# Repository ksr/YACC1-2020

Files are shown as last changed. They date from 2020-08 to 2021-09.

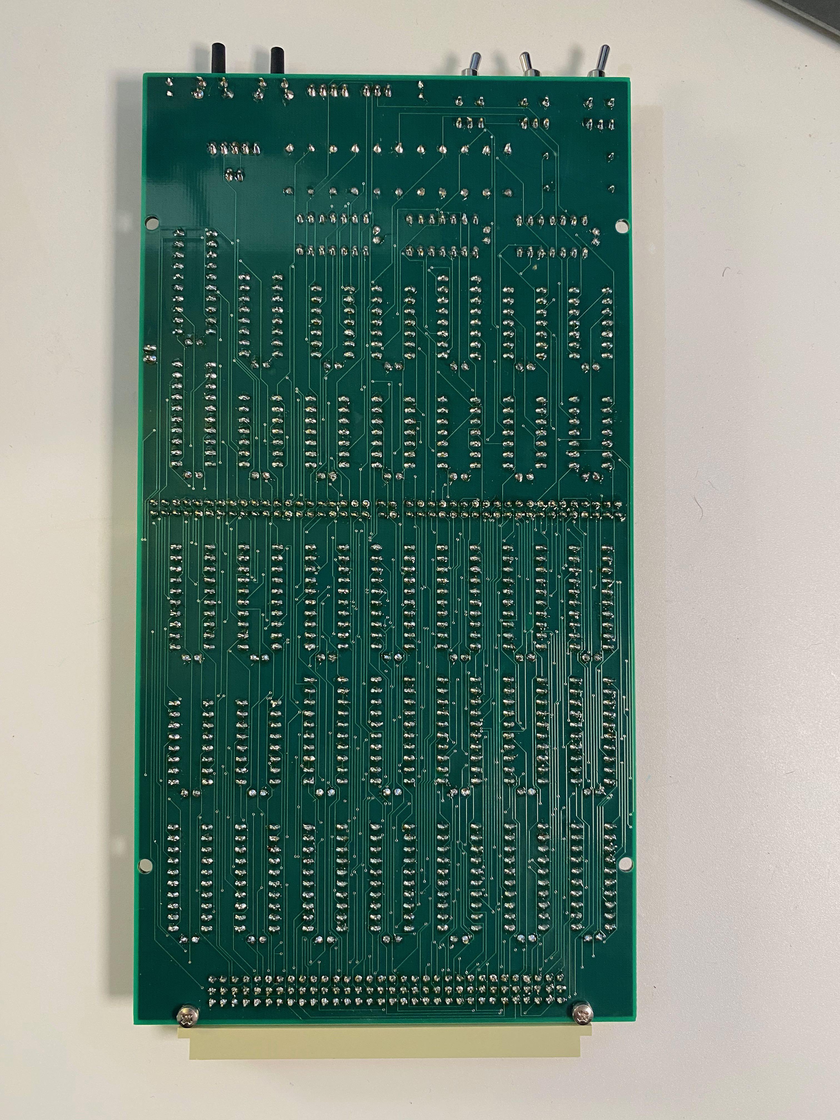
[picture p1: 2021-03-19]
Photos & Videos/sequencer logic v2.1 solder.jpeg

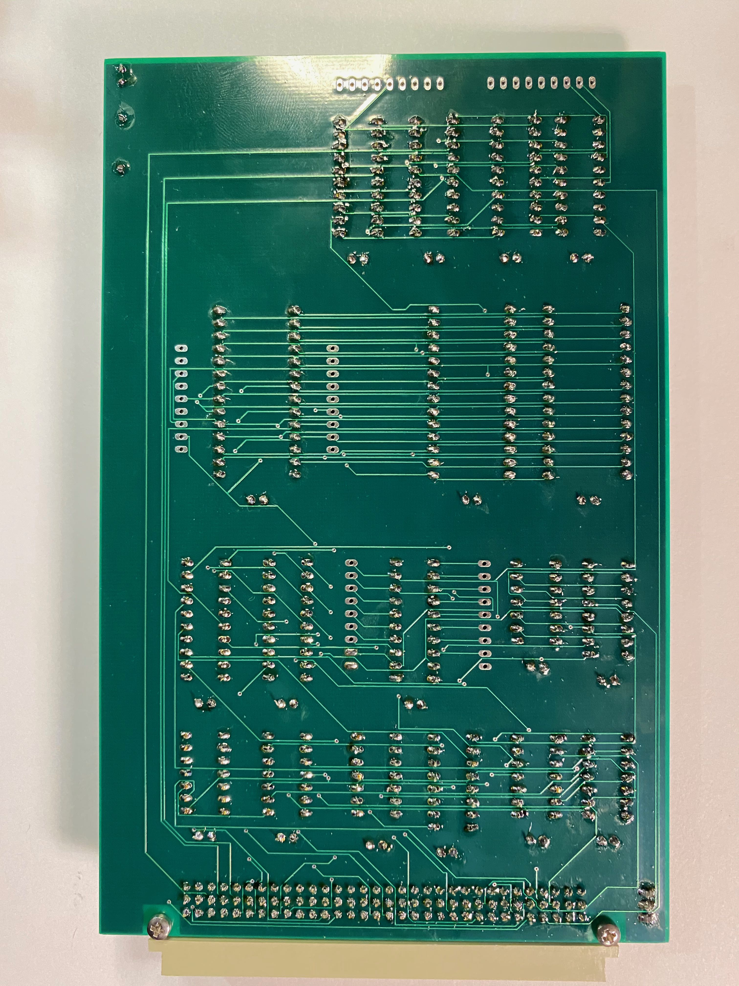
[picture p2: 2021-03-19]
Photos & Videos/memory v1.2 solder.jpeg

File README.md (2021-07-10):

# YACC1-2020 (Yet Another Custom CPU)

Finally time to try building a custom CPU from basic TTL and other "simple" ICs (no 74ls181 ALU, that would be cheating :-) ). 

The YACC1-2020, provides the tools and resources to learn computer science starting from the basics of digital logic through to a fully working custom CPU with a user defined instruction set, assembler, BASIC interpreter, and one day an operating system with filesystem, command line interpreter, and utilities.

The project is currently under development as a personal project. The basic idea has been kicking around inside my head for years (47 years to be exact), but until recently never made it to the top of my list (I did make an attempt a few years back but life got in the way). Now I am exploring if this project might be interesting to others, perhaps as an educational tool or maybe just a fun project.

Here is a [video of the machine in operation](https://youtu.be/6pjIE4_MxIA) and some photos can be found in the Photos & Videos subdirectory in this repository

The basic system is comprised of 7 cards:
- Memory card with 64k RAM and 32K ROM (total address space 64K) The memory card also contains two temporary registers
- Register card, each with 4 16-bit registers that can drive data or address bus, although the system can operate with one register card anything really useful will require two cards. The system has control lines to support upto 4 register cards for a total of 16 registers
- IO Card has serveral options; Serial RS-232, 8-bit switches, 8-bit LED, LCD
- ALU Card supports the boolean, compare, add/sub operations, and the accumulator
- Sequencer 2 card set made up of a memory card and logic card mated together (see photos)
- Optional but highly revommended Bus Test Card, this allows driving the bus in test mode and monitoring the bus in listening mode

## Motivation

Like many others, back in the mid 1970s I had the opportunity to learn both computer programming and microcomputer hardware simultaneously. For me it all started with programming BASIC on a timeshare HP machine via a terminal and/or optical hollerith cards. My math teacher who also taught computer programming allowed us to use the termoianl if we finished our work early. At home I also dabbled with digital circuits and when Popular Electronics published the COSMAC ELF project I was hooked. Now I wonder if for some students when learning computer science does the hardware seem too much like a magic box.

If this project is of intertest, perhaps your one of the following:<br/>
- High school computer science educators<br/>
- Freshman and sophomore college computer science educators<br/>
- Electronics or Retro computer enthusiast<br/>
- Or just generally interested
	
Please reach out to ken at cottageworker dot com

## Directories

### Data Sheets:
		Useful data sheets, manuals, references.
			(These are all readily available online but if I inadvertently violated copyright
			please let me know and I will remove immediately)

### General Notes:
		System wide notes, more specific notes in various subdirectories
		
### PCB:
		PCB designs, there are two different subdirectories:
			Production: These are the latest fully functioning designs, most likely currently in use
			Working - Underdevelopment: These are the newest versions of the boards in design
		Each board has or will have a "theory of operation" document
			
### Photos & Videos:
		Some sharable files

### Presentations:
		Presentations related to the YACC1-2020 project
		
### Software:
		All software related to the project, see subdirectory for more information
		
### Utilities:
		Arduino: Configuration files for Arduino code
		Clocker: External Arduino based to tool for single step debug operations
		Eagle: Configuration files for Eagle
		Waveforms: Timing diagrams for cpu instructions, probably should move to software area

### YACC1 Connector - V3.2.pdf
		Current bus connector specifications
		
<br/><br/> 
-- Thanks for taking a look --

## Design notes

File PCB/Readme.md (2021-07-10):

# PCB Files

## Production
This are the latest versions of boards ordered. That does not mean they are fully tested and working. See the notes file in each subdirectory for additional status information.

## Working - Under Development
These boards have not been ordered, they are still in a developement phase. See notes file in each subdirectory for addtional informaition

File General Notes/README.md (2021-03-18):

General notes, look in subdirectory of each PCB for board specific notes and
look in software directories for code specific notes

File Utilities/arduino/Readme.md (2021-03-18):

This file needs to placed in Arduino Library Tree

On my mac this is:

~/Documents/Arduino/libraries/YACC

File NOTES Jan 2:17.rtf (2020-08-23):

BUILD NOTES:

BUS

Original
Add method to chain card together at edge using right angle male/female 96 pin DIN connectors
Once old boards on old bus have been updates mount newer bus card on plywood
Add Power supply to plywood
Add on/off switch to above
Maybe add amp meter
Use distribution bus for power (screw terminals)

YACC2020 updates and carry forward
Built “Horizontal and Vertical” bus card connectors
Original Horizontal (Side by Side) Connector had long parallel runs close together causing crosstalk
New board designed with extra separation between traces as well as ground and vcc planes

Side by Side Now mounted on MDF
Use larger and add Power Supply to board
Add switch?
Amp measurement?
Easy access to vcc and gnd for test probes maybe trough screw terminal bus bar
Capacitors to bus boards?

ALU

Original
IC8A CARRY SHIFT Register, should it have a reset capability ?
DONE
connect CLR pin 1 to -RESET?
What about a software reset ability?
Should This be done on add/sub without carry

Any Other Status bits required?
Look at other CPU designs

IC34 Compare register
Remove test for 0 from HI data byte (8-15) and replace with INPUT line from bus
This will allow INPUT signal status line to be same as every other test

SWAP A and B lines into IC43 and IC44
First retest this logic with test card and test vectors

Incorporate existing PCB Mods

YACC2020 updates and carry forward
IC8A now IC9A CARRY SHIFT Register, should it have a reset capability ?
DONE connected CLR pin 1 to -RESET?
What about a software reset ability?
Should This be done on add/sub without carry
Not done, how else could this be achieved

Any Other Status bits required?
Look at other CPU designs

C34 Now IC26 Compare register
Remove test for 0 from HI data byte (8-15) and replace with INPUT line from bus
This will allow INPUT signal status line to be same as every other test
DONE

SWAP A and B lines into IC43 and IC44 now ic35 and IC36
First retest this logic with test card and test vectors
Done
BUT the actual change needed might be have accumulator goes to ic35 & 36 A gates and
BDATA goes to XOR gates ic33 and ic34
Might need to model all this in a simulator

Incorporate existing PCB Mods
No idea, will move forward and debug new model

SEQUENCER LOGIC

Original
IC14 Reuse U-TEST-IN
is soft reset needed or reuse?
sheet 4, cleanup logic now that testin input is gone, use br-cond only
Maybe move HALT and CONTINUE switches to TOP edge

Rename branch register to data immediate and add another 2 x 74374 for add(r?) immediate
clk into new 74374s same as ic26 and 27
output new 74374s to addr lines
Does existing 74374s need separate hi and lo read lines ???
Can one be use for existing 74374s (DATA) and other for new 74374s (ADDR)
Possible methods for I/O ADDR line
1) Reuse testin line and drive either UNUSED1 or UNUSED2 on bus
2) Is there a way to generate a pulse on UNUSED1 or 2 delayed after 74274 ADDR outputs enabled?

review front panel, new circuit, jumpers? make it easier to add single step clock

fix naming , rename -halt-cont to -fp-halt-cont

YACC2020 updates and carry forward
IC14 Reuse U-TEST-IN
sheet 4, cleanup logic now that testin input is gone, use br-cond only
Redesigned, IN is now tested in ALU and comes in on BR-COND bus line
No longer need control signal TEST-IN, setting ALU to 0x0 (all 4 bits 0) forces BR-COND to HIGH (1)

is soft reset needed or reuse?
Done - Removed

Maybe move HALT and CONTINUE switches to TOP edge
Done - Moved

Rename branch register to data immediate and add another 2 x 74374 for add(r?) immediate
No physical change required - have not changed signal names yet (seems to make sense)
Due to register redesign no need for addr immediate registers on sequencer board

New removed 1-byte-operand-select, not needed. Use 2-byte-operand-select and its inverse to select buffer to select
Remove from control signals

Does existing branch (data) 74374s need separate hi and lo read lines ???
Can one be use for existing 74374s (DATA) and other for new 74374s (ADDR)
Keeping both for safety but really may not need, lets address with a jumper so we can test and maybe remove in a future design

Possible methods for I/O ADDR line
1) Reuse testin line and drive either UNUSED1 or UNUSED2 on bus
2) Is there a way to generate a pulse on UNUSED1 or 2 delayed after 74274 ADDR outputs enabled?
Not sure waht this is about about IO-ADDR completely redesign for YACC-2020

review front panel, new circuit, jumpers? make it easier to add single step clock
Front panel connections removed
added jumper to support external off board single step clock

fix naming , rename -halt-cont to -fp-halt-cont
Done

SEQUENCER MEMORY

Original
Fixes re PCB Mods
Move CPU reset to top edge of board

YACC2020 updates and carry forward
Fixes re PCB Mods
Redesign so changes not done or carried forward. Most changes looked like addition or reuse control lines

Move CPU reset to top edge of board
Done

SP/PC

Original
Now called ??? ADDR/INDEX/GP
DONE:
USES 7400 NAND (NOT AND) for gating UP/DN signals for counters
UP/DOWN count on rising edge but other line must be high
Example to count up, DOWN line held high, pulse UP by setting/clearing SP/PC-UP - this will appear as low then high at counter pin
DONE:
Front Panel wiring CAREFUL CHECK numbering scheme for RxDx lines from counter chips

DONE:
update sheet 5 to match logic test
DONE:
Arrange so board select can either be driven from unused 1 to become 3rd addr-reg signal or gnd
MAYBE use unused line to add another address line for a 2nd card???

YACC2020 updates and carry forward
This board is no longer used

REGISTER BOARD

Original
Now called DATA REGISTER CARD
incorporate mods to board and verify changes to production design in ‘mods’ DIRECTORY

TBD RESEARCH
Interrupt Line: Should this be open collector with pull down and or up
Input Line: Should this be open collector with pull down and/or up

Should tmp register be on sequencer card or not exist at all
This would free up two bus lines although the bottleneck is still the number of control signals in sequencer connector

YACC2020 updates and carry forward
Big redesign - Card no longer has address bus section

ADDRESS & TMP REGISTER BOARD

Original
New Card

YACC2020 updates and carry forward
New Card

MEMORY CARD -

Original
BASIC
How to get info into card ?? Using Front Panel ??

FULL
How many ram chips
Best case 1 x 64k x 8
Worst case 8 x 8k x 8

1 4k eprom
eprom mapping circuit
On reset EPROM is mapped into 0x0000
all memory access goes to EPROM
first access to location with addr 15 set (HIGH)
remaps EPROM to 0xFxxx
RAM is mapped to 0x0000
Accomplished by first EPROM code BRANCH to 0XF003 (BRANCH instruction is 3 bytes)

YACC2020 updates and carry forward
New Card

2 - 32k x 8 bit ram chips

eprom mapping circuit
On reset EPROM is mapped into 0x0000
all memory access goes to EPROM
first access to location with addr 15 set (HIGH)
remaps EPROM to 0xFxxx
RAM is mapped to 0x0000
Accomplished by first EPROM code BRANCH to 0XF003 (BRANCH instruction is 3 bytes)

I/O CARD

Original
New Card

YACC2020 updates and carry forward
New Card
8 toggle swtiches and LEDS
OUT LED
IN Switch
TIL 311 output - tied to LEDS (should this be separate cantle)
2x20 LCD panel
16550 UART based serial IO

Design Changes (from old file) Incorporate into above info
This section was ignored for YACC-2020

1) Remove address latch register from register file
recover bus pins & men control pins
update 1.2 bus definition
on definition
cards in progress or prod

2) add temp 8 bit latch to sequencer card to facilitate mem to mem transfer

3) convert reg card to 8 registers
modify bus definition to 3 bits register select, 1 bit board select
modify bus definition + all cords in process

4) Reduce to 8 registers only, jumper to hold the now 1 bit board select to 0
maybe add jumpers so reg selection is 3 bit, tie upper bit to 0

5) TESTER Board
probably (almost for sure) do not need individual pull-ups for CNTL chips

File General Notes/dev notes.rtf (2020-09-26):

Verify opcode using putBusAtMemReg
removed clear -vma

Add halt indicator led to sequencer board
Expose code-counter-reset either on bus or as a pin to support external clock control

Memory

Add leds for each of 3 chips CS

Add keyhole optimizer looking for duplicate lines in micro code

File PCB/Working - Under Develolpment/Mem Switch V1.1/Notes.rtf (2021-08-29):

Version 1.0

Works
Missing bypass caps for address selection logic
Change to 74240 (inverted output)
Rotate switches (on up)

Add leds per address byte ?
Add additional address selection to locate with 16 byte blocks ?

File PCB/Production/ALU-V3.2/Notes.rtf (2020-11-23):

Changes since production of ALU-V3.0

Next version V3.2 - OFF TO PRODUCTION

Signal IN and OUT converted from active low to Active HI (Done on Schematic)

BUS changed UNUSED -VMA (not used by ALU) (Done on Schematic)

Should Pin 7 of IC 26 be connected to -ALU-FUNC ?
Added Jumper to address either scenario (Done on Schematic)

Looks like change ic10 DIR driven form -AC-RD instead if inverse if -AC-LD (NOT DONE in Schematic) Mod done on current board - done

Board mod D0 D7 shift register (may not be needed)

See Page 3 - BUS Direction change

Page 6 - Should IC28 data inputs d0/d7 be connected to accumulator or shift register
Current board has this partially implemented for pin 5 and 11 - prod has this mod

28/5 - 30-12
28-11 - 29-15

Retest Shift register functionality

Retest Carry/Shift register

How to clear carry shift? - ADD INSTRUCTION

Test SUBT

Ic6 pin 10 - -ac-ld or ac-ld - added jumper - should be ac-ld

IC32 flipped pins 4 and 5

Flipped AC and BDATA for add/sub circuit
BDATA now goes into xor array
AC directly into adders

Added gating so CO/BO is anded with -ADD/SUB so CO/BO only can go high during add/sub

NEXT VERSION 3.3

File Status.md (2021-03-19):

# Highlevel project status & work to be done. Additional detail within the various subdirectories

## Memory Card
Add 4k block select for Hi Ram and Rom both located at 0x8000 to 0xFFFF.<br/>
This will allow mapping any 4k block of either RAM or ROM to be mapped in or out of the address space and
allow memory blocks from devices such as a video card to be mapped into the address space.
Currernly the upper 4k of ROM 0XF000-0XFFFF is forced into address space at 0x0000 upon reset and
is mapped back to 0XF000-0XFFFF after first access, this behavior will continue.

## Sequencer Memory Card
Add second 512k EEPROM

## All Cards
Cleanup chip labeling to follow a standard grid<br/> and ic/discrete labels postion and font.

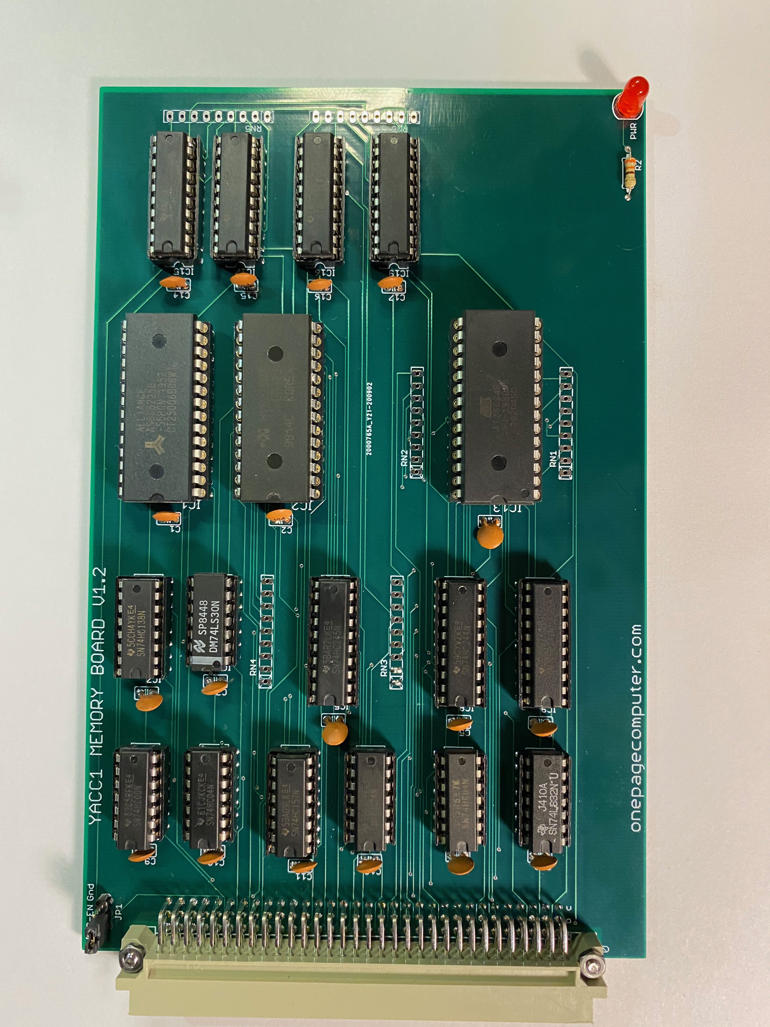
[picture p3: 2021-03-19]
Photos & Videos/memory v1.2 top.jpeg

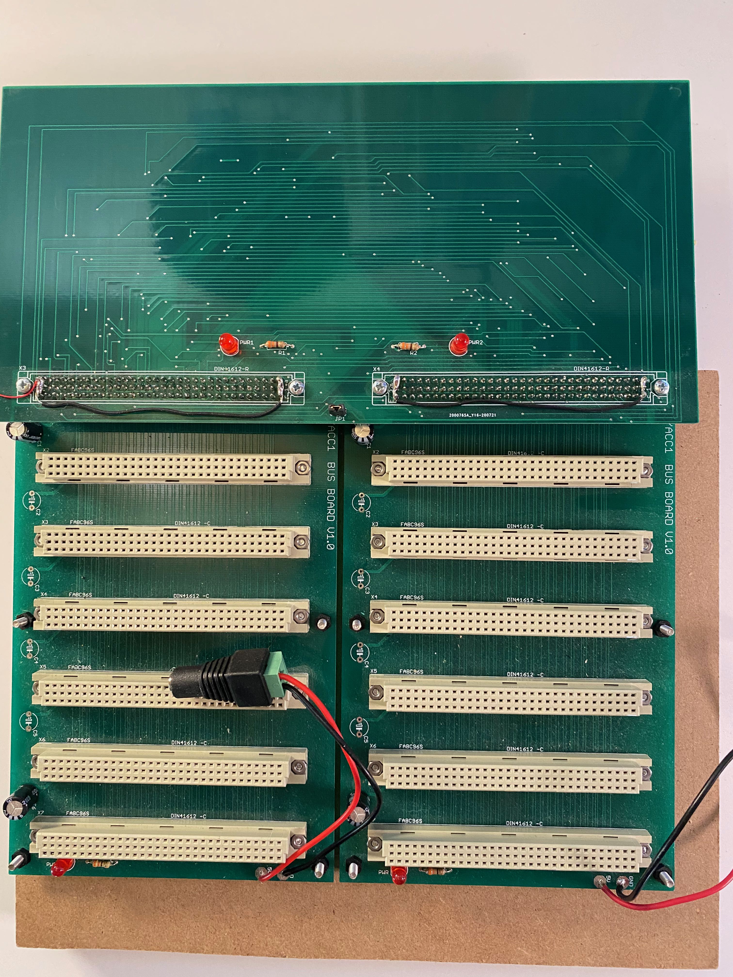
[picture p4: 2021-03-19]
Photos & Videos/double bus.jpeg

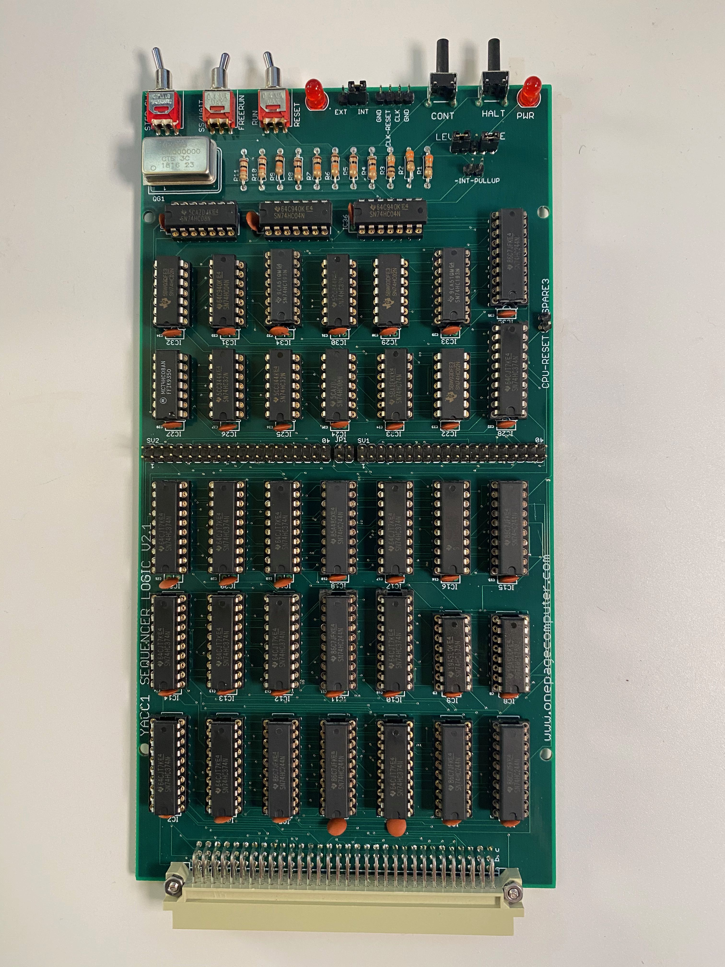
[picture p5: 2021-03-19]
Photos & Videos/sequencer logic v2.1 top.jpeg

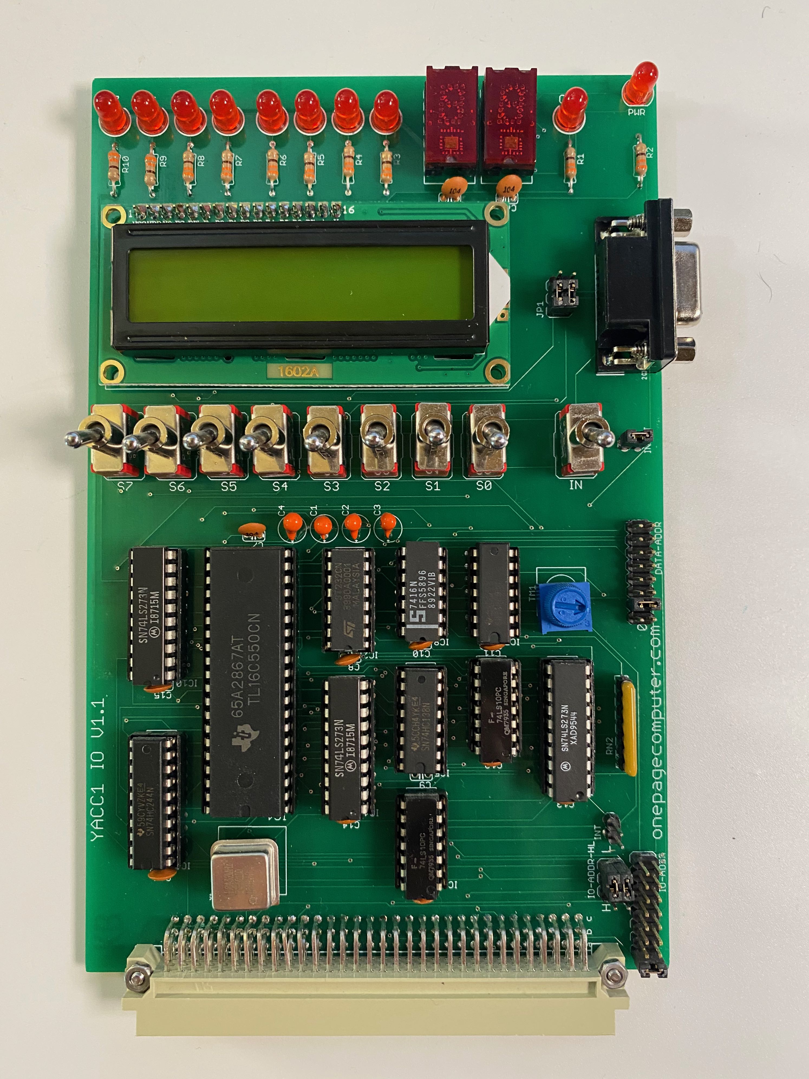
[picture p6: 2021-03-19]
Photos & Videos/io v1.1 top.jpeg

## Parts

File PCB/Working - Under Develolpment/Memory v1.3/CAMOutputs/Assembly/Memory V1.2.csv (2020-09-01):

Qty | Value | Device | Package | Parts | Description | MF | MPN | OC_FARNELL | OC_NEWARK | POPULARITY | SPICEMODEL | SPICEPREFIX
1 |  | 28C64C | DIL28-6 | IC13 | MEMORY |  | AT28C64B-15PU | 1095784 | 96K6557
2 |  | 62256P | DIL28-6 | IC1, IC2 | MEMORY |  |  | unknown | unknown | 1
18 |  | C-US025-025X050 | C025-025X050 | C1, C2, C3, C4, C5, C6, C7, C8, C9, C10, C11, C12, C13, C14, C15, C16, C17, C18 | CAPACITOR, American symbol
1 |  | LED5MM | LED5MM | PWR | LED
1 |  | PINHD-1X3 | 1X03 | JP1 | PIN HEADER |  |  |  |  | 92
6 |  | RNX8 | RN-9 | RN1, RN2, RN3, RN4, RN5, RN6 | RESISTOR NETWORK |  |  | unknown | unknown | 0
1 | 330 | R0207/10 | 0207/10 | R2 | RESISTOR, European symbol |  |  |  |  |  | NONE | R
1 | 74ALS00N | 74ALS00N | DIL14 | IC10 | Quad 2-input NAND gate |  |  |  |  | 0
1 | 74ALS30N | 74ALS30N | DIL14 | IC4 | 8-input NAND gate |  |  |  |  | 0
2 | 74LS04N | 74LS04N | DIL14 | IC6, IC14 | Hex INVERTER |  |  |  |  | 0
1 | 74LS138N | 74LS138N | DIL16 | IC7 | 3-line to 8-line DECODER/DEMULTIPLEXER |  |  |  |  | 7
1 | 74LS157N | 74LS157N | DIL16 | IC11 | Quadruple 2-line to 1-line data SELECTOR/MULTIPLEXER |  |  |  |  | 0
2 | 74LS244N | 74LS244N | DIL20 | IC8, IC9 | Octal BUFFER and LINE DRIVER, 3-state |  |  |  |  | 0
1 | 74LS245N | 74LS245N | DIL20 | IC5 | Octal BUS TRANSCEIVER, 3-state
1 | 74LS32N | 74LS32N | DIL14 | IC3 | Quad 2-input OR gate |  |  |  |  | 9
4 | 74LS374N | 74LS374N | DIL20 | IC15, IC16, IC17, IC19 | Octal D type transparent LATCH, edge triggered |  |  |  |  | 0
1 | 74LS74N | 74LS74N | DIL14 | IC12 | Dual D type positive edge triggered FLIP FLOP, preset and clear |  |  |  |  | 0
1 | FABC96R | FABC96R | FABC96R | X1 | CONNECTOR female, 96 pins, type R, rows ABC, grid 2.54 mm

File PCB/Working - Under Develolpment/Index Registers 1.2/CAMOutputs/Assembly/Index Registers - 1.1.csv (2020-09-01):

Qty | Value | Device | Package | Parts | Description | MF | MPN | OC_FARNELL | OC_NEWARK | POPULARITY | SPICEMODEL | SPICEPREFIX
1 |  | LED5MM | LED5MM | PWR | LED
3 |  | M04X2 | 2X4 | J1, J2, J3 | .1 header, two rows of four."
47 | 0.1 | C-US025-040X050 | C025-040X050 | C1, C2, C3, C4, C5, C6, C7, C8, C9, C10, C11, C12, C13, C14, C15, C16, C17, C18, C19, C20, C21, C22, C23, C24, C25, C26, C27, C28, C29, C30, C31, C32, C33, C34, C35, C36, C37, C38, C39, C40, C41, C42, C43, C44, C45, C46, C47 | CAPACITOR, American symbol
2 | 10k | RNX8 | RN-9 | RN1, RN2 | RESISTOR NETWORK |  |  | unknown | unknown
1 | 330 | R0207/10 | 0207/10 | R1 | RESISTOR, European symbol |  |  |  |  |  | NONE | R
1 | 4077N | 4077N | DIL14 | IC34 | Quad XNOR |  |  |  |  | 0
3 | 74LS139N | 74LS139N | DIL16 | IC32, IC33, IC38 | Dual 2-line to 4-line DECODER/DEMULTIPLEXER |  |  |  |  | 0
16 | 74LS192N | 74LS192N | DIL16 | IC3, IC4, IC5, IC6, IC9, IC10, IC11, IC12, IC19, IC20, IC21, IC22, IC29, IC30, IC43, IC44 | Synchronous 4-bit UP/DOWN COUNTER
8 | 74LS244N | 74LS244N | DIL20 | IC17, IC18, IC27, IC28, IC41, IC42, IC49, IC50 | Octal BUFFER and LINE DRIVER, 3-state |  |  |  |  | 0
8 | 74LS244N | 74LS244N | DIL20 | IC7, IC8, IC13, IC14, IC23, IC24, IC45, IC46 | Octal BUFFER and LINE DRIVER, 3-state
3 | 74LS245N | 74LS245N | DIL20 | IC35, IC36, IC37 | Octal BUS TRANSCEIVER, 3-state
8 | 74LS32N | 74LS32N | DIL14 | IC1, IC2, IC15, IC25, IC26, IC31, IC40, IC47 | Quad 2-input OR gate |  |  |  |  | 9
1 | FABC96R | FABC96R | FABC96R | X1 | CONNECTOR female, 96 pins, type R, rows ABC, grid 2.54 mm

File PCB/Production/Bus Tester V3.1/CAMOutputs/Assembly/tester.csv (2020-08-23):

Qty | Value | Device | Package | Parts | Description | MF | MPN | OC_FARNELL | OC_NEWARK | POPULARITY | SPICEMODEL | SPICEPREFIX | VALUE
2 |  | 9070-1W | 9070-1W | S-A, S-B | TOGGLE SWITCH
2 |  | JP1E | JP1 | DTR-RESET, FTDI-VCC | JUMPER
15 |  | LED5MM | LED5MM | L0, L1, L2, L3, L4, L5, L6, L7, LED1, LED2, LED3, LED4, LED5, OUT, PWR | LED
9 |  | M9040P | M9040P | IN, S0, S1, S2, S3, S4, S5, S6, S7 | TOGGLE SWITCH
2 |  | PINHD-1X3 | 1X03 | -BUS-EN, -RESET | PIN HEADER |  |  |  |  | 92
1 |  | PINHD-1X3 | 1X03 | JP2 | PIN HEADER
4 |  | RNX8 | RN-9 | RN1, RN2, RN3, RN4 | RESISTOR NETWORK |  |  | unknown | unknown
22 | 0.1 | C-US025-024X044 | C025-024X044 | C1, C2, C3, C4, C5, C8, C9, C10, C11, C12, C13, C14, C15, C16, C17, C18, C19, C20, C21, C22, C23, C24 | CAPACITOR, American symbol
8 | 10k | R-US_0207/10 | 0207/10 | R2, R3, R4, R5, R6, R7, R8, R25 | RESISTOR, American symbol
1 | 16Mhz | CRYSTALHC49S | HC49/S | Q1 | CRYSTAL |  |  | 1667008 | unknown
2 | 2.2k | R-US_0207/10 | 0207/10 | R10, R12 | RESISTOR, American symbol
2 | 20pf | C-US025-024X044 | C025-024X044 | C6, C7 | CAPACITOR, American symbol
1 | 24AA01P | 24AA01P | DIL8 | IC7 | Serial EEPROM |  | 24AA01-I/P | 1331266 | 35M0692
14 | 330 | R-US_0207/10 | 0207/10 | R9, R11, R13, R14, R15, R16, R17, R18, R19, R20, R21, R22, R23, R24 | RESISTOR, American symbol
1 | 330 | R0207/10 | 0207/10 | R1 | RESISTOR, European symbol |  |  |  |  |  | NONE | R
1 | 74LS244N | 74LS244N | DIL20 | IC9 | Octal BUFFER and LINE DRIVER, 3-state
11 | 74LS373N | 74LS373N | DIL20 | IC11, IC12, IC13, IC14, IC15, IC16, IC17, IC18, IC19, IC20, IC21 | Octal D type transparent LATCH, edge triggered |  |  |  |  | 0
1 | 74LS374N | 74LS374N | DIL20 | IC8 | Octal D type transparent LATCH, edge triggered
1 | ATMEGA328P_PDIP | ATMEGA328P_PDIP | DIL28-3 | IC10 | uC used in the Arduino
1 | FABC96R | FABC96R | FABC96R | X1 | CONNECTOR female, 96 pins, type R, rows ABC, grid 2.54 mm
1 | FTDI_DEVICE | FTDI_DEVICE | FTDI_DEVICE_SIDE | JP1 | Connector which mates to FTDI basic or FTDI cable.
6 | MCP23017SP | MCP23017SP | DIL28-3 | IC1, IC2, IC3, IC4, IC5, IC6 | http://ww1.microchip.com/downloads/en/DeviceDoc/21952a.pdf | MICROCHIP | MCP23017-E/SP | 1332088 | 31K2959
1 | SWITCH-MOMENTARY-2SIDE_EZ | SWITCH-MOMENTARY-2SIDE_EZ | TACTILE-PTH-SIDEEZ | SOFT-RESET | Various NO switches- pushbuttons, reed, etc
1 | TS-1109-7 | DIP-BUTTON-TOP-BLACK(4P-D6.2MM) | SW4-6.2X6.2X5.0MM | CPU-RESET | 311020032 |  | TS-1109-7 |  |  |  |  |  | TS-1109-7

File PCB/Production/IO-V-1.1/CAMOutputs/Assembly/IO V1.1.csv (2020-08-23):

Qty | Value | Device | Package | Parts | Description | CATEGORY | CREATED_BY | DESCRIPTION | DIGIKEY_PART_NUMBER | MANUFACTURER | MF | MPN | OC_FARNELL | OC_NEWARK | OPERATING_TEMP | PACKAGE | PART_STATUS | POPULARITY | PROD_ID | ROHS_COMPLIANT | SERIES | SPICEMODEL | SPICEPREFIX | SUB-CATEGORY | THERMALLOSS | TYPE
13 |  | C-US025-024X044 | C025-024X044 | C5, C6, C7, C8, C9, C10, C11, C12, C13, C14, C15, C16, C17 | CAPACITOR, American symbol
4 |  | CPOL-USE2,5-6E | E2,5-6E | C1, C2, C3, C4 | POLARIZED CAPACITOR, American symbol |  |  |  |  |  |  |  |  |  |  |  |  | 1 |  |  |  |  | C
1 |  | DB9FEMALE | DB9 | J1 | DB9 Connector |  |  |  |  |  |  |  |  |  |  |  |  |  | CONN-08194
10 |  | LED5MM | LED5MM | 0, 1, 2, 3, 4, 5, 6, 7, OUT, PWR | LED
9 |  | M9040P | M9040P | IN, S0, S1, S2, S3, S4, S5, S6, S7 | TOGGLE SWITCH |  |  |  |  |  |  |  |  |  |  |  |  | 0
2 |  | PINHD-1X2 | 1X02 | INPUT, INT | PIN HEADER |  |  |  |  |  |  |  |  |  |  |  |  | 98
1 |  | PINHD-2X3 | 2X03 | IO-ADDR-HL | PIN HEADER |  |  |  |  |  |  |  |  |  |  |  |  | 62
2 |  | PINHD-2X8 | 2X08 | DATA-ADDR, IO-ADDR | PIN HEADER |  |  |  |  |  |  |  |  |  |  |  |  | 6
9 |  | R-US_0207/10 | 0207/10 | R1, R3, R4, R5, R6, R7, R8, R9, R10 | RESISTOR, American symbol |  |  |  |  |  |  |  |  |  |  |  |  | 36 |  |  |  |  | R
1 |  | RNX6 | RN-7 | RN2 | RESISTOR NETWORK |  |  |  |  |  |  |  | unknown | unknown |  |  |  | 0
1 |  | XR-16C550P | DIL40 | IC1 | UART/FIFO |  |  |  |  |  |  | ST16C450CP40 | 1294801 | 24R1445 |  |  |  | 0
1 | 10k | TRIMPOT3386 | TRIM-3386 | TM1 | SMT trimmer potentiometer part number TC33X
1 | 330 | R0207/10 | 0207/10 | R2 | RESISTOR, European symbol |  |  |  |  |  |  |  |  |  |  |  |  |  |  |  |  | NONE | R
3 | 74273N | 74273N | DIL20 | IC4, IC9, IC10 | Octal D type FLIP FLOP, clear |  |  |  |  |  |  |  |  |  |  |  |  | 3
1 | 74LS00N | 74LS00N | DIL14 | IC7 | Quad 2-input NAND gate |  |  |  |  |  |  |  |  |  |  |  |  | 4
1 | 74LS06N | 74LS06N | DIL14 | IC8 | Hex INVERTER, open collector high-voltage output |  |  |  |  |  |  |  |  |  |  |  |  | 0
2 | 74LS10N | 74LS10N | DIL14 | IC6, IC11 | Triple 3-input NAND gate |  |  |  |  |  |  |  |  |  |  |  |  | 0
1 | 74LS138N | 74LS138N | DIL16 | IC5 | 3-line to 8-line DECODER/DEMULTIPLEXER |  |  |  |  |  |  |  |  |  |  |  |  | 7
1 | 74LS244N | 74LS244N | DIL20 | IC3 | Octal BUFFER and LINE DRIVER, 3-state |  |  |  |  |  |  |  |  |  |  |  |  | 0
1 | ECS-2100AX-200 | ECS-2100AX-200 | ECS-2100AX-200 | Y1 | XTAL OSC XO 20.0000MHZ HCMOS TTL |  | PCBLayout.com |  | X964-ND | ECS Inc. |  | ECS-2100AX-200 |  |  |  | 8-DIP
1 | FABC96R | FABC96R | FABC96R | X1 | CONNECTOR female, 96 pins, type R, rows ABC, grid 2.54 mm
1 | HD44780LCD-1602 | HD44780LCD-1602 | LCD1602 | X2 | HD44780 LCD
2 | HTIL311A | HTIL311A | HTIL311A | HI, LO | LED DISPLAY 1-character dot matrix, 2 decimal points |  |  |  |  |  |  |  | unknown | unknown |  |  |  | 0
1 | MAX232 | MAX232 | DIL16 | IC2 | RS232 TRANSCEIVER |  |  |  |  |  | MAXIM | MAX232ACPE+ | 9723773 | 68K4544 |  |  |  | 0
1 | PINHD-2X3 | PINHD-2X3 | 2X03 | JP1 | PIN HEADER | CONNECTOR |  |  |  |  |  |  |  |  |  |  |  |  |  |  |  |  |  | PIN-HEADER

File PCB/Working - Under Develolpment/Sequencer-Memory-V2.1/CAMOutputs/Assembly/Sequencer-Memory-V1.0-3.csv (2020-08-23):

Qty | Value | Device | Package | Parts | Description | MF | MPN | OC_FARNELL | OC_NEWARK | POPULARITY | SPICEMODEL | SPICEPREFIX | VALUE
8 |  | 6264A | DIL28-6 | IC1, IC2, IC3, IC4, IC5, IC6, IC7, IC8 | MEMORY |  |  | 283605 | unknown
1 |  | 9070-1W | 9070-1W | UCODE | TOGGLE SWITCH
2 |  | JP1E | JP1 | DTR-RESET, FTDI-VCC | JUMPER
1 |  | JP5QE | JP5Q | ROM | JUMPER
4 |  | LED5MM | LED5MM | FAULT, LOADING, PWR1, READY | LED
2 |  | MA20-2 | MA20-2 | SV1, SV3 | PIN HEADER |  |  | unknown | unknown
1 |  | PINHD-1X3 | 1X03 | JP4 | PIN HEADER
1 |  | PINHD-2X2 | 2X02 | JP1 | PIN HEADER |  |  |  |  | 0
16 | 0.1 | C-US025-024X044 | C025-024X044 | C2, C3, C4, C5, C6, C13, C14, C15, C16, C17, C18, C19, C20, C21, C22, C23 | CAPACITOR, American symbol
3 | 10k | R-US_0207/10 | 0207/10 | R3, R8, R25 | RESISTOR, American symbol
1 | 16Mhz | CRYSTALHC49S | HC49/S | Q1 | CRYSTAL |  |  | 1667008 | unknown
2 | 2.2k | R-US_0207/10 | 0207/10 | R5, R12 | RESISTOR, American symbol
2 | 20pf | C-US025-024X044 | C025-024X044 | C11, C12 | CAPACITOR, American symbol
1 | 24AA01P | 24AA01P | DIL8 | IC9 | Serial EEPROM |  | 24AA01-I/P | 1331266 | 35M0692
3 | 330 | R-US_0207/10 | 0207/10 | R6, R11, R16 | RESISTOR, American symbol
1 | 330 | R0207/10 | 0207/10 | R1 | RESISTOR, European symbol |  |  |  |  |  | NONE | R
1 | ATMEGA328P_PDIP | ATMEGA328P_PDIP | DIL28-3 | IC10 | uC used in the Arduino
1 | FTDI_DEVICE | FTDI_DEVICE | FTDI_DEVICE_SIDE | JP3 | Connector which mates to FTDI basic or FTDI cable.
5 | MCP23017SP | MCP23017SP | DIL28-3 | IC1-5, IC11, IC12, IC13, IC14 | http://ww1.microchip.com/downloads/en/DeviceDoc/21952a.pdf | MICROCHIP | MCP23017-E/SP | 1332088 | 31K2959
1 | SWITCH-MOMENTARY-2SIDE_EZ | SWITCH-MOMENTARY-2SIDE_EZ | TACTILE-PTH-SIDEEZ | START | Various NO switches- pushbuttons, reed, etc
1 | TS-1109-7 | DIP-BUTTON-TOP-BLACK(4P-D6.2MM) | SW4-6.2X6.2X5.0MM | CPU-RESET | 311020032 |  | TS-1109-7 |  |  |  |  |  | TS-1109-7

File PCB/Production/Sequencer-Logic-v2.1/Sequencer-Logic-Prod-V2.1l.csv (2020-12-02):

Qty | Value | Device | Package | Parts | Description | CATEGORY | DESCRIPTION | MANUFACTURER | MF | MPN | OC_FARNELL | OC_NEWARK | OPERATING_TEMP | PART_STATUS | POPULARITY | ROHS_COMPLIANT | SERIES | SPICEMODEL | SPICEPREFIX | SUB-CATEGORY | THERMALLOSS | TYPE
3 |  | 9070-1W | 9070-1W | RESET, SS/WAIT, STEP-CLK | TOGGLE SWITCH
1 |  | LED5MM | LED5MM | PWR | LED
2 |  | MA20-2 | MA20-2 | SV1, SV2 | PIN HEADER |  |  |  |  |  | unknown | unknown
1 |  | PINHD-1X2 | 1X02 | -INT-PULLUP | PIN HEADER |  |  |  |  |  |  |  |  |  | 98
1 |  | PINHD-1X3 | 1X03 | SS-SEL | PIN HEADER |  |  |  |  |  |  |  |  |  | 92
1 |  | PINHD-1X5 | 1X05 | JP3 | PIN HEADER
1 |  | PINHD-2X2 | 2X02 | JP1 | PIN HEADER |  |  |  |  |  |  |  |  |  | 0
1 |  | XO-14 | DIL14S | QG1 | CRYSTAL |  |  |  |  |  | unknown | unknown
38 | .1 | CAPEZ | CAP-PTH-SMALLEZ | C1, C2, C3, C4, C5, C6, C7, C8, C9, C10, C11, C12, C13, C14, C15, C16, C17, C18, C19, C20, C21, C22, C23, C24, C25, C26, C27, C28, C29, C30, C31, C32, C33, C34, C35, C36, C37, C38 | Capacitor
10 | 10k | R-US_0207/10 | 0207/10 | R1, R3, R4, R5, R6, R7, R8, R9, R10, R11 | RESISTOR, American symbol
1 | 330 | R0207/10 | 0207/10 | R2 | RESISTOR, European symbol |  |  |  |  |  |  |  |  |  |  |  |  | NONE | R
3 | 74ALS02N | 74ALS02N | DIL14 | IC22, IC29, IC32 | Quad 2-input NOR gate
3 | 74LS04N | 74LS04N | DIL14 | IC31, IC36, IC37 | Hex INVERTER
3 | 74LS08N | 74LS08N | DIL14 | IC24, IC27, IC38 | Quad 2-input AND gate
2 | 74LS175N | 74LS175N | DIL16 | IC8, IC9 | Qadruple D type FLIP FLOP, clear
2 | 74LS192N | 74LS192N | DIL16 | IC33, IC34 | Synchronous 4-bit UP/DOWN COUNTER
8 | 74LS244N | 74LS244N | DIL20 | IC1, IC2, IC4, IC5, IC11, IC15, IC18, IC35 | Octal BUFFER and LINE DRIVER, 3-state
3 | 74LS32N | 74LS32N | DIL14 | IC25, IC26, IC30 | Quad 2-input OR gate
13 | 74LS374N | 74LS374N | DIL20 | IC3, IC6, IC7, IC10, IC12, IC13, IC14, IC16, IC17, IC19, IC20, IC21, IC28 | Octal D type transparent LATCH, edge triggered
1 | 74LS74N | 74LS74N | DIL14 | IC23 | Dual D type positive edge triggered FLIP FLOP, preset and clear
1 | FABC96R | FABC96R | FABC96R | X1 | CONNECTOR female, 96 pins, type R, rows ABC, grid 2.54 mm
1 | OUT | LED5MM | LED5MM | . | LED
1 | PINHD-1X2 | PINHD-1X2 | 1X02 | JP2 | PIN HEADER | CONNECTOR |  |  |  |  |  |  |  |  |  |  |  |  |  | PIN-HEADER
1 | PINHD-1X4 | PINHD-1X4 | 1X04 | JP4 | PIN HEADER | CONNECTOR |  |  |  |  |  |  |  |  |  |  |  |  |  | PIN-HEADER
2 | SWITCH-MOMENTARY-2SIDE_EZ | SWITCH-MOMENTARY-2SIDE_EZ | TACTILE-PTH-SIDEEZ | CONT, HALT | Various NO switches- pushbuttons, reed, etc

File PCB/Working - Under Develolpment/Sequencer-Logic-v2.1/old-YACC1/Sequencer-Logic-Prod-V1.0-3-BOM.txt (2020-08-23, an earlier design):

Partlist exported from /Users/ken/Library/Mobile Documents/com~apple~CloudDocs/YACC1A/Working/Sequencer-Logic-v1.0/Sequencer-Logic-Prod-V1.0-3.sch at 10/13/16 9:35 PM

Part     Value                     Device                    Package            Description                                                                                                                                                                                                                                                                                                                                                                                                                                                                                                                      MF MPN OC_FARNELL OC_NEWARK SPICEMODEL SPICEPREFIX
.        OUT                       LED5MM                    LED5MM             LED                                                                                                                                                                                                                                                                                                                                                                                                                                                                                                                                                                                
C1       .1                        CAPEZ                     CAP-PTH-SMALLEZ    Capacitor                                                                                                                                                                                                                                                                                                                                                                                                                                                                                                                                                                          
C2       .1                        CAPEZ                     CAP-PTH-SMALLEZ    Capacitor                                                                                                                                                                                                                                                                                                                                                                                                                                                                                                                                                                          
C3       .1                        CAPEZ                     CAP-PTH-SMALLEZ    Capacitor                                                                                                                                                                                                                                                                                                                                                                                                                                                                                                                                                                          
C4       .1                        CAPEZ                     CAP-PTH-SMALLEZ    Capacitor                                                                                                                                                                                                                                                                                                                                                                                                                                                                                                                                                                          
C5       .1                        CAPEZ                     CAP-PTH-SMALLEZ    Capacitor                                                                                                                                                                                                                                                                                                                                                                                                                                                                                                                                                                          
C6       .1                        CAPEZ                     CAP-PTH-SMALLEZ    Capacitor                                                                                                                                                                                                                                                                                                                                                                                                                                                                                                                                                                          
C7       .1                        CAPEZ                     CAP-PTH-SMALLEZ    Capacitor                                                                                                                                                                                                                                                                                                                                                                                                                                                                                                                                                                          
C8       .1                        CAPEZ                     CAP-PTH-SMALLEZ    Capacitor                                                                                                                                                                                                                                                                                                                                                                                                                                                                                                                                                                          
C9       .1                        CAPEZ                     CAP-PTH-SMALLEZ    Capacitor                                                                                                                                                                                                                                                                                                                                                                                                                                                                                                                                                                          
C10      .1                        CAPEZ                     CAP-PTH-SMALLEZ    Capacitor                                                                                                                                                                                                                                                                                                                                                                                                                                                                                                                                                                          
C11      .1                        CAPEZ                     CAP-PTH-SMALLEZ    Capacitor                                                                                                                                                                                                                                                                                                                                                                                                                                                                                                                                                                          
C12      .1                        CAPEZ                     CAP-PTH-SMALLEZ    Capacitor                                                                                                                                                                                                                                                                                                                                                                                                                                                                                                                                                                          
C13      .1                        CAPEZ                     CAP-PTH-SMALLEZ    Capacitor                                                                                                                                                                                                                                                                                                                                                                                                                                                                                                                                                                          
C14      .1                        CAPEZ                     CAP-PTH-SMALLEZ    Capacitor                                                                                                                                                                                                                                                                                                                                                                                                                                                                                                                                                                          
C15      .1                        CAPEZ                     CAP-PTH-SMALLEZ    Capacitor                                                                                                                                                                                                                                                                                                                                                                                                                                                                                                                                                                          
C16      .1                        CAPEZ                     CAP-PTH-SMALLEZ    Capacitor                                                                                                                                                                                                                                                                                                                                                                                                                                                                                                                                                                          
C17      .1                        CAPEZ                     CAP-PTH-SMALLEZ    Capacitor                                                                                                                                                                                                                                                                                                                                                                                                                                                                                                                                                                          
C18      .1                        CAPEZ                     CAP-PTH-SMALLEZ    Capacitor                                                                                                                                                                                                                                                                                                                                                                                                                                                                                                                                                                          
C19      .1                        CAPEZ                     CAP-PTH-SMALLEZ    Capacitor                                                                                                                                                                                                                                                                                                                                                                                                                                                                                                                                                                          
C20      .1                        CAPEZ                     CAP-PTH-SMALLEZ    Capacitor                                                                                                                                                                                                                                                                                                                                                                                                                                                                                                                                                                          
C21      .1                        CAPEZ                     CAP-PTH-SMALLEZ    Capacitor                                                                                                                                                                                                                                                                                                                                                                                                                                                                                                                                                                          
C22      .1                        CAPEZ                     CAP-PTH-SMALLEZ    Capacitor                                                                                                                                                                                                                                                                                                                                                                                                                                                                                                                                                                          
C23      .1                        CAPEZ                     CAP-PTH-SMALLEZ    Capacitor                                                                                                                                                                                                                                                                                                                                                                                                                                                                                                                                                                          
C24      .1                        CAPEZ                     CAP-PTH-SMALLEZ    Capacitor                                                                                                                                                                                                                                                                                                                                                                                                                                                                                                                                                                          
C25      .1                        CAPEZ                     CAP-PTH-SMALLEZ    Capacitor                                                                                                                                                                                                                                                                                                                                                                                                                                                                                                                                                                          
C26      .1                        CAPEZ                     CAP-PTH-SMALLEZ    Capacitor                                                                                                                                                                                                                                                                                                                                                                                                                                                                                                                                                                          
C27      .1                        CAPEZ                     CAP-PTH-SMALLEZ    Capacitor                                                                                                                                                                                                                                                                                                                                                                                                                                                                                                                                                                          
C28      .1                        CAPEZ                     CAP-PTH-SMALLEZ    Capacitor                                                                                                                                                                                                                                                                                                                                                                                                                                                                                                                                                                          
C29      .1                        CAPEZ                     CAP-PTH-SMALLEZ    Capacitor                                                                                                                                                                                                                                                                                                                                                                                                                                                                                                                                                                          
C30      .1                        CAPEZ                     CAP-PTH-SMALLEZ    Capacitor                                                                                                                                                                                                                                                                                                                                                                                                                                                                                                                                                                          
C31      .1                        CAPEZ                     CAP-PTH-SMALLEZ    Capacitor                                                                                                                                                                                                                                                                                                                                                                                                                                                                                                                                                                          
C32      .1                        CAPEZ                     CAP-PTH-SMALLEZ    Capacitor                                                                                                                                                                                                                                                                                                                                                                                                                                                                                                                                                                          
C33      .1                        CAPEZ                     CAP-PTH-SMALLEZ    Capacitor                                                                                                                                                                                                                                                                                                                                                                                                                                                                                                                                                                          
C34      .1                        CAPEZ                     CAP-PTH-SMALLEZ    Capacitor                                                                                                                                                                                                                                                                                                                                                                                                                                                                                                                                                                          
C35      .1                        CAPEZ                     CAP-PTH-SMALLEZ    Capacitor                                                                                                                                                                                                                                                                                                                                                                                                                                                                                                                                                                          
C36      .1                        CAPEZ                     CAP-PTH-SMALLEZ    Capacitor                                                                                                                                                                                                                                                                                                                                                                                                                                                                                                                                                                          
CONT     SWITCH-MOMENTARY-2SIDE_EZ SWITCH-MOMENTARY-2SIDE_EZ TACTILE-PTH-SIDEEZ Various NO switches- pushbuttons, reed, etc                                                                                                                                                                                                                                                                                                                                                                                                                                                                                                                                        
HALT     SWITCH-MOMENTARY-2SIDE_EZ SWITCH-MOMENTARY-2SIDE_EZ TACTILE-PTH-SIDEEZ Various NO switches- pushbuttons, reed, etc                                                                                                                                                                                                                                                                                                                                                                                                                                                                                                                                        
IC1      74LS244N                  74LS244N                  DIL20              Octal BUFFER and LINE DRIVER, 3-state                                                                                                                                                                                                                                                                                                                                                                                                                                                                                                                                              
IC2      74LS244N                  74LS244N                  DIL20              Octal BUFFER and LINE DRIVER, 3-state                                                                                                                                                                                                                                                                                                                                                                                                                                                                                                                                              
IC3      74LS175N                  74LS175N                  DIL16              Qadruple D type FLIP FLOP, clear                                                                                                                                                                                                                                                                                                                                                                                                                                                                                                                                                   
IC4      74LS175N                  74LS175N                  DIL16              Qadruple D type FLIP FLOP, clear                                                                                                                                                                                                                                                                                                                                                                                                                                                                                                                                                   
IC5      74LS192N                  74LS192N                  DIL16              Synchronous 4-bit UP/DOWN COUNTER                                                                                                                                                                                                                                                                                                                                                                                                                                                                                                                                                  
IC6      74LS192N                  74LS192N                  DIL16              Synchronous 4-bit UP/DOWN COUNTER
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

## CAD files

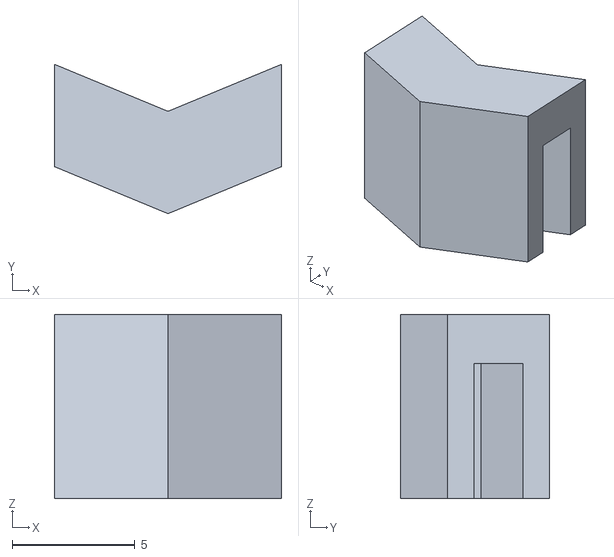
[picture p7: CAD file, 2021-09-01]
mech parts/clip12.stl
9.24 x 6.08 x 7.50

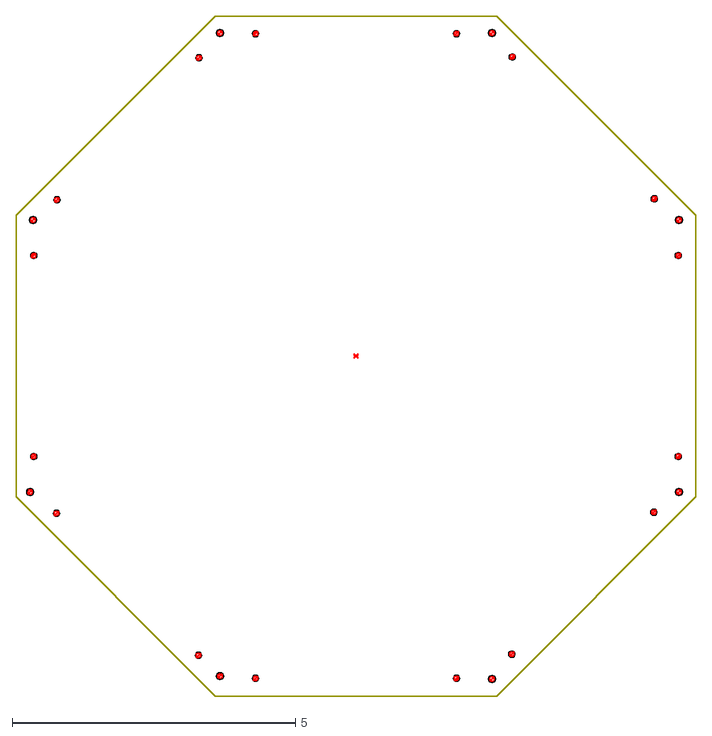
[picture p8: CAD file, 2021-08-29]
PCB/Working - Under Develolpment/BUS-PROD-V2.0/yacc2buss.dxf
12.0 x 12.0

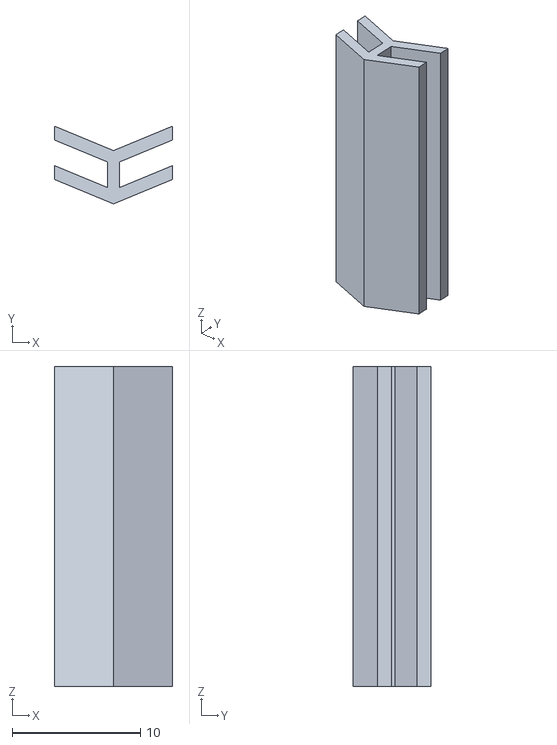
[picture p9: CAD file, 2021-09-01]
mech parts/divider.stl
9.24 x 6.08 x 25.0

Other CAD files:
PCB/Production/Bus Tester orig/switchtemplate.skp
mech parts/clip.skp
mech parts/clip12.skp
mech parts/clip12~.skp

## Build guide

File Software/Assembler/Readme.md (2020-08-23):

Classic assembler - Takes a .asm file and generates a .img file

asm.doc and asm.txt have more info

yacc1.def contains the definitions of the YACC1 instruction set

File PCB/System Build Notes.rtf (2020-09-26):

Build Order for boards

All board are in the Production directory, except the Bus-Test Card which is in the Unsure directory

1) Bus Test Card
2) Bus Card
3) Memory Card
4) Optional Prototype card
5) Index Register Card 1 of 2
6) ALU Card
7) Index Register Card 2 of 2
8) Sequencer Memory Card
9) Sequencer Logic Card

Add build instructions for all boards

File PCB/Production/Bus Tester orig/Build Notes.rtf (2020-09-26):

Build Notes: Bus Test Card

Always start with a quick board check (See BUS description)
GND
3 FAR right and 3 FAR LEFT BUS connector pins are connected
VCC
3 next to GND right and 3 next to GND LEFT BUS connector pins are connected
Test VCC not shorted to GND
Test VCC is connected to board, use C1 (any bypass cap has a GND side and a VCC side)
Test GND is connected to board, use C1 (any bypass cap has a GND side and a VCC side)

A couple of notes

R12 & R10 are 2.2k resistors (forget to send in package)
C6 and C7 are 22pf and are packaged with the XTAL
Also with XTAL is an insulator to place between the XTAL and the board
This board has no polarized capacitors
No need to install 10K - R2 through R7

I like building boards in reverse height order:

1) Lay flat resistors
2) IC Sockets, SIP Sockets, and XTAL
3) Smaller switches (BUS-RESET, CPU-RESET, S-A, S-B)
4) LEDS & Standup resistors (non on this board)
LEDS are polarized and have a flat side as indicated on the board silkscreen
5) Jumpers
6) Large Switches (Use template to assist with alignment)
7) Bus connector
Bolt connector in before soldering and verify all pins are properly through holes
Recommend soldering the middle of pins followed by the outside rows
8) The exception to the height rule, I do bypass caps last

Bringing up the board
1) Test VCC and GND are not shorted
2) NO BUS - Apply power to board by connecting FTDI cable and jumper FTDI-VCC jumper
2) With Bus - Plug board into bus and apply power to bus
- in either case PWR LED should come on
3) Install ATMEGA (ARDUINO) Chip and connect FTDI connector
Jumper DTR-RESET (resets ATMEGA chip on port open)
If powering from bus remove FTDI-VCC jumper
If powering from FTDI install jumper
Start Arduino IDE and select proper serial port
Install Arduino example “Blink” program
Install Memory Chip IC7
Test memory with program “mem” in Software->BUS-TEST-CARD->Test EEPROM->mem.ino
Install IC8 & IC9
Test Switches and LEDs with led-switch-test.ino
This program continuously reads switches, adds 1, and displays on LEDS
Install remaining ICs
Test for shorts with bus-test

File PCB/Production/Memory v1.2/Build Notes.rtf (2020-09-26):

Build Notes: Memory Card

Always start with a quick board check (See BUS description)
GND
3 FAR right and 3 FAR LEFT BUS connector pins are connected
VCC
3 next to GND right and 3 next to GND LEFT BUS connector pins are connected
Test VCC not shorted to GND
Test VCC is connected to board, use C1 (any bypass cap has a GND side and a VCC side)
Test GND is connected to board, use C1 (any bypass cap has a GND side and a VCC side)

I like building boards in reverse height order:

1) Lay flat resistors
2) IC Sockets, no need to install SIP connectors
3) LEDS & Standup resistors (non on this board)
LEDS are polarized and have a flat side as indicated on the board silkscreen
4) Jumpers
5) Bus connector
Bolt connector in before soldering and verify all pins are properly through holes
Recommend soldering the middle of pins followed by the outside rows
6) The exception to the height rule, I do bypass caps last

EEPROM & Sockets
Solder 1 machined 28 pin socket into IC13
Place EEPROMS into separate machined sockets
Add/Remove EEPROMS from board keeping EEPROMS in their own milled sockets

Bringing up the board
1) Test VCC and GND are not shorted
2) Plug board into bus and apply power to bus
- PWR LED should come on
3) Install Bus Test Card
Install Bus-Test program and check for shorts
4) Install all ICs in Memory card
Install Bus Driver Arduino program
Use Processing Command Sender (to be documented) and use memory test script

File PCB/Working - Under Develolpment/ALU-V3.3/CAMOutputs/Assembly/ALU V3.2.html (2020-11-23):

Partlist exported from /Users/kennethrother/Documents/YACC1-2020/PCB/Production/ALU-V3.2/ALU V3.2.sch at 11/23/20 8:22 AM

Qty | Value | Device | Package | Parts | Description | MF | MPN | OC_FARNELL | OC_NEWARK | POPULARITY | SPICEMODEL | SPICEPREFIX
1 | | LED5MM | LED5MM | PWR | LED
1 | | MA05-2 | MA05-2 | SV1 | PIN HEADER | | | unknown | unknown
2 | | PINHD-1X3 | 1X03 | JP1, JP2 | PIN HEADER | | | | | 92
1 | ,1uf | C-US025-024X044 | C025-024X044 | C21 | CAPACITOR, American symbol
38 | .1uf | C-US025-024X044 | C025-024X044 | C1, C2, C3, C4, C5, C6, C7, C8, C9, C10, C11, C12, C13, C14, C15, C16, C17, C18, C19, C20, C22, C23, C24, C25, C26, C27, C28, C29, C30, C31, C32, C33, C34, C35, C36, C37, C38, C39 | CAPACITOR, American symbol
2 | 10k | RNX8 | RN-9 | RN1, RN2 | RESISTOR NETWORK | | | unknown | unknown
1 | 330 | R0207/10 | 0207/10 | R1 | RESISTOR, European symbol | | | | | | NONE | R
2 | 744078N | 744078N | DIL14 | V1, V2 | 8-input OR/NOR, complementary outputs
1 | 74ALS04N | 74ALS04N | DIL14 | IC1 | Hex INVERTER
1 | 74ALS08N | 74ALS08N | DIL14 | IC6 | Quad 2-input AND gate
1 | 74LS00N | 74LS00N | DIL14 | IC4 | Quad 2-input NAND gate
2 | 74LS08N | 74LS08N | DIL14 | IC18, IC19 | Quad 2-input AND gate
1 | 74LS138N | 74LS138N | DIL16 | IC8 | 3-line to 8-line DECODER/DEMULTIPLEXER
2 | 74LS153N | 74LS153N | DIL16 | IC28, IC32 | Dual 4-line to 1-line data SELECTOR/MULTIPLEXER
2 | 74LS194N | 74LS194N | DIL16 | IC29, IC30 | 4-bit bidirectional SHIFT REGISTER
1 | 74LS240N | 74LS240N | DIL20 | IC2 | Octal BUFFER and LINE DRIVER, 3-state
9 | 74LS244N | 74LS244N | DIL20 | IC3, IC12, IC13, IC16, IC17, IC20, IC23, IC31, IC37 | Octal BUFFER and LINE DRIVER, 3-state
2 | 74LS245N | 74LS245N | DIL20 | IC10, IC11 | Octal BUS TRANSCEIVER, 3-state
1 | 74LS251N | 74LS251N | DIL16 | IC26 | 1 of 8 data SELECTOR/MULTIPLEXER, 3-state
2 | 74LS283N | 74LS283N | DIL16 | IC35, IC36 | 4-bit binary FULL ADDER, fast carry
3 | 74LS32N | 74LS32N | DIL14 | IC7, IC21, IC22 | Quad 2-input OR gate
1 | 74LS374N | 74LS374N | DIL20 | IC5 | Octal D type transparent LATCH, edge triggered
1 | 74LS74N | 74LS74N | DIL14 | IC9 | Dual D type positive edge triggered FLIP FLOP, preset and clear
2 | 74LS85N | 74LS85N | DIL16 | IC24, IC25 | 4-bit magnitude COMPARATOR
5 | 74LS86N | 74LS86N | DIL14 | IC14, IC15, IC27, IC33, IC34 | Quad 2-input EXCLUSIV-OR (XOR) gate
1 | FABC96R | FABC96R | FABC96R | X1 | CONNECTOR female, 96 pins, type R, rows ABC, grid 2.54 mm

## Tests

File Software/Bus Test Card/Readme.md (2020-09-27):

Bus Test Card Software

bus-driver
    Command line interface to drive/read bus signals
    see BUS Driver Commands (gdoc) for more information

bus-monitor
    Listens to bus and reports changes

bus-test
    Tests for shorts on bus

led-switch-test
    Simple test of LEDs & Switchs
    Read switches, adds 1, displays on LEDS

Test EEPROM
    Simple test to verify onboard controller can read/write onboard EEPROM chip

BUS Driver commands
    Command format for bus-driver program

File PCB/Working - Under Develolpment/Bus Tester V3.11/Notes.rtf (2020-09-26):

***** NORTE *****

May 4/2020

This is based on V1.1 PCB Production design

Updates to prior designs, should have no electrical differences.
All lines of bus should be controllable

Removing pull-ups of which currently are on Data and Address lines

FIX on PCB
Join R21 to R9 to gnd 8 leds
This fix is reflected in schematic but not on PCB, PCB uses a jumper

Add bypass. Cap for atmega

Should IN INT support read mode and be readable/reportable through CLI

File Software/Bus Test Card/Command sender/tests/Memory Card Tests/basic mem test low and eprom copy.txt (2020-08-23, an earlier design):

// SAMPLE COMMENT
// BASIC TEST
-RESET:1#
-RESET:0#
-VMA:1#
ADDRBUS-WR-MODE:1#
DATABUS-RD-MODE:1#
DUMP:0000-000F#
DUMP:F000-F00F#
WR-ADDRBUS:FFFF#
DUMP:0000-000F#
DUMP:F000-F00F#
DATABUS-WR-MODE:1#
FOR A=1,10,1
WR-ADDRBUS:VA#
WR-DATABUS:VA#
-MEM-WR:1#
-MEM-WR:0#
NEXT A
DATABUS-RD-MODE:1#
DUMP:0000-000F#
DUMP:F000-F00F#

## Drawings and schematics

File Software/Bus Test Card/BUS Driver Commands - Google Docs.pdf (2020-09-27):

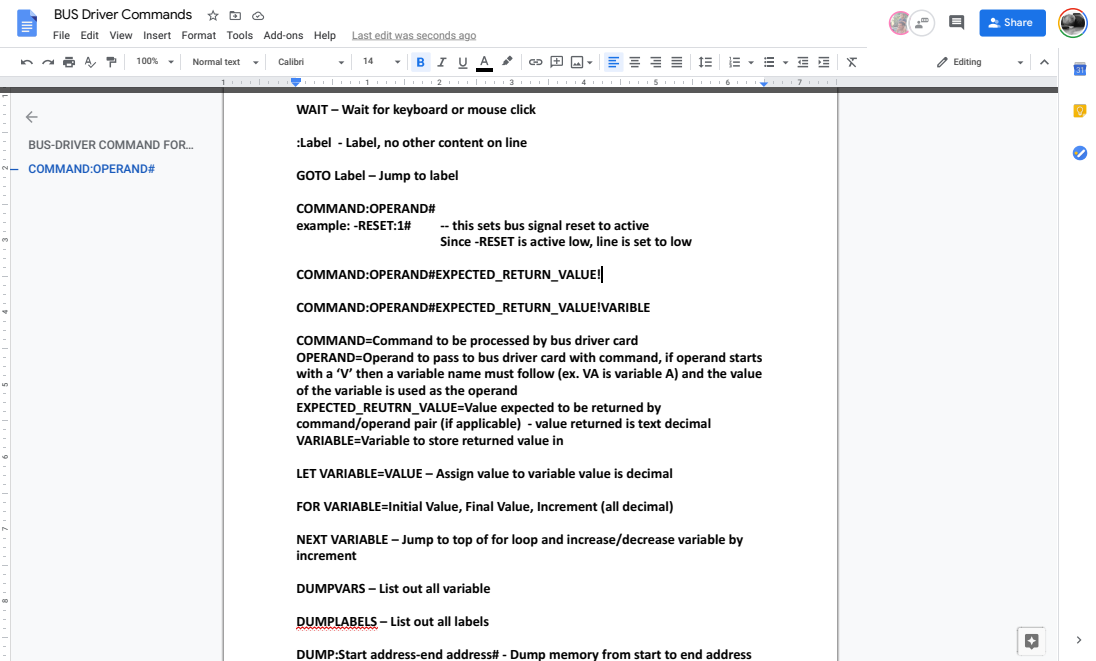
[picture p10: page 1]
File Edit View Insert Format Tools Add-ons Help; Last edit was seconds ago; Normal text; Calibri; Editing; COMMAND:OPERAND#; example: -RESET:1#; -- this sets bus signal reset to active; COMMAND:OPERAND#EXPECTED_RETURN_VALUE!; BUS Driver Commands; Share

BUS Driver Commands

WAIT – Wait for keyboard or mouse click

BUS-DRIVER COMMAND FOR…
— COMMAND:OPERAND#

:Label - Label, no other content on line

GOTO Label – Jump to label

Since -RESET is active low, line is set to low

COMMAND:OPERAND#EXPECTED_RETURN_VALUE!VARIBLE

COMMAND=Command to be processed by bus driver card
OPERAND=Operand to pass to bus driver card with command, if operand starts
with a ‘V’ then a variable name must follow (ex. VA is variable A) and the value
of the variable is used as the operand
EXPECTED_REUTRN_VALUE=Value expected to be returned by
command/operand pair (if applicable) - value returned is text decimal
VARIABLE=Variable to store returned value in

LET VARIABLE=VALUE – Assign value to variable value is decimal

FOR VARIABLE=Initial Value, Final Value, Increment (all decimal)

NEXT VARIABLE – Jump to top of for loop and increase/decrease variable by
increment

DUMPVARS – List out all variable

DUMPLABELS – List out all labels

DUMP:Start address-end address# - Dump memory from start to end address

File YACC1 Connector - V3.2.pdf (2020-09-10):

YACC1 Connector | YACC 3.2
A | A | A | B | B | B | C | C | C

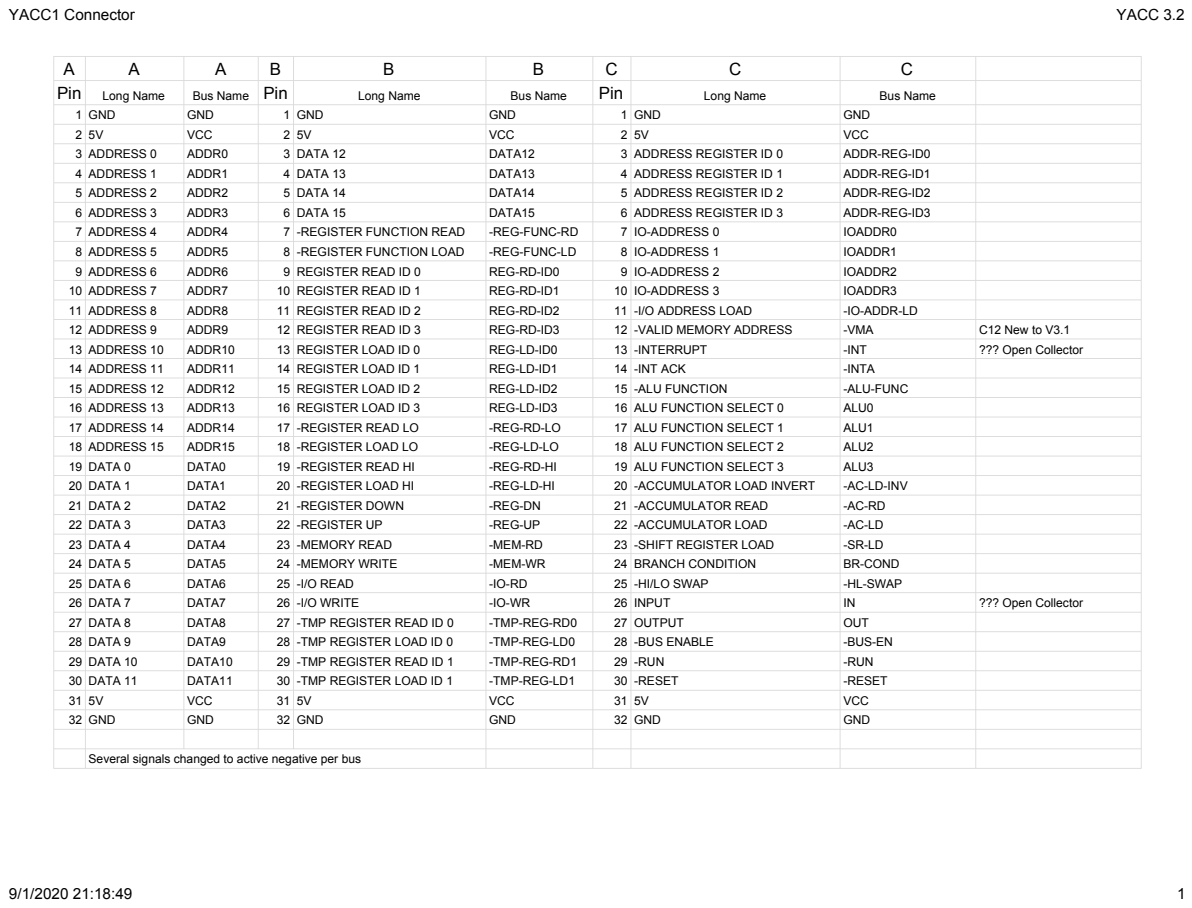
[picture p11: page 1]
Pin; Long Name; Bus Name; 1 GND; GND; VCC; 3 ADDRESS 0; ADDR0; 3 DATA 12; DATA12; 3 ADDRESS REGISTER ID 0; ADDR-REG-ID0; 4 ADDRESS 1; ADDR1; 4 DATA 13; DATA13; 4 ADDRESS REGISTER ID 1; ADDR-REG-ID1; 5 ADDRESS 2; ADDR2; 5 DATA 14; DATA14; 5 ADDRESS REGISTER ID 2; ADDR-REG-ID2; 6 ADDRESS 3; ADDR3; 6 DATA 15; DATA15; 6 ADDRESS REGISTER ID 3; ADDR-REG-ID3; 7 ADDRESS 4; ADDR4; 7 -REGISTER FUNCTION READ; -REG-FUNC-RD; 7 IO-ADDRESS 0; IOADDR0; 8 ADDRESS 5; ADDR5; 8 -REGISTER FUNCTION LOAD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

Several signals changed to active negative per bus

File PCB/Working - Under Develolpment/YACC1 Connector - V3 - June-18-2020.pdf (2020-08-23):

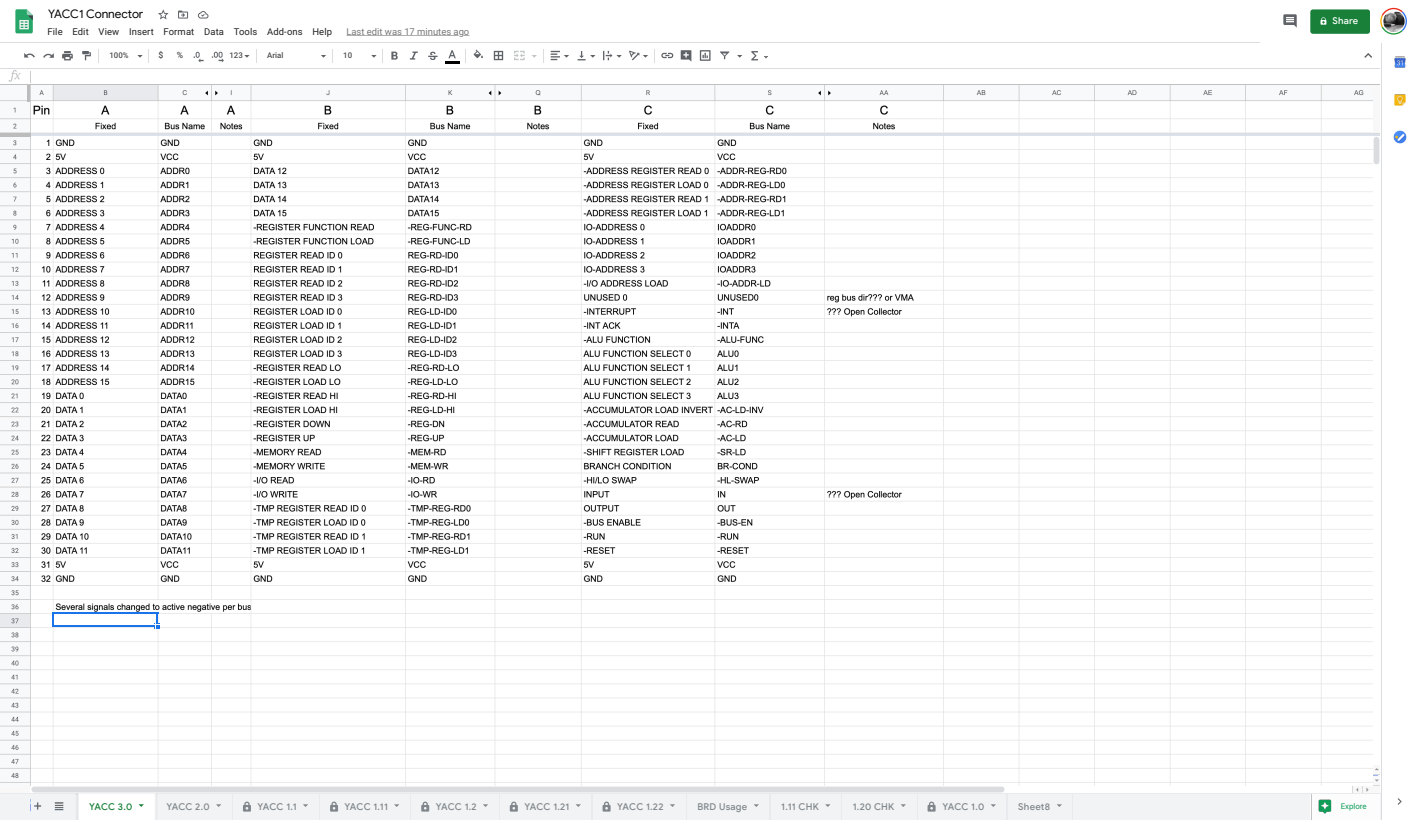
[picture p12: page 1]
YACC1 Connector; File Edit View Insert Format Data Tools Add-ons Help; Last edit was 17 minutes ago; Arial; Share; YACC 3.0; YACC 2.0; YACC 1.1; YACC 1.11; YACC 1.2; YACC 1.21; YACC 1.22; BRD Usage; 1.11 CHK; 1.20 CHK; YACC 1.0; Sheet8; Explore

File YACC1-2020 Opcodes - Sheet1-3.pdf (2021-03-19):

# YACC1-2020 Opcodes

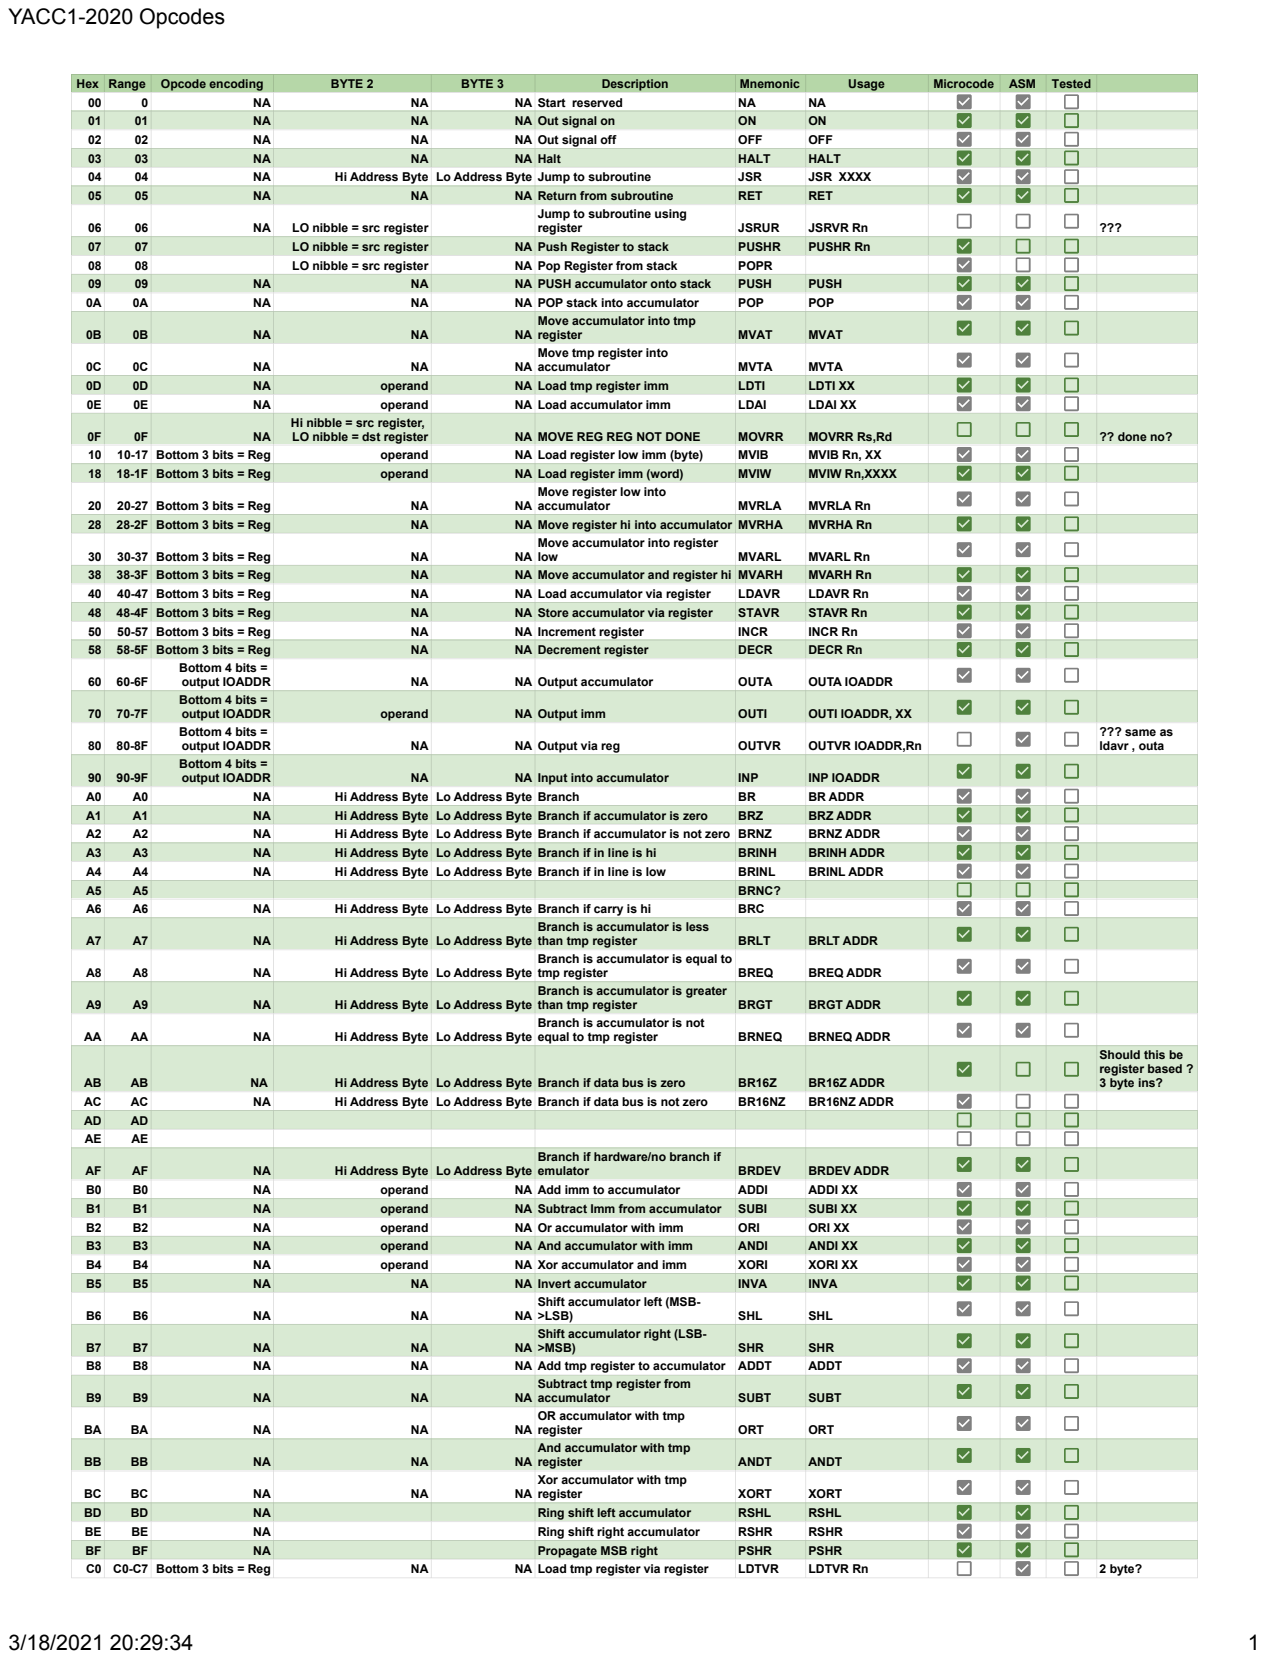
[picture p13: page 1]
Hex Range; Opcode encoding; BYTE 2; BYTE 3; Description; Mnemonic; Usage; Microcode; ASM; Tested; NA Start reserved; NA Out signal on; NA Out signal off; OFF; NA Halt; HALT; Hi Address Byte Lo Address Byte Jump to subroutine; JSR; JSR XXXX; NA Return from subroutine; RET; LO nibble = src register; register; JSRUR; JSRVR Rn; NA Push Register to stack; PUSHR; PUSHR Rn; NA Pop Register from stack; POPR; NA PUSH accumulator onto stack; PUSH; NA POP stack into accumulator; POP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

Jump to subroutine using

Hi nibble = src register,

Branch is accumulator is less
Branch is accumulator is equal to
Branch is accumulator is greater

Should this be
register based ?
3 byte ins?

Shift accumulator left (MSB-
Shift accumulator right (LSB-

OR accumulator with tmp
And accumulator with tmp
Xor accumulator with tmp

# YACC1-2020 Opcodes

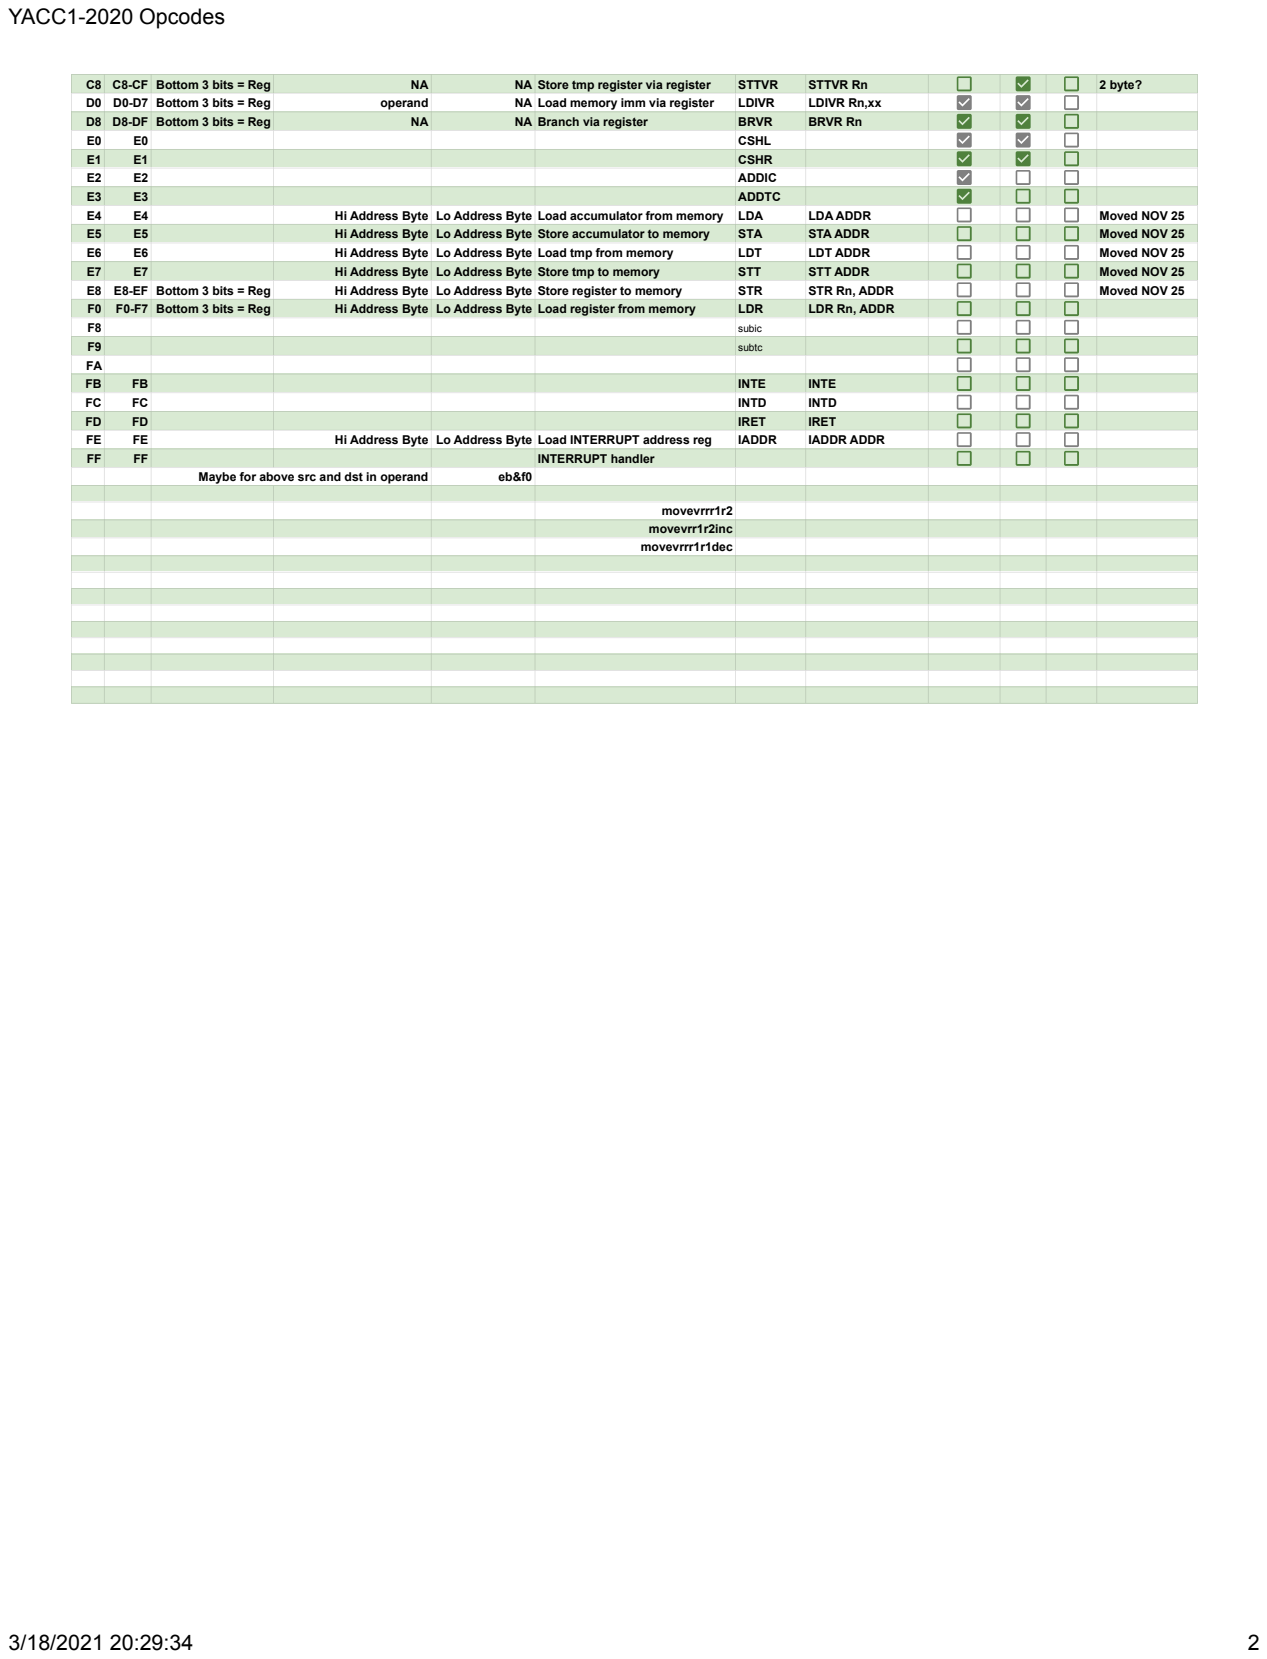
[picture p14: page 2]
C8 C8-CF Bottom 3 bits = Reg; NA Store tmp register via register; STTVR; STTVR Rn; 2 byte?; D0 D0-D7 Bottom 3 bits = Reg; operand; NA Load memory imm via register; LDIVR; LDIVR Rn,xx; D8 D8-DF Bottom 3 bits = Reg; NA Branch via register; BRVR; BRVR Rn; CSHL; CSHR; ADDIC; ADDTC; Hi Address Byte Lo Address Byte Load accumulator from memory; LDA; LDA ADDR; Moved NOV 25; Hi Address Byte Lo Address Byte Store accumulator to memory; STA; STA ADDR; Hi Address Byte Lo Address Byte Load tmp from memory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

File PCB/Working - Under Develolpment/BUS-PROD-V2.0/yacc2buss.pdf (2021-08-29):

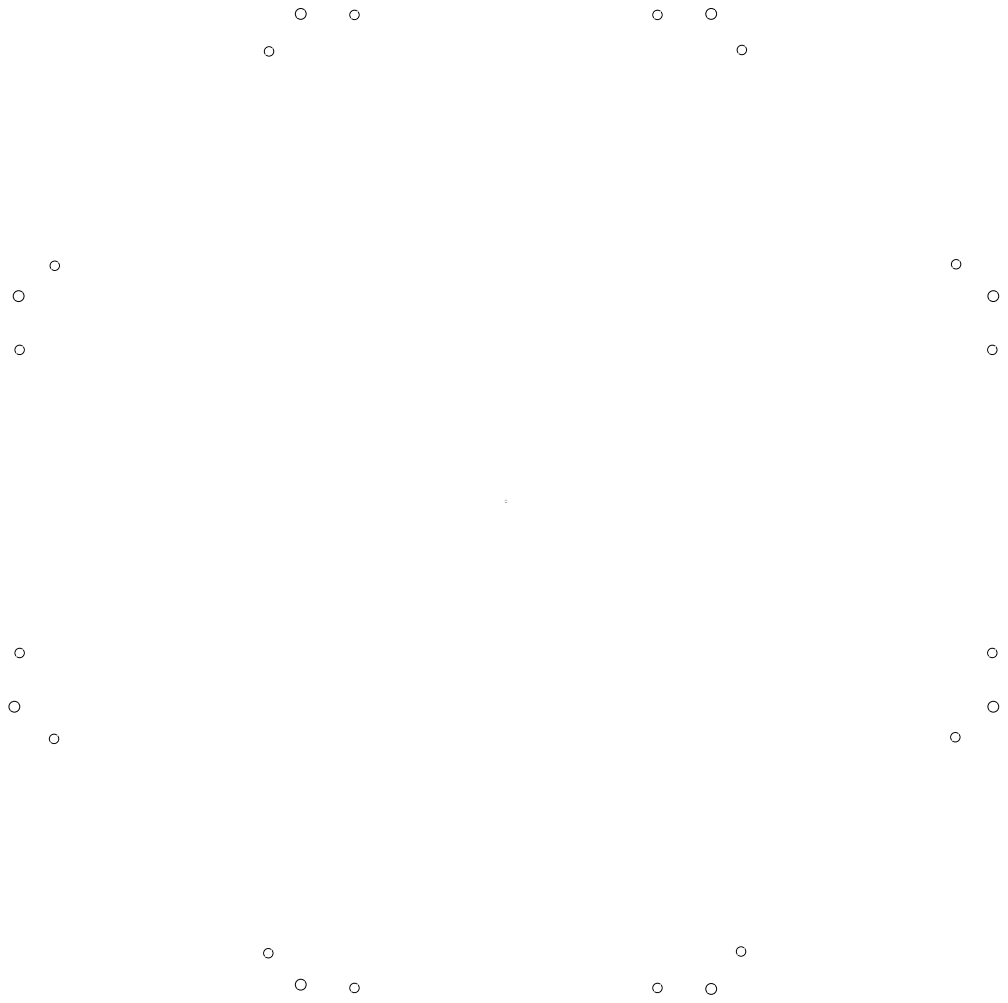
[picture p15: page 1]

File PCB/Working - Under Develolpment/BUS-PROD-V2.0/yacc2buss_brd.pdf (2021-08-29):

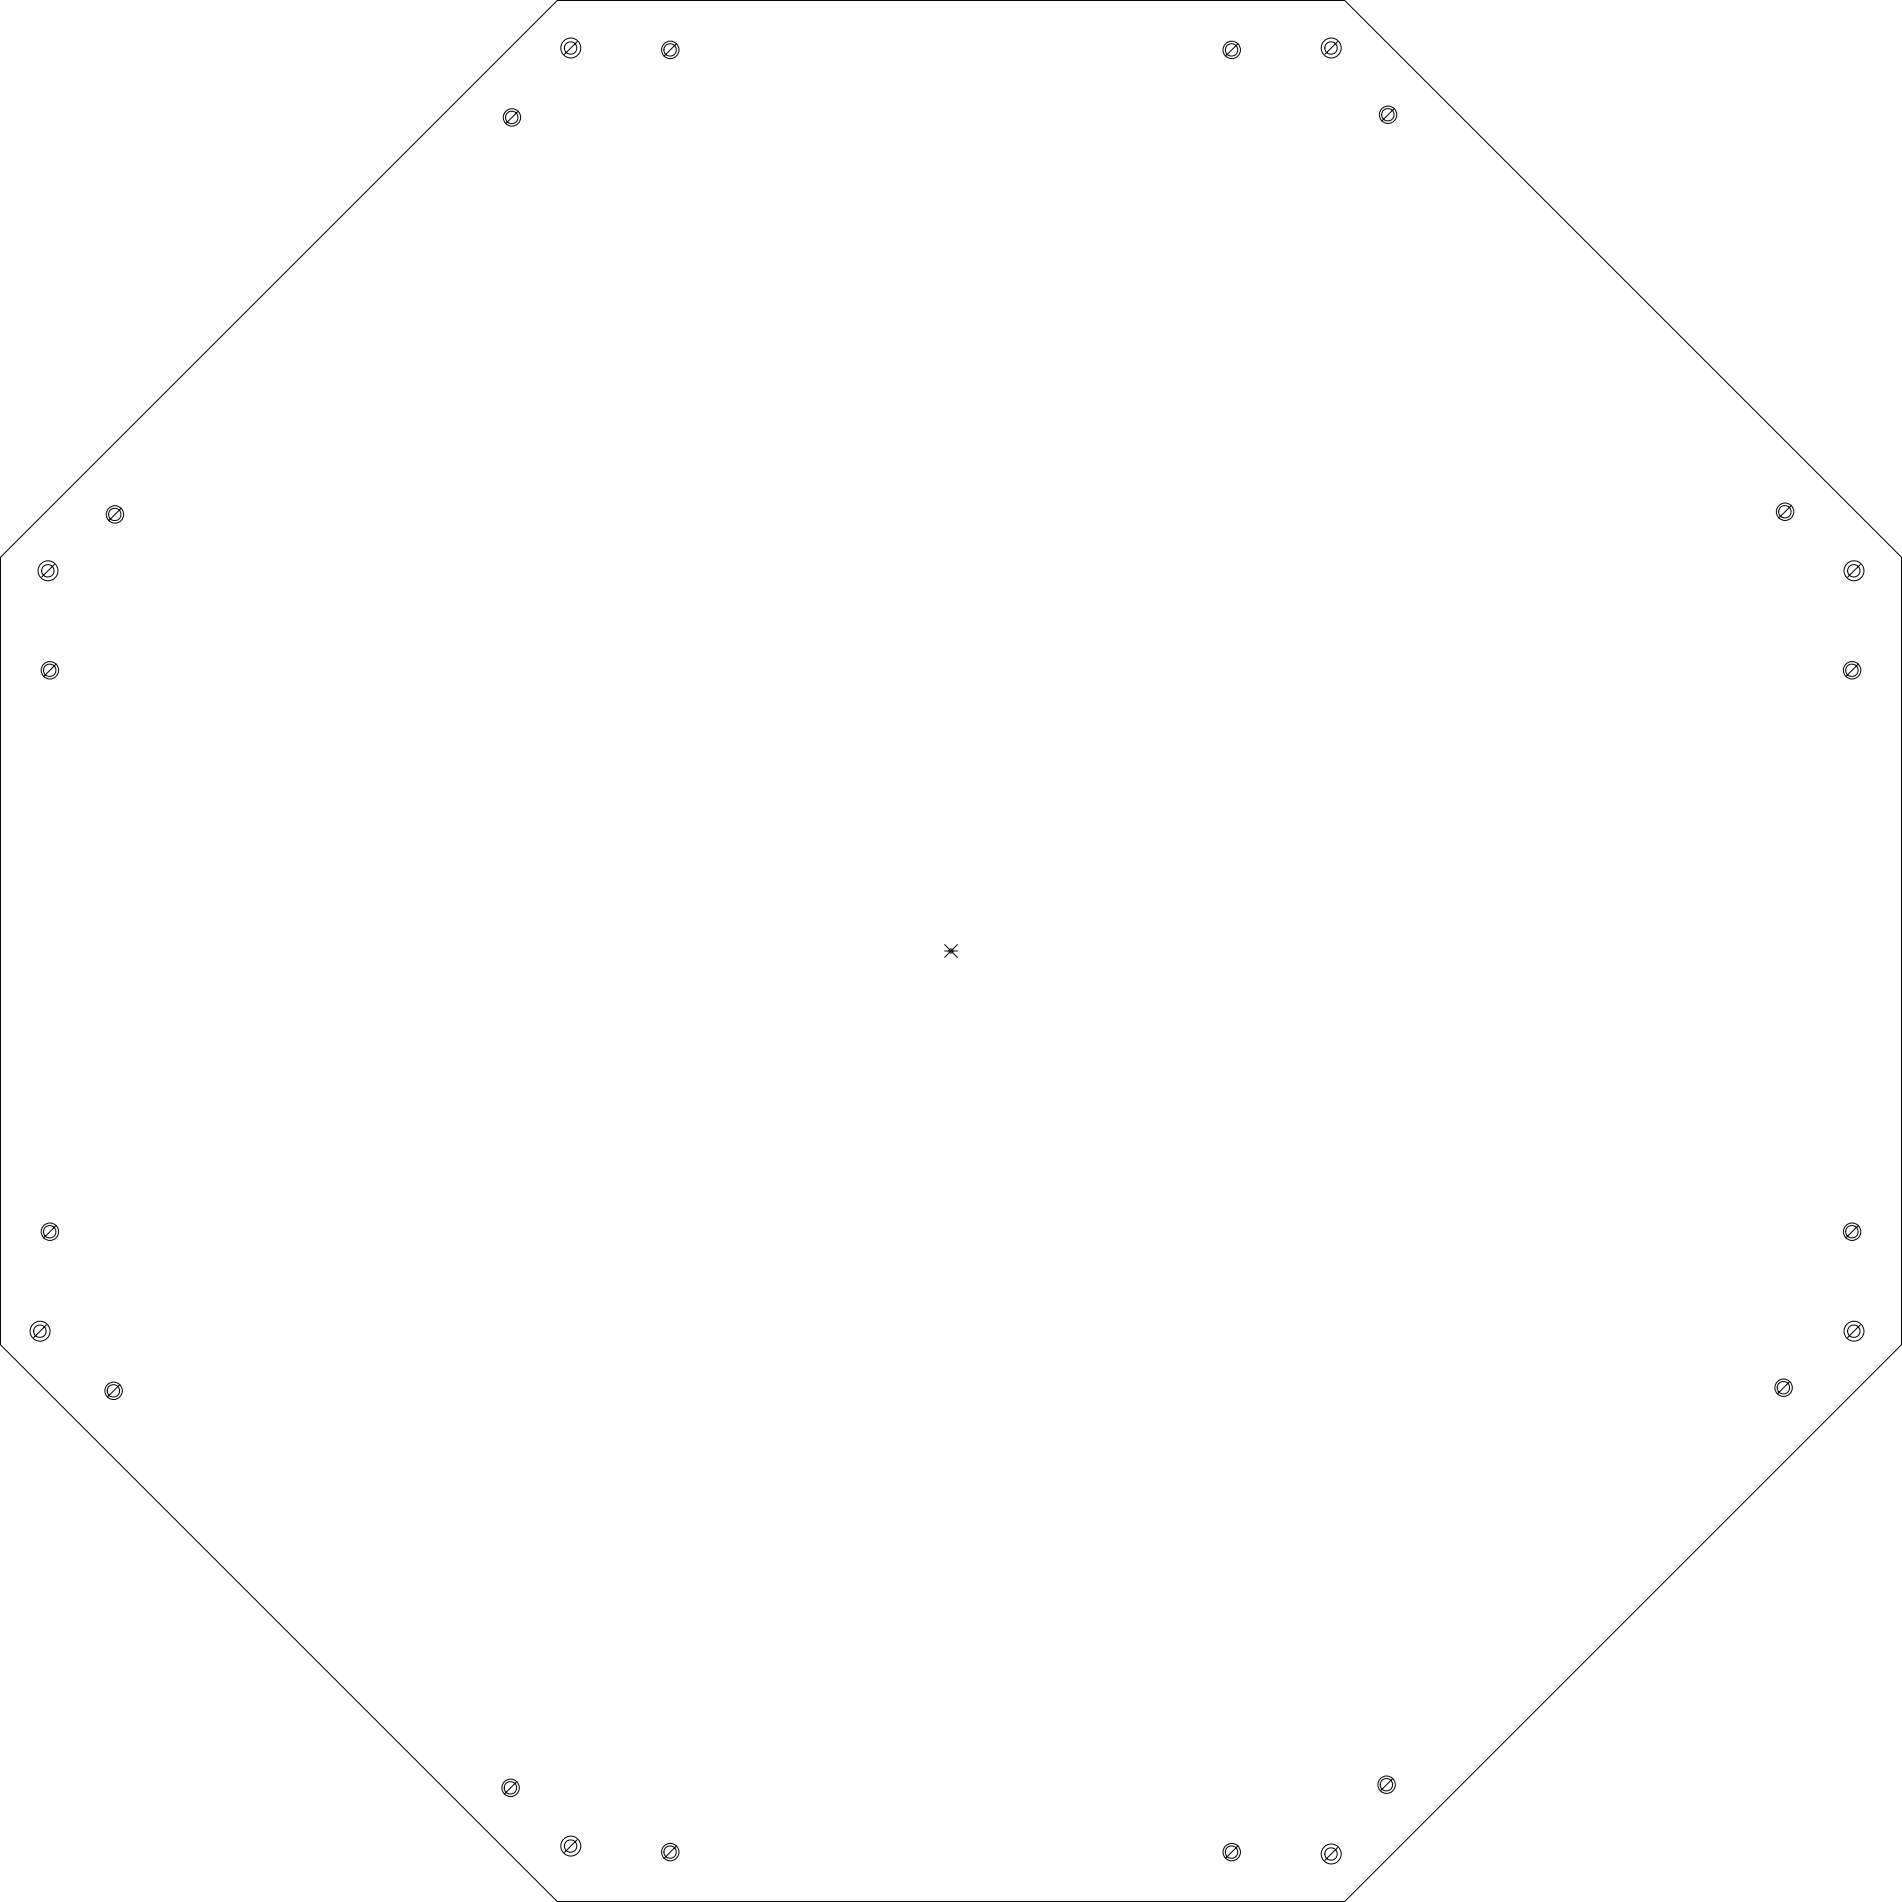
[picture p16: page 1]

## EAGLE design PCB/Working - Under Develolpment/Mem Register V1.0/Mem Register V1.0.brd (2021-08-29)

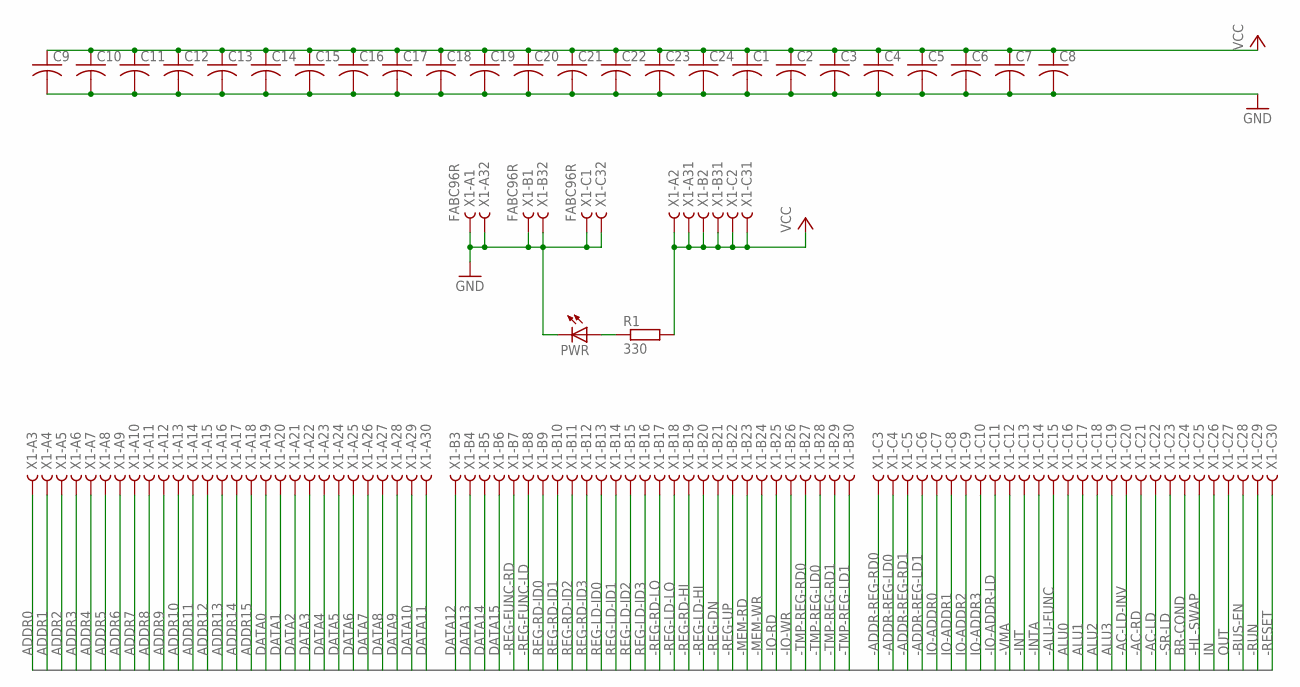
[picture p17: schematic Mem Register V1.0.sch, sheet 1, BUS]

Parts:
C1, C2, C3, C4, C5, C6, C7, C8, C9, C10, C11, C12, C13, C14, C15, C16, C17, C18, C19, C20, C21, C22, C23, C24: C-US025-025X050; C025-025X050
PWR: LED5MM
R1: 330; 0207/10
X1: FABC96R

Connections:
-AC-LD: X1.C22
-AC-LD-INV: X1.C20
-AC-RD: X1.C21
-ADDR-REG-LD0: X1.C4
-ADDR-REG-LD1: X1.C6
-ADDR-REG-RD0: X1.C3
-ADDR-REG-RD1: X1.C5
-ALU-FUNC: X1.C15
-BUS-EN: X1.C28; also elsewhere on the board
-HL-SWAP: X1.C25
-INT: X1.C13
-INTA: X1.C14
-IO-ADDR-LD: X1.C11
-IO-RD: X1.B25
-IO-WR: X1.B26
-MEM-RD: X1.B23; also elsewhere on the board
-MEM-WR: X1.B24; also elsewhere on the board
-REG-DN: X1.B21
-REG-FUNC-LD: X1.B8
-REG-FUNC-RD: X1.B7
-REG-LD-HI: X1.B20
-REG-LD-LO: X1.B18
-REG-RD-HI: X1.B19
-REG-RD-LO: X1.B17
-REG-UP: X1.B22
-RESET: X1.C30
-RUN: X1.C29
-SR-LD: X1.C23
-TMP-REG-LD0: X1.B28
-TMP-REG-LD1: X1.B30
-TMP-REG-RD0: X1.B27
-TMP-REG-RD1: X1.B29
-VMA: X1.C12; also elsewhere on the board
ADDR0: X1.A3; also elsewhere on the board
ADDR1: X1.A4; also elsewhere on the board
ADDR2: X1.A5; also elsewhere on the board
ADDR3: X1.A6; also elsewhere on the board
ADDR4: X1.A7; also elsewhere on the board
ADDR5: X1.A8; also elsewhere on the board
ADDR6: X1.A9; also elsewhere on the board
ADDR7: X1.A10; also elsewhere on the board
ADDR8: X1.A11; also elsewhere on the board
ADDR9: X1.A12; also elsewhere on the board
ADDR10: X1.A13; also elsewhere on the board
ADDR11: X1.A14; also elsewhere on the board
ADDR12: X1.A15; also elsewhere on the board
ADDR13: X1.A16; also elsewhere on the board
ADDR14: X1.A17; also elsewhere on the board
ADDR15: X1.A18; also elsewhere on the board
ALU0: X1.C16
ALU1: X1.C17
ALU2: X1.C18
ALU3: X1.C19
BR-COND: X1.C24
DATA0: X1.A19; also elsewhere on the board
DATA1: X1.A20; also elsewhere on the board
DATA2: X1.A21; also elsewhere on the board
DATA3: X1.A22; also elsewhere on the board
DATA4: X1.A23; also elsewhere on the board
DATA5: X1.A24; also elsewhere on the board
DATA6: X1.A25; also elsewhere on the board
DATA7: X1.A26; also elsewhere on the board
DATA8: X1.A27
DATA9: X1.A28
DATA10: X1.A29
DATA11: X1.A30
DATA12: X1.B3
DATA13: X1.B4
DATA14: X1.B5
DATA15: X1.B6
GND: C1.2, C2.2, C3.2, C4.2, C5.2, C6.2, C7.2, C8.2, C9.2, C10.2, C11.2, C12.2, C13.2, C14.2, C15.2, C16.2, C17.2, C18.2, C19.2, C20.2, C21.2, C22.2, C23.2, C24.2, PWR.K (C), X1.A1, X1.A32, X1.B1, X1.B32, X1.C1, X1.C32; also elsewhere on the board
IN: X1.C26
IO-ADDR0: X1.C7
IO-ADDR1: X1.C8
IO-ADDR2: X1.C9
IO-ADDR3: X1.C10
unnamed: PWR.A, R1.1
OUT: X1.C27
REG-LD-ID0: X1.B13
REG-LD-ID1: X1.B14
REG-LD-ID2: X1.B15
REG-LD-ID3: X1.B16
REG-RD-ID0: X1.B9
REG-RD-ID1: X1.B10
REG-RD-ID2: X1.B11
REG-RD-ID3: X1.B12
VCC: C1.1, C2.1, C3.1, C4.1, C5.1, C6.1, C7.1, C8.1, C9.1, C10.1, C11.1, C12.1, C13.1, C14.1, C15.1, C16.1, C17.1, C18.1, C19.1, C20.1, C21.1, C22.1, C23.1, C24.1, R1.2, X1.A2, X1.A31, X1.B2, X1.B31, X1.C2, X1.C31; also elsewhere on the board

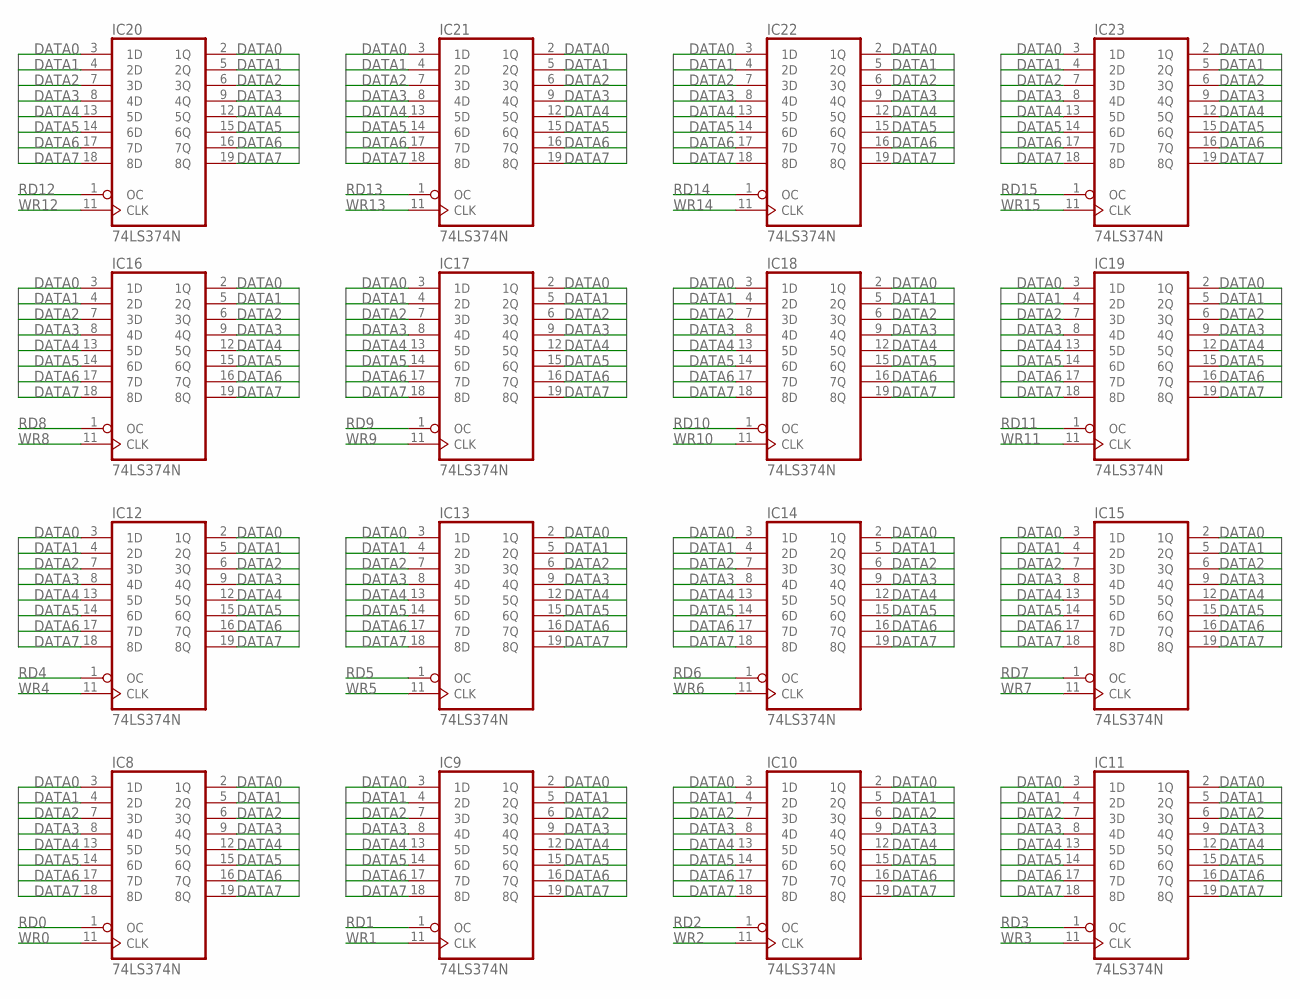
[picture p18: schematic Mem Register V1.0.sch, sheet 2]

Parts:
IC8, IC9, IC10, IC11, IC12, IC13, IC14, IC15, IC16, IC17, IC18, IC19, IC20, IC21, IC22, IC23: 74LS374N; DIL20

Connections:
DATA0: IC8.2 (1Q), IC8.3 (1D), IC9.2 (1Q), IC9.3 (1D), IC10.2 (1Q), IC10.3 (1D), IC11.2 (1Q), IC11.3 (1D), IC12.2 (1Q), IC12.3 (1D), IC13.2 (1Q), IC13.3 (1D), IC14.2 (1Q), IC14.3 (1D), IC15.2 (1Q), IC15.3 (1D), IC16.2 (1Q), IC16.3 (1D), IC17.2 (1Q), IC17.3 (1D), IC18.2 (1Q), IC18.3 (1D), IC19.2 (1Q), IC19.3 (1D), IC20.2 (1Q), IC20.3 (1D), IC21.2 (1Q), IC21.3 (1D), IC22.2 (1Q), IC22.3 (1D), IC23.2 (1Q), IC23.3 (1D); also elsewhere on the board
DATA1: IC8.4 (2D), IC8.5 (2Q), IC9.4 (2D), IC9.5 (2Q), IC10.4 (2D), IC10.5 (2Q), IC11.4 (2D), IC11.5 (2Q), IC12.4 (2D), IC12.5 (2Q), IC13.4 (2D), IC13.5 (2Q), IC14.4 (2D), IC14.5 (2Q), IC15.4 (2D), IC15.5 (2Q), IC16.4 (2D), IC16.5 (2Q), IC17.4 (2D), IC17.5 (2Q), IC18.4 (2D), IC18.5 (2Q), IC19.4 (2D), IC19.5 (2Q), IC20.4 (2D), IC20.5 (2Q), IC21.4 (2D), IC21.5 (2Q), IC22.4 (2D), IC22.5 (2Q), IC23.4 (2D), IC23.5 (2Q); also elsewhere on the board
DATA2: IC8.6 (3Q), IC8.7 (3D), IC9.6 (3Q), IC9.7 (3D), IC10.6 (3Q), IC10.7 (3D), IC11.6 (3Q), IC11.7 (3D), IC12.6 (3Q), IC12.7 (3D), IC13.6 (3Q), IC13.7 (3D), IC14.6 (3Q), IC14.7 (3D), IC15.6 (3Q), IC15.7 (3D), IC16.6 (3Q), IC16.7 (3D), IC17.6 (3Q), IC17.7 (3D), IC18.6 (3Q), IC18.7 (3D), IC19.6 (3Q), IC19.7 (3D), IC20.6 (3Q), IC20.7 (3D), IC21.6 (3Q), IC21.7 (3D), IC22.6 (3Q), IC22.7 (3D), IC23.6 (3Q), IC23.7 (3D); also elsewhere on the board
DATA3: IC8.8 (4D), IC8.9 (4Q), IC9.8 (4D), IC9.9 (4Q), IC10.8 (4D), IC10.9 (4Q), IC11.8 (4D), IC11.9 (4Q), IC12.8 (4D), IC12.9 (4Q), IC13.8 (4D), IC13.9 (4Q), IC14.8 (4D), IC14.9 (4Q), IC15.8 (4D), IC15.9 (4Q), IC16.8 (4D), IC16.9 (4Q), IC17.8 (4D), IC17.9 (4Q), IC18.8 (4D), IC18.9 (4Q), IC19.8 (4D), IC19.9 (4Q), IC20.8 (4D), IC20.9 (4Q), IC21.8 (4D), IC21.9 (4Q), IC22.8 (4D), IC22.9 (4Q), IC23.8 (4D), IC23.9 (4Q); also elsewhere on the board
DATA4: IC8.12 (5Q), IC8.13 (5D), IC9.12 (5Q), IC9.13 (5D), IC10.12 (5Q), IC10.13 (5D), IC11.12 (5Q), IC11.13 (5D), IC12.12 (5Q), IC12.13 (5D), IC13.12 (5Q), IC13.13 (5D), IC14.12 (5Q), IC14.13 (5D), IC15.12 (5Q), IC15.13 (5D), IC16.12 (5Q), IC16.13 (5D), IC17.12 (5Q), IC17.13 (5D), IC18.12 (5Q), IC18.13 (5D), IC19.12 (5Q), IC19.13 (5D), IC20.12 (5Q), IC20.13 (5D), IC21.12 (5Q), IC21.13 (5D), IC22.12 (5Q), IC22.13 (5D), IC23.12 (5Q), IC23.13 (5D); also elsewhere on the board
DATA5: IC8.14 (6D), IC8.15 (6Q), IC9.14 (6D), IC9.15 (6Q), IC10.14 (6D), IC10.15 (6Q), IC11.14 (6D), IC11.15 (6Q), IC12.14 (6D), IC12.15 (6Q), IC13.14 (6D), IC13.15 (6Q), IC14.14 (6D), IC14.15 (6Q), IC15.14 (6D), IC15.15 (6Q), IC16.14 (6D), IC16.15 (6Q), IC17.14 (6D), IC17.15 (6Q), IC18.14 (6D), IC18.15 (6Q), IC19.14 (6D), IC19.15 (6Q), IC20.14 (6D), IC20.15 (6Q), IC21.14 (6D), IC21.15 (6Q), IC22.14 (6D), IC22.15 (6Q), IC23.14 (6D), IC23.15 (6Q); also elsewhere on the board
DATA6: IC8.16 (7Q), IC8.17 (7D), IC9.16 (7Q), IC9.17 (7D), IC10.16 (7Q), IC10.17 (7D), IC11.16 (7Q), IC11.17 (7D), IC12.16 (7Q), IC12.17 (7D), IC13.16 (7Q), IC13.17 (7D), IC14.16 (7Q), IC14.17 (7D), IC15.16 (7Q), IC15.17 (7D), IC16.16 (7Q), IC16.17 (7D), IC17.16 (7Q), IC17.17 (7D), IC18.16 (7Q), IC18.17 (7D), IC19.16 (7Q), IC19.17 (7D), IC20.16 (7Q), IC20.17 (7D), IC21.16 (7Q), IC21.17 (7D), IC22.16 (7Q), IC22.17 (7D), IC23.16 (7Q), IC23.17 (7D); also elsewhere on the board
DATA7: IC8.18 (8D), IC8.19 (8Q), IC9.18 (8D), IC9.19 (8Q), IC10.18 (8D), IC10.19 (8Q), IC11.18 (8D), IC11.19 (8Q), IC12.18 (8D), IC12.19 (8Q), IC13.18 (8D), IC13.19 (8Q), IC14.18 (8D), IC14.19 (8Q), IC15.18 (8D), IC15.19 (8Q), IC16.18 (8D), IC16.19 (8Q), IC17.18 (8D), IC17.19 (8Q), IC18.18 (8D), IC18.19 (8Q), IC19.18 (8D), IC19.19 (8Q), IC20.18 (8D), IC20.19 (8Q), IC21.18 (8D), IC21.19 (8Q), IC22.18 (8D), IC22.19 (8Q), IC23.18 (8D), IC23.19 (8Q); also elsewhere on the board
GND: IC8.10 (GND), IC9.10 (GND), IC10.10 (GND), IC11.10 (GND), IC12.10 (GND), IC13.10 (GND), IC14.10 (GND), IC15.10 (GND), IC16.10 (GND), IC17.10 (GND), IC18.10 (GND), IC19.10 (GND), IC20.10 (GND), IC21.10 (GND), IC22.10 (GND), IC23.10 (GND); also elsewhere on the board
RD0: IC8.1 (OC); also elsewhere on the board
RD1: IC9.1 (OC); also elsewhere on the board
RD2: IC10.1 (OC); also elsewhere on the board
RD3: IC11.1 (OC); also elsewhere on the board
RD4: IC12.1 (OC); also elsewhere on the board
RD5: IC13.1 (OC); also elsewhere on the board
RD6: IC14.1 (OC); also elsewhere on the board
RD7: IC15.1 (OC); also elsewhere on the board
RD8: IC16.1 (OC); also elsewhere on the board
RD9: IC17.1 (OC); also elsewhere on the board
RD10: IC18.1 (OC); also elsewhere on the board
RD11: IC19.1 (OC); also elsewhere on the board
RD12: IC20.1 (OC); also elsewhere on the board
RD13: IC21.1 (OC); also elsewhere on the board
RD14: IC22.1 (OC); also elsewhere on the board
RD15: IC23.1 (OC); also elsewhere on the board
VCC: IC8.20 (VCC), IC9.20 (VCC), IC10.20 (VCC), IC11.20 (VCC), IC12.20 (VCC), IC13.20 (VCC), IC14.20 (VCC), IC15.20 (VCC), IC16.20 (VCC), IC17.20 (VCC), IC18.20 (VCC), IC19.20 (VCC), IC20.20 (VCC), IC21.20 (VCC), IC22.20 (VCC), IC23.20 (VCC); also elsewhere on the board
WR0: IC8.11 (CLK); also elsewhere on the board
WR1: IC9.11 (CLK); also elsewhere on the board
WR2: IC10.11 (CLK); also elsewhere on the board
WR3: IC11.11 (CLK); also elsewhere on the board
WR4: IC12.11 (CLK); also elsewhere on the board
WR5: IC13.11 (CLK); also elsewhere on the board
WR6: IC14.11 (CLK); also elsewhere on the board
WR7: IC15.11 (CLK); also elsewhere on the board
WR8: IC16.11 (CLK); also elsewhere on the board
WR9: IC17.11 (CLK); also elsewhere on the board
WR10: IC18.11 (CLK); also elsewhere on the board
WR11: IC19.11 (CLK); also elsewhere on the board
WR12: IC20.11 (CLK); also elsewhere on the board
WR13: IC21.11 (CLK); also elsewhere on the board
WR14: IC22.11 (CLK); also elsewhere on the board
WR15: IC23.11 (CLK); also elsewhere on the board

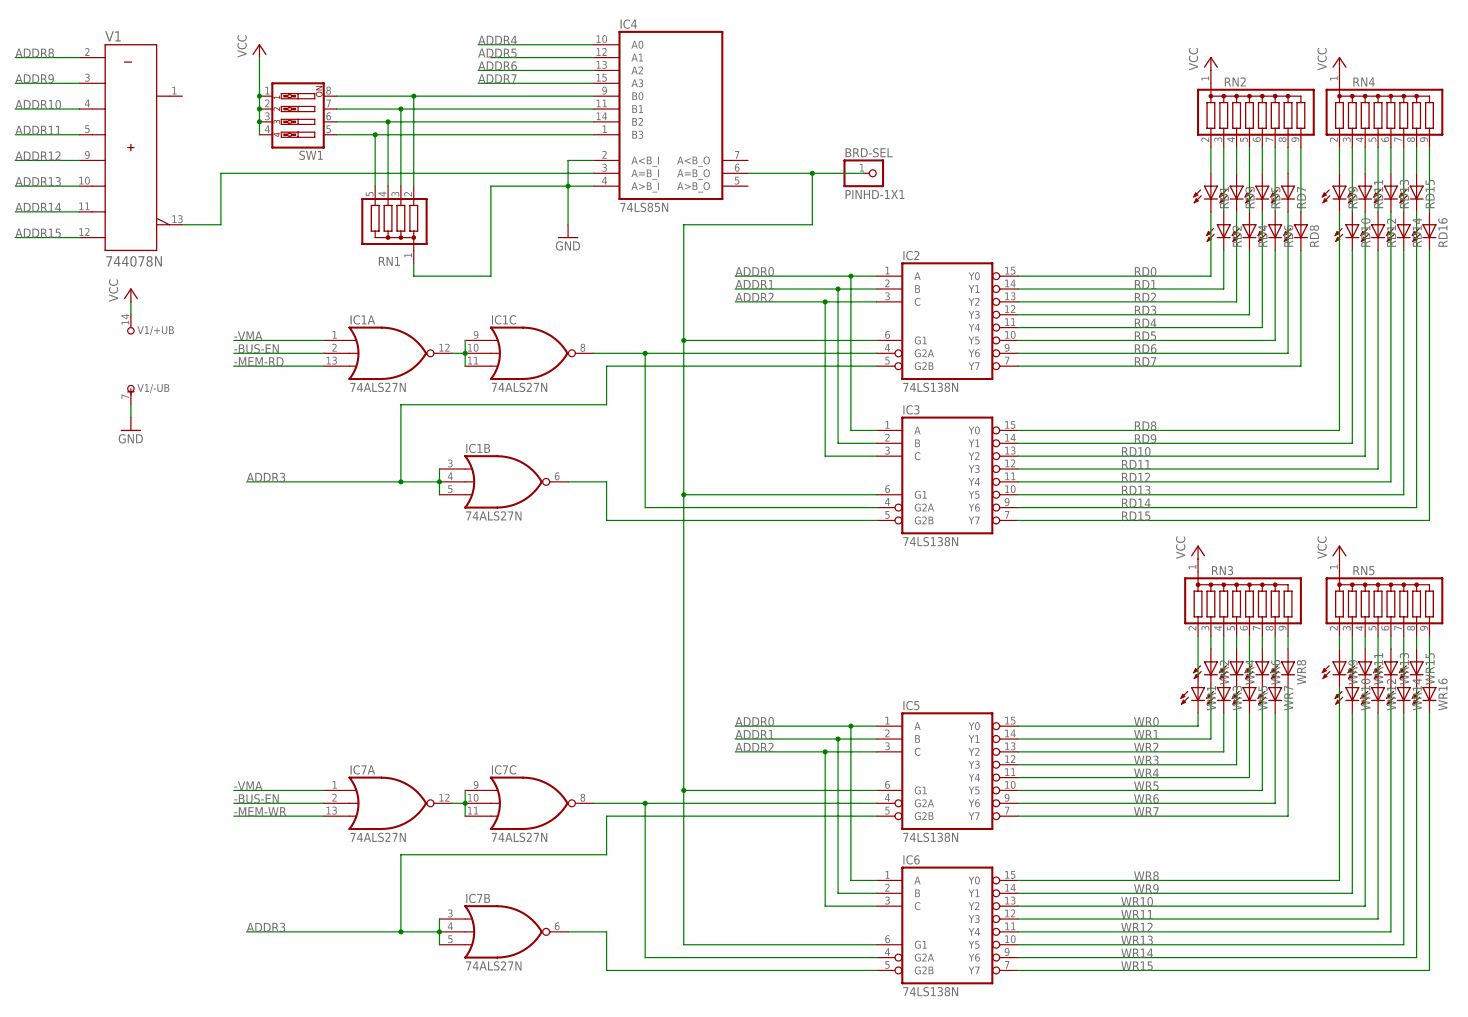
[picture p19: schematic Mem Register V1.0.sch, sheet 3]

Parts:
BRD-SEL: PINHD-1X1; 1X01
IC1, IC7: 74ALS27N; DIL14
IC2, IC3, IC5, IC6: 74LS138N; DIL16
IC4: 74LS85N; DIL16
RD1, RD2, RD3, RD4, RD5, RD6, RD7, RD8, RD9, RD10, RD11, RD12, RD13, RD14, RD15, RD16: LED3MM
RN1: G04R; SIL5
RN2, RN3, RN4, RN5: G08R; SIL9
SW1: SW_DIP-4; EDG-04
V1: 744078N; DIL14
WR1, WR2, WR3, WR4, WR5, WR6, WR7, WR8, WR9, WR10, WR11, WR12, WR13, WR14, WR15, WR16: LED3MM

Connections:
-BUS-EN: IC1.2 (I1), IC7.2 (I1); also elsewhere on the board
-MEM-RD: IC1.13 (I2); also elsewhere on the board
-MEM-WR: IC7.13 (I2); also elsewhere on the board
-VMA: IC1.1 (I0), IC7.1 (I0); also elsewhere on the board
ADDR0: IC2.1 (A), IC3.1 (A), IC5.1 (A), IC6.1 (A); also elsewhere on the board
ADDR1: IC2.2 (B), IC3.2 (B), IC5.2 (B), IC6.2 (B); also elsewhere on the board
ADDR2: IC2.3 (C), IC3.3 (C), IC5.3 (C), IC6.3 (C); also elsewhere on the board
ADDR3: IC1.3 (I0), IC1.4 (I1), IC1.5 (I2), IC2.5 (G2B), IC5.5 (G2B), IC7.3 (I0), IC7.4 (I1), IC7.5 (I2); also elsewhere on the board
ADDR4: IC4.10 (A0); also elsewhere on the board
ADDR5: IC4.12 (A1); also elsewhere on the board
ADDR6: IC4.13 (A2); also elsewhere on the board
ADDR7: IC4.15 (A3); also elsewhere on the board
ADDR8: V1.2 (A); also elsewhere on the board
ADDR9: V1.3 (B); also elsewhere on the board
ADDR10: V1.4 (C); also elsewhere on the board
ADDR11: V1.5 (D); also elsewhere on the board
ADDR12: V1.9 (E); also elsewhere on the board
ADDR13: V1.10 (F); also elsewhere on the board
ADDR14: V1.11 (G); also elsewhere on the board
ADDR15: V1.12 (H); also elsewhere on the board
GND: IC1.7 (GND), IC2.8 (GND), IC3.8 (GND), IC4.2 (A<B_I), IC4.4 (A>B_I), IC4.8 (GND), IC5.8 (GND), IC6.8 (GND), IC7.7 (GND), RN1.1, V1.7 (-UB); also elsewhere on the board
unnamed: RD1.A, RN2.2
unnamed: IC7.9 (I0), IC7.10 (I1), IC7.11 (I2), IC7.12 (O)
unnamed: IC6.5 (G2B), IC7.6 (O)
unnamed: IC5.4 (G2A), IC6.4 (G2A), IC7.8 (O)
unnamed: RD3.A, RN2.4
unnamed: BRD-SEL.1, IC2.6 (G1), IC3.6 (G1), IC4.6 (A=B_O), IC5.6 (G1), IC6.6 (G1)
unnamed: RD2.A, RN2.3
unnamed: IC4.3 (A=B_I), V1.13 (W)
unnamed: RD9.A, RN4.2
unnamed: RD4.A, RN2.5
unnamed: RD5.A, RN2.6
unnamed: RD7.A, RN2.8
unnamed: RD8.A, RN2.9
unnamed: RD6.A, RN2.7
unnamed: RD10.A, RN4.3
unnamed: RD11.A, RN4.4
unnamed: RD12.A, RN4.5
unnamed: IC1.9 (I0), IC1.10 (I1), IC1.11 (I2), IC1.12 (O)
unnamed: RD13.A, RN4.6
unnamed: RD14.A, RN4.7
unnamed: RD15.A, RN4.8
unnamed: RD16.A, RN4.9
unnamed: RN3.2, WR1.A
unnamed: RN3.3, WR2.A
unnamed: RN3.4, WR3.A
unnamed: RN3.5, WR4.A
unnamed: IC4.9 (B0), RN1.2, SW1.8
unnamed: RN3.7, WR6.A
unnamed: RN3.6, WR5.A
unnamed: RN3.8, WR7.A
unnamed: RN3.9, WR8.A
unnamed: RN5.2, WR9.A
unnamed: RN5.4, WR11.A
unnamed: RN5.6, WR13.A
unnamed: RN5.8, WR15.A
unnamed: IC1.6 (O), IC3.5 (G2B)
unnamed: RN5.9, WR16.A
unnamed: RN5.7, WR14.A
unnamed: RN5.5, WR12.A
unnamed: RN5.3, WR10.A
unnamed: IC4.11 (B1), RN1.3, SW1.7
unnamed: IC4.14 (B2), RN1.4, SW1.6
unnamed: IC4.1 (B3), RN1.5, SW1.5
unnamed: IC1.8 (O), IC2.4 (G2A), IC3.4 (G2A)
RD0: IC2.15 (Y0), RD1.K (C); also elsewhere on the board
RD1: IC2.14 (Y1), RD2.K (C); also elsewhere on the board
RD2: IC2.13 (Y2), RD3.K (C); also elsewhere on the board
RD3: IC2.12 (Y3), RD4.K (C); also elsewhere on the board
RD4: IC2.11 (Y4), RD5.K (C); also elsewhere on the board
RD5: IC2.10 (Y5), RD6.K (C); also elsewhere on the board
RD6: IC2.9 (Y6), RD7.K (C); also elsewhere on the board
RD7: IC2.7 (Y7), RD8.K (C); also elsewhere on the board
RD8: IC3.15 (Y0), RD9.K (C); also elsewhere on the board
RD9: IC3.14 (Y1), RD10.K (C); also elsewhere on the board
RD10: IC3.13 (Y2), RD11.K (C); also elsewhere on the board
RD11: IC3.12 (Y3), RD12.K (C); also elsewhere on the board
RD12: IC3.11 (Y4), RD13.K (C); also elsewhere on the board
RD13: IC3.10 (Y5), RD14.K (C); also elsewhere on the board
RD14: IC3.9 (Y6), RD15.K (C); also elsewhere on the board
RD15: IC3.7 (Y7), RD16.K (C); also elsewhere on the board
VCC: IC1.14 (VCC), IC2.16 (VCC), IC3.16 (VCC), IC4.16 (VCC), IC5.16 (VCC), IC6.16 (VCC), IC7.14 (VCC), RN2.1, RN3.1, RN4.1, RN5.1, SW1.1, SW1.2, SW1.3, SW1.4, V1.14 (+UB); also elsewhere on the board
WR0: IC5.15 (Y0), WR1.K (C); also elsewhere on the board
WR1: IC5.14 (Y1), WR2.K (C); also elsewhere on the board
WR2: IC5.13 (Y2), WR3.K (C); also elsewhere on the board
WR3: IC5.12 (Y3), WR4.K (C); also elsewhere on the board
WR4: IC5.11 (Y4), WR5.K (C); also elsewhere on the board
WR5: IC5.10 (Y5), WR6.K (C); also elsewhere on the board
WR6: IC5.9 (Y6), WR7.K (C); also elsewhere on the board
WR7: IC5.7 (Y7), WR8.K (C); also elsewhere on the board
WR8: IC6.15 (Y0), WR9.K (C); also elsewhere on the board
WR9: IC6.14 (Y1), WR10.K (C); also elsewhere on the board
WR10: IC6.13 (Y2), WR11.K (C); also elsewhere on the board
WR11: IC6.12 (Y3), WR12.K (C); also elsewhere on the board
WR12: IC6.11 (Y4), WR13.K (C); also elsewhere on the board
WR13: IC6.10 (Y5), WR14.K (C); also elsewhere on the board
WR14: IC6.9 (Y6), WR15.K (C); also elsewhere on the board
WR15: IC6.7 (Y7), WR16.K (C); also elsewhere on the board

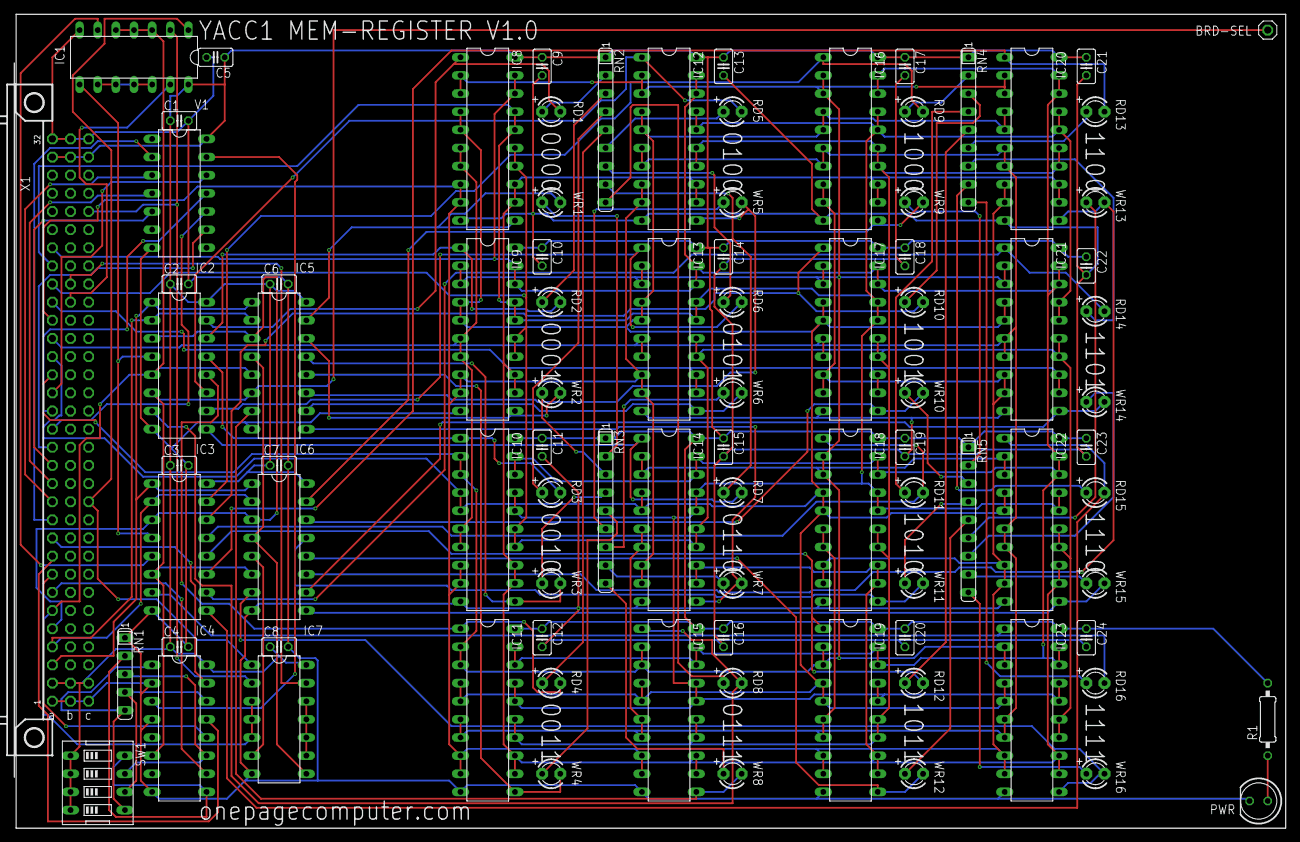
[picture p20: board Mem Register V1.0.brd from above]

Board: 2 copper layers, 177.8 x 114.0 mm, 90 parts (0 on the bottom side), 107 nets.

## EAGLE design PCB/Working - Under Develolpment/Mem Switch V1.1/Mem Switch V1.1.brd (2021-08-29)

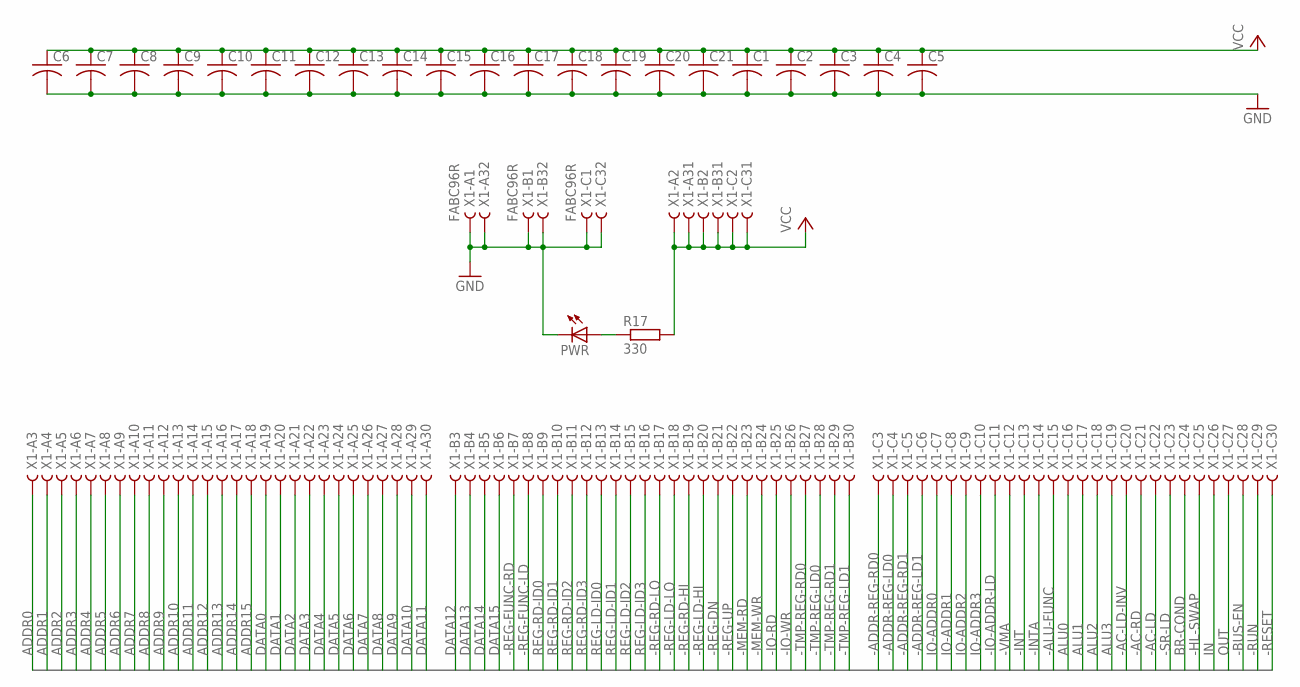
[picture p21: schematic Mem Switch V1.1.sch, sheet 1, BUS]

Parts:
C1, C2, C3, C4, C5, C6, C7, C8, C9, C10, C11, C12, C13, C14, C15, C16, C17, C18, C19, C20, C21: C-US025-025X050; C025-025X050
PWR: LED5MM
R17: 330; 0207/10
X1: FABC96R

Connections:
-AC-LD: X1.C22
-AC-LD-INV: X1.C20
-AC-RD: X1.C21
-ADDR-REG-LD0: X1.C4
-ADDR-REG-LD1: X1.C6
-ADDR-REG-RD0: X1.C3
-ADDR-REG-RD1: X1.C5
-ALU-FUNC: X1.C15
-BUS-EN: X1.C28; also elsewhere on the board
-HL-SWAP: X1.C25
-INT: X1.C13
-INTA: X1.C14
-IO-ADDR-LD: X1.C11
-IO-RD: X1.B25
-IO-WR: X1.B26
-MEM-RD: X1.B23; also elsewhere on the board
-MEM-WR: X1.B24
-REG-DN: X1.B21
-REG-FUNC-LD: X1.B8
-REG-FUNC-RD: X1.B7
-REG-LD-HI: X1.B20
-REG-LD-LO: X1.B18
-REG-RD-HI: X1.B19
-REG-RD-LO: X1.B17
-REG-UP: X1.B22
-RESET: X1.C30
-RUN: X1.C29
-SR-LD: X1.C23
-TMP-REG-LD0: X1.B28
-TMP-REG-LD1: X1.B30
-TMP-REG-RD0: X1.B27
-TMP-REG-RD1: X1.B29
-VMA: X1.C12; also elsewhere on the board
ADDR0: X1.A3; also elsewhere on the board
ADDR1: X1.A4; also elsewhere on the board
ADDR2: X1.A5; also elsewhere on the board
ADDR3: X1.A6; also elsewhere on the board
ADDR4: X1.A7; also elsewhere on the board
ADDR5: X1.A8; also elsewhere on the board
ADDR6: X1.A9; also elsewhere on the board
ADDR7: X1.A10; also elsewhere on the board
ADDR8: X1.A11; also elsewhere on the board
ADDR9: X1.A12; also elsewhere on the board
ADDR10: X1.A13; also elsewhere on the board
ADDR11: X1.A14; also elsewhere on the board
ADDR12: X1.A15; also elsewhere on the board
ADDR13: X1.A16; also elsewhere on the board
ADDR14: X1.A17; also elsewhere on the board
ADDR15: X1.A18; also elsewhere on the board
ALU0: X1.C16
ALU1: X1.C17
ALU2: X1.C18
ALU3: X1.C19
BR-COND: X1.C24
DATA0: X1.A19; also elsewhere on the board
DATA1: X1.A20; also elsewhere on the board
DATA2: X1.A21; also elsewhere on the board
DATA3: X1.A22; also elsewhere on the board
DATA4: X1.A23; also elsewhere on the board
DATA5: X1.A24; also elsewhere on the board
DATA6: X1.A25; also elsewhere on the board
DATA7: X1.A26; also elsewhere on the board
DATA8: X1.A27
DATA9: X1.A28
DATA10: X1.A29
DATA11: X1.A30
DATA12: X1.B3
DATA13: X1.B4
DATA14: X1.B5
DATA15: X1.B6
GND: C1.2, C2.2, C3.2, C4.2, C5.2, C6.2, C7.2, C8.2, C9.2, C10.2, C11.2, C12.2, C13.2, C14.2, C15.2, C16.2, C17.2, C18.2, C19.2, C20.2, C21.2, PWR.K (C), X1.A1, X1.A32, X1.B1, X1.B32, X1.C1, X1.C32; also elsewhere on the board
IN: X1.C26
IO-ADDR0: X1.C7
IO-ADDR1: X1.C8
IO-ADDR2: X1.C9
IO-ADDR3: X1.C10
unnamed: PWR.A, R17.1
OUT: X1.C27
REG-LD-ID0: X1.B13
REG-LD-ID1: X1.B14
REG-LD-ID2: X1.B15
REG-LD-ID3: X1.B16
REG-RD-ID0: X1.B9
REG-RD-ID1: X1.B10
REG-RD-ID2: X1.B11
REG-RD-ID3: X1.B12
VCC: C1.1, C2.1, C3.1, C4.1, C5.1, C6.1, C7.1, C8.1, C9.1, C10.1, C11.1, C12.1, C13.1, C14.1, C15.1, C16.1, C17.1, C18.1, C19.1, C20.1, C21.1, R17.2, X1.A2, X1.A31, X1.B2, X1.B31, X1.C2, X1.C31; also elsewhere on the board

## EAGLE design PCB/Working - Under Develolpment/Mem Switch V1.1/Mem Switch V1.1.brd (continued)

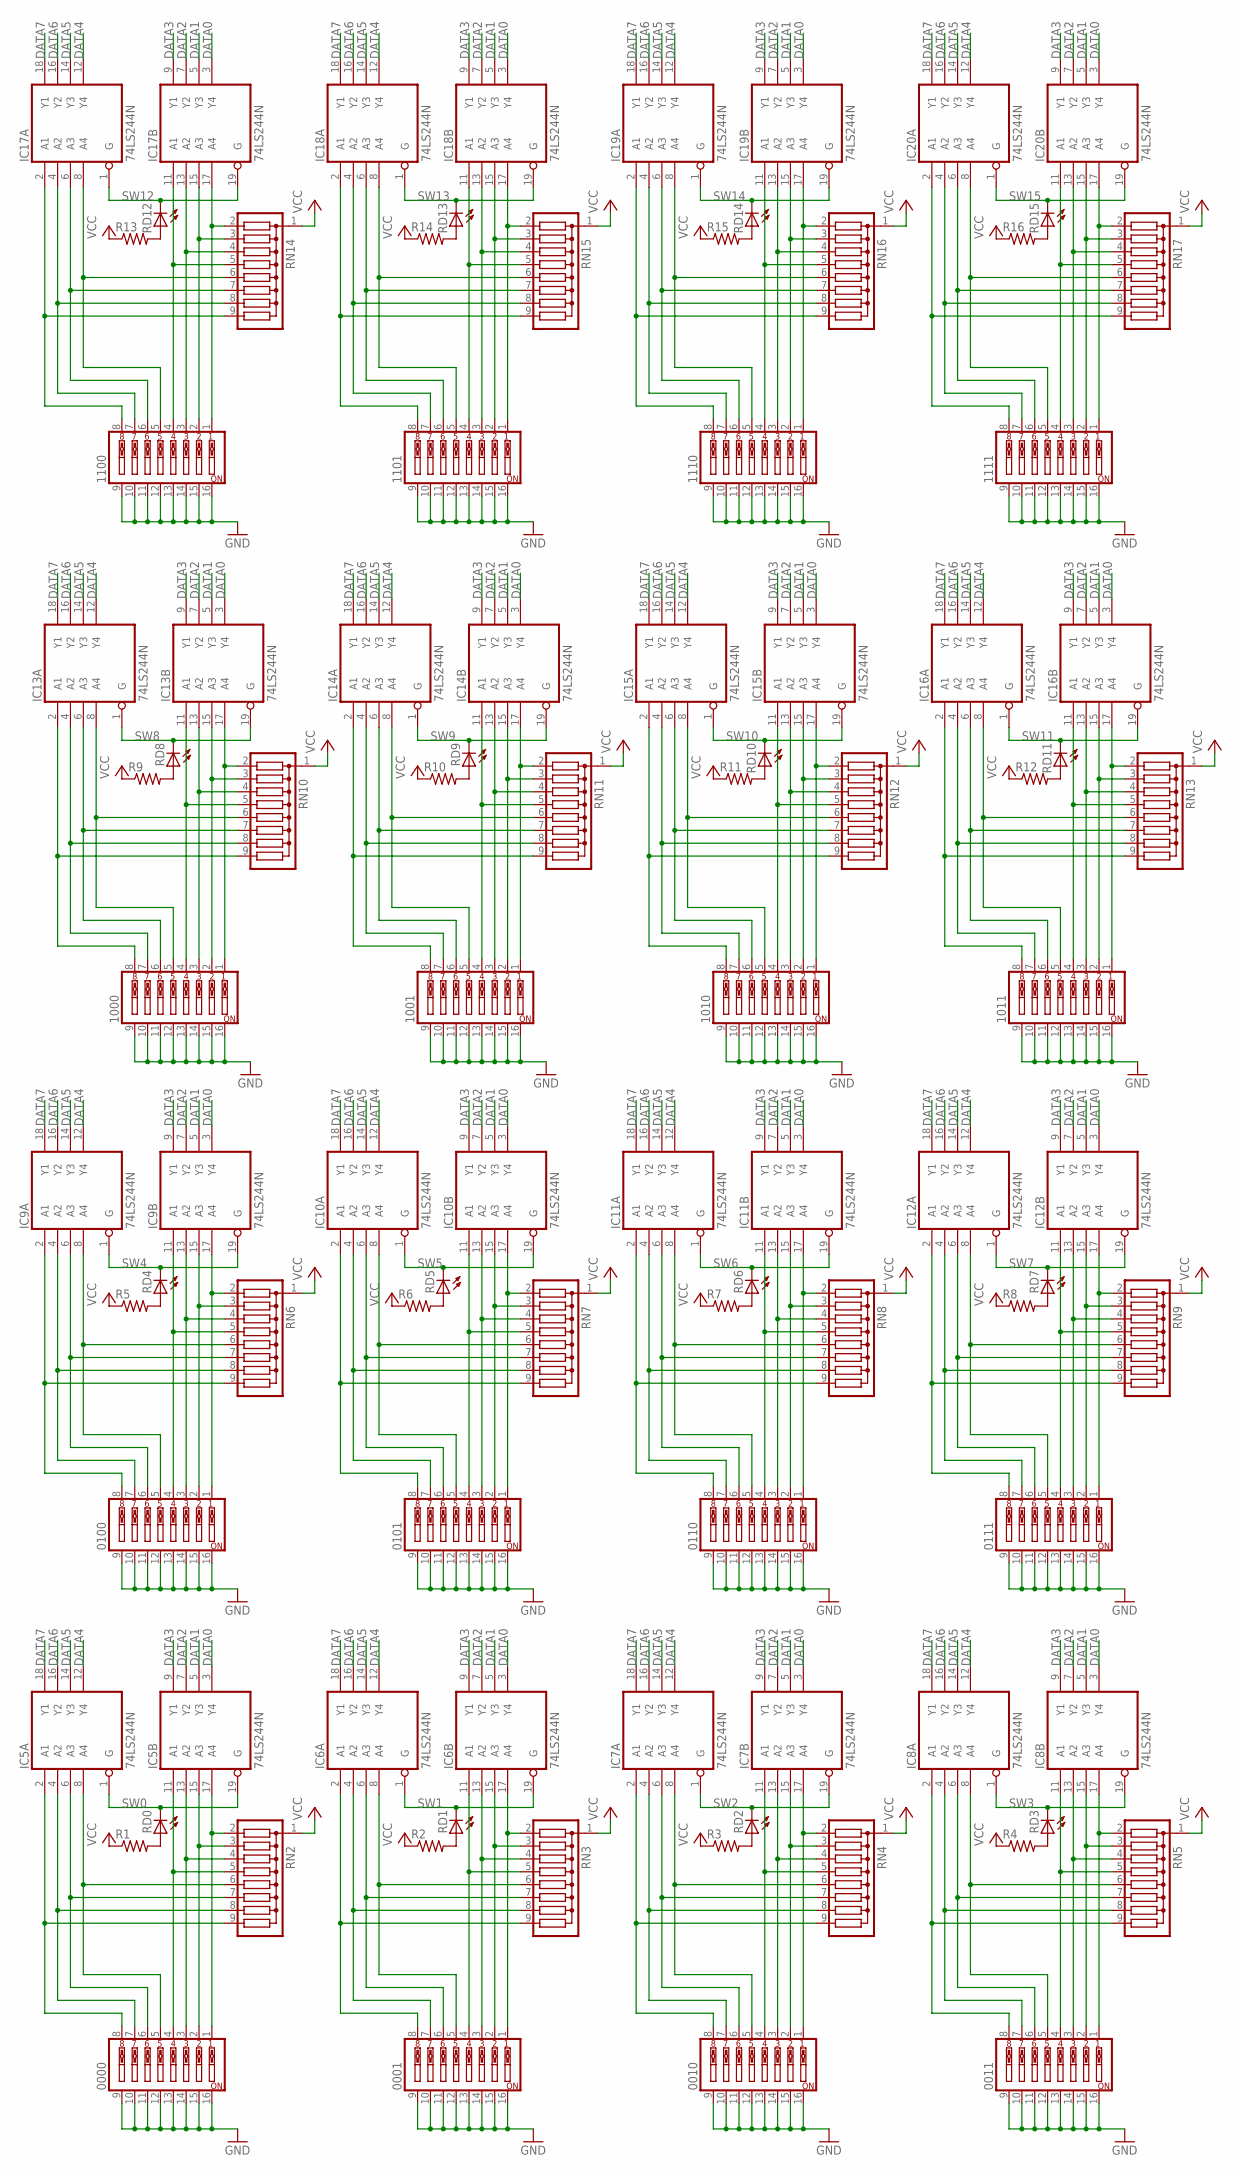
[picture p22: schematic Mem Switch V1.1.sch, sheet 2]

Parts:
0000, 0001, 0010, 0011, 0100, 0101, 0110, 0111, 1000, 1001, 1010, 1011, 1100, 1101, 1110, 1111: SW_DIP-8; EDG-08
IC5, IC6, IC7, IC8, IC9, IC10, IC11, IC12, IC13, IC14, IC15, IC16, IC17, IC18, IC19, IC20: 74LS244N; DIL20
R1, R2, R3, R4, R5, R6, R7, R8, R9, R10, R11, R12, R13, R14, R15, R16: R-US_0207/10; 0207/10
RD0, RD1, RD2, RD3, RD4, RD5, RD6, RD7, RD8, RD9, RD10, RD11, RD12, RD13, RD14, RD15: LED3MM
RN2, RN3, RN4, RN5, RN6, RN7, RN8, RN9, RN10, RN11, RN12, RN13, RN14, RN15, RN16, RN17: G08R; SIL9

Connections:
DATA0: IC5.3 (Y4), IC6.3 (Y4), IC7.3 (Y4), IC8.3 (Y4), IC9.3 (Y4), IC10.3 (Y4), IC11.3 (Y4), IC12.3 (Y4), IC13.3 (Y4), IC14.3 (Y4), IC15.3 (Y4), IC16.3 (Y4), IC17.3 (Y4), IC18.3 (Y4), IC19.3 (Y4), IC20.3 (Y4); also elsewhere on the board
DATA1: IC5.5 (Y3), IC6.5 (Y3), IC7.5 (Y3), IC8.5 (Y3), IC9.5 (Y3), IC10.5 (Y3), IC11.5 (Y3), IC12.5 (Y3), IC13.5 (Y3), IC14.5 (Y3), IC15.5 (Y3), IC16.5 (Y3), IC17.5 (Y3), IC18.5 (Y3), IC19.5 (Y3), IC20.5 (Y3); also elsewhere on the board
DATA2: IC5.7 (Y2), IC6.7 (Y2), IC7.7 (Y2), IC8.7 (Y2), IC9.7 (Y2), IC10.7 (Y2), IC11.7 (Y2), IC12.7 (Y2), IC13.7 (Y2), IC14.7 (Y2), IC15.7 (Y2), IC16.7 (Y2), IC17.7 (Y2), IC18.7 (Y2), IC19.7 (Y2), IC20.7 (Y2); also elsewhere on the board
DATA3: IC5.9 (Y1), IC6.9 (Y1), IC7.9 (Y1), IC8.9 (Y1), IC9.9 (Y1), IC10.9 (Y1), IC11.9 (Y1), IC12.9 (Y1), IC13.9 (Y1), IC14.9 (Y1), IC15.9 (Y1), IC16.9 (Y1), IC17.9 (Y1), IC18.9 (Y1), IC19.9 (Y1), IC20.9 (Y1); also elsewhere on the board
DATA4: IC5.12 (Y4), IC6.12 (Y4), IC7.12 (Y4), IC8.12 (Y4), IC9.12 (Y4), IC10.12 (Y4), IC11.12 (Y4), IC12.12 (Y4), IC13.12 (Y4), IC14.12 (Y4), IC15.12 (Y4), IC16.12 (Y4), IC17.12 (Y4), IC18.12 (Y4), IC19.12 (Y4), IC20.12 (Y4); also elsewhere on the board
DATA5: IC5.14 (Y3), IC6.14 (Y3), IC7.14 (Y3), IC8.14 (Y3), IC9.14 (Y3), IC10.14 (Y3), IC11.14 (Y3), IC12.14 (Y3), IC13.14 (Y3), IC14.14 (Y3), IC15.14 (Y3), IC16.14 (Y3), IC17.14 (Y3), IC18.14 (Y3), IC19.14 (Y3), IC20.14 (Y3); also elsewhere on the board
DATA6: IC5.16 (Y2), IC6.16 (Y2), IC7.16 (Y2), IC8.16 (Y2), IC9.16 (Y2), IC10.16 (Y2), IC11.16 (Y2), IC12.16 (Y2), IC13.16 (Y2), IC14.16 (Y2), IC15.16 (Y2), IC16.16 (Y2), IC17.16 (Y2), IC18.16 (Y2), IC19.16 (Y2), IC20.16 (Y2); also elsewhere on the board
DATA7: IC5.18 (Y1), IC6.18 (Y1), IC7.18 (Y1), IC8.18 (Y1), IC9.18 (Y1), IC10.18 (Y1), IC11.18 (Y1), IC12.18 (Y1), IC13.18 (Y1), IC14.18 (Y1), IC15.18 (Y1), IC16.18 (Y1), IC17.18 (Y1), IC18.18 (Y1), IC19.18 (Y1), IC20.18 (Y1); also elsewhere on the board
GND: 0000.9, 0000.10, 0000.11, 0000.12, 0000.13, 0000.14, 0000.15, 0000.16, 0001.9, 0001.10, 0001.11, 0001.12, 0001.13, 0001.14, 0001.15, 0001.16, 0010.9, 0010.10, 0010.11, 0010.12, 0010.13, 0010.14, 0010.15, 0010.16, 0011.9, 0011.10, 0011.11, 0011.12, 0011.13, 0011.14, 0011.15, 0011.16, 0100.9, 0100.10, 0100.11, 0100.12, 0100.13, 0100.14, 0100.15, 0100.16, 0101.9, 0101.10, 0101.11, 0101.12, 0101.13, 0101.14, 0101.15, 0101.16, 0110.9, 0110.10, 0110.11, 0110.12, 0110.13, 0110.14, 0110.15, 0110.16, 0111.9, 0111.10, 0111.11, 0111.12, 0111.13, 0111.14, 0111.15, 0111.16, 1000.9, 1000.10, 1000.11, 1000.12, 1000.13, 1000.14, 1000.15, 1000.16, 1001.9, 1001.10, 1001.11, 1001.12, 1001.13, 1001.14, 1001.15, 1001.16, 1010.9, 1010.10, 1010.11, 1010.12, 1010.13, 1010.14, 1010.15, 1010.16, 1011.9, 1011.10, 1011.11, 1011.12, 1011.13, 1011.14, 1011.15, 1011.16, 1100.9, 1100.10, 1100.11, 1100.12, 1100.13, 1100.14, 1100.15, 1100.16, 1101.9, 1101.10, 1101.11, 1101.12, 1101.13, 1101.14, 1101.15, 1101.16, 1110.9, 1110.10, 1110.11, 1110.12, 1110.13, 1110.14, 1110.15, 1110.16, 1111.9, 1111.10, 1111.11, 1111.12, 1111.13, 1111.14, 1111.15, 1111.16, IC5.10 (GND), IC6.10 (GND), IC7.10 (GND), IC8.10 (GND), IC9.10 (GND), IC10.10 (GND), IC11.10 (GND), IC12.10 (GND), IC13.10 (GND), IC14.10 (GND), IC15.10 (GND), IC16.10 (GND), IC17.10 (GND), IC18.10 (GND), IC19.10 (GND), IC20.10 (GND); also elsewhere on the board
unnamed: 0000.1, IC5.17 (A4), RN2.2
unnamed: 0000.2, IC5.15 (A3), RN2.3
unnamed: 0000.3, IC5.13 (A2), RN2.4
unnamed: 0000.4, IC5.11 (A1), RN2.5
unnamed: 0000.5, IC5.8 (A4), RN2.6
unnamed: 0000.6, IC5.6 (A3), RN2.7
unnamed: 0000.7, IC5.4 (A2), RN2.8
unnamed: 0000.8, IC5.2 (A1), RN2.9
unnamed: 0001.1, IC6.17 (A4), RN3.2
unnamed: 0001.2, IC6.15 (A3), RN3.3
unnamed: 0001.3, IC6.13 (A2), RN3.4
unnamed: 0001.4, IC6.11 (A1), RN3.5
unnamed: 0001.5, IC6.8 (A4), RN3.6
unnamed: 0001.6, IC6.6 (A3), RN3.7
unnamed: 0001.7, IC6.4 (A2), RN3.8
unnamed: 0001.8, IC6.2 (A1), RN3.9
unnamed: 0010.1, IC7.17 (A4), RN4.2
unnamed: 0010.2, IC7.15 (A3), RN4.3
unnamed: 0010.3, IC7.13 (A2), RN4.4
unnamed: 0010.4, IC7.11 (A1), RN4.5
unnamed: 0010.5, IC7.8 (A4), RN4.6
unnamed: 0010.6, IC7.6 (A3), RN4.7
unnamed: 0010.7, IC7.4 (A2), RN4.8
unnamed: 0010.8, IC7.2 (A1), RN4.9
unnamed: 0011.1, IC8.17 (A4), RN5.2
unnamed: 0011.2, IC8.15 (A3), RN5.3
unnamed: 0011.3, IC8.13 (A2), RN5.4
unnamed: 0011.4, IC8.11 (A1), RN5.5
unnamed: 0011.5, IC8.8 (A4), RN5.6
unnamed: 0011.6, IC8.6 (A3), RN5.7
unnamed: 0011.7, IC8.4 (A2), RN5.8
unnamed: 0011.8, IC8.2 (A1), RN5.9
unnamed: 0100.1, IC9.17 (A4), RN6.2
unnamed: 0100.2, IC9.15 (A3), RN6.3
unnamed: 0100.3, IC9.13 (A2), RN6.4
unnamed: 0100.4, IC9.11 (A1), RN6.5
unnamed: 0100.5, IC9.8 (A4), RN6.6
unnamed: 0100.6, IC9.6 (A3), RN6.7
unnamed: 0100.7, IC9.4 (A2), RN6.8
unnamed: 0100.8, IC9.2 (A1), RN6.9
unnamed: 0101.1, IC10.17 (A4), RN7.2
unnamed: 0101.2, IC10.15 (A3), RN7.3
unnamed: 0101.3, IC10.13 (A2), RN7.4
unnamed: 0101.4, IC10.11 (A1), RN7.5
unnamed: 0101.5, IC10.8 (A4), RN7.6
unnamed: 0101.6, IC10.6 (A3), RN7.7
unnamed: 0101.7, IC10.4 (A2), RN7.8
unnamed: 0101.8, IC10.2 (A1), RN7.9
unnamed: 0110.1, IC11.17 (A4), RN8.2
unnamed: 0110.2, IC11.15 (A3), RN8.3
unnamed: 0110.3, IC11.13 (A2), RN8.4
unnamed: 0110.4, IC11.11 (A1), RN8.5
unnamed: 0110.5, IC11.8 (A4), RN8.6
unnamed: 0110.6, IC11.6 (A3), RN8.7
unnamed: 0110.7, IC11.4 (A2), RN8.8
unnamed: 0110.8, IC11.2 (A1), RN8.9
unnamed: 0111.1, IC12.17 (A4), RN9.2
unnamed: 0111.2, IC12.15 (A3), RN9.3
unnamed: 0111.3, IC12.13 (A2), RN9.4
unnamed: 0111.4, IC12.11 (A1), RN9.5
unnamed: 0111.5, IC12.8 (A4), RN9.6
unnamed: 0111.6, IC12.6 (A3), RN9.7
unnamed: 0111.7, IC12.4 (A2), RN9.8
unnamed: 0111.8, IC12.2 (A1), RN9.9
unnamed: 1000.1, IC13.17 (A4), RN10.2
unnamed: 1000.2, IC13.15 (A3), RN10.3
unnamed: 1000.3, IC13.13 (A2), RN10.4
unnamed: 1000.4, IC13.11 (A1), RN10.5
unnamed: 1000.5, IC13.8 (A4), RN10.6
unnamed: 1000.6, IC13.6 (A3), RN10.7
unnamed: 1000.7, IC13.4 (A2), RN10.8
unnamed: 1000.8, IC13.2 (A1), RN10.9
unnamed: 1001.1, IC14.17 (A4), RN11.2
unnamed: 1001.2, IC14.15 (A3), RN11.3
unnamed: 1001.3, IC14.13 (A2), RN11.4
unnamed: 1001.4, IC14.11 (A1), RN11.5
unnamed: 1001.5, IC14.8 (A4), RN11.6
unnamed: 1001.6, IC14.6 (A3), RN11.7
unnamed: 1001.7, IC14.4 (A2), RN11.8
unnamed: 1001.8, IC14.2 (A1), RN11.9
unnamed: R1.2, RD0.A
unnamed: 1010.1, IC15.17 (A4), RN12.2
unnamed: 1010.2, IC15.15 (A3), RN12.3
unnamed: 1010.3, IC15.13 (A2), RN12.4
unnamed: 1010.4, IC15.11 (A1), RN12.5
unnamed: 1010.5, IC15.8 (A4), RN12.6
unnamed: 1010.6, IC15.6 (A3), RN12.7
unnamed: 1010.7, IC15.4 (A2), RN12.8
unnamed: 1010.8, IC15.2 (A1), RN12.9
unnamed: R2.2, RD1.A
unnamed: 1011.1, IC16.17 (A4), RN13.2
unnamed: 1011.2, IC16.15 (A3), RN13.3
unnamed: 1011.3, IC16.13 (A2), RN13.4
unnamed: 1011.4, IC16.11 (A1), RN13.5
unnamed: 1011.5, IC16.8 (A4), RN13.6
unnamed: 1011.6, IC16.6 (A3), RN13.7
unnamed: 1011.7, IC16.4 (A2), RN13.8
unnamed: 1011.8, IC16.2 (A1), RN13.9
unnamed: R3.2, RD2.A
unnamed: 1100.1, IC17.17 (A4), RN14.2
unnamed: 1100.2, IC17.15 (A3), RN14.3
unnamed: 1100.3, IC17.13 (A2), RN14.4
unnamed: 1100.4, IC17.11 (A1), RN14.5
unnamed: 1100.5, IC17.8 (A4), RN14.6
unnamed: 1100.6, IC17.6 (A3), RN14.7
unnamed: 1100.7, IC17.4 (A2), RN14.8
unnamed: 1100.8, IC17.2 (A1), RN14.9
unnamed: R4.2, RD3.A
unnamed: 1101.1, IC18.17 (A4), RN15.2
unnamed: 1101.2, IC18.15 (A3), RN15.3
unnamed: 1101.3, IC18.13 (A2), RN15.4
unnamed: 1101.4, IC18.11 (A1), RN15.5
unnamed: 1101.5, IC18.8 (A4), RN15.6
unnamed: 1101.6, IC18.6 (A3), RN15.7
unnamed: 1101.7, IC18.4 (A2), RN15.8
unnamed: 1101.8, IC18.2 (A1), RN15.9
unnamed: R5.2, RD4.A
unnamed: 1110.1, IC19.17 (A4), RN16.2
unnamed: 1110.2, IC19.15 (A3), RN16.3
unnamed: 1110.3, IC19.13 (A2), RN16.4
unnamed: 1110.4, IC19.11 (A1), RN16.5
unnamed: 1110.5, IC19.8 (A4), RN16.6
unnamed: 1110.6, IC19.6 (A3), RN16.7
unnamed: 1110.7, IC19.4 (A2), RN16.8
unnamed: 1110.8, IC19.2 (A1), RN16.9
unnamed: R6.2, RD5.A
unnamed: 1111.1, IC20.17 (A4), RN17.2
unnamed: 1111.2, IC20.15 (A3), RN17.3
unnamed: 1111.3, IC20.13 (A2), RN17.4
unnamed: 1111.4, IC20.11 (A1), RN17.5
unnamed: 1111.5, IC20.8 (A4), RN17.6
unnamed: 1111.6, IC20.6 (A3), RN17.7
unnamed: 1111.7, IC20.4 (A2), RN17.8
unnamed: 1111.8, IC20.2 (A1), RN17.9
unnamed: R7.2, RD6.A
unnamed: R8.2, RD7.A
unnamed: R9.2, RD8.A
unnamed: R10.2, RD9.A
unnamed: R11.2, RD10.A
unnamed: R12.2, RD11.A
unnamed: R13.2, RD12.A
unnamed: R14.2, RD13.A
unnamed: R15.2, RD14.A
unnamed: R16.2, RD15.A
SW0: IC5.1 (G), IC5.19 (G), RD0.K (C); also elsewhere on the board
SW1: IC6.1 (G), IC6.19 (G), RD1.K (C); also elsewhere on the board
SW2: IC7.1 (G), IC7.19 (G), RD2.K (C); also elsewhere on the board
SW3: IC8.1 (G), IC8.19 (G), RD3.K (C); also elsewhere on the board
SW4: IC9.1 (G), IC9.19 (G), RD4.K (C); also elsewhere on the board
SW5: IC10.1 (G), IC10.19 (G), RD5.K (C); also elsewhere on the board
SW6: IC11.1 (G), IC11.19 (G), RD6.K (C); also elsewhere on the board
SW7: IC12.1 (G), IC12.19 (G), RD7.K (C); also elsewhere on the board
SW8: IC13.1 (G), IC13.19 (G), RD8.K (C); also elsewhere on the board
SW9: IC14.1 (G), IC14.19 (G), RD9.K (C); also elsewhere on the board
SW10: IC15.1 (G), IC15.19 (G), RD10.K (C); also elsewhere on the board
SW11: IC16.1 (G), IC16.19 (G), RD11.K (C); also elsewhere on the board
SW12: IC17.1 (G), IC17.19 (G), RD12.K (C); also elsewhere on the board
SW13: IC18.1 (G), IC18.19 (G), RD13.K (C); also elsewhere on the board
SW14: IC19.1 (G), IC19.19 (G), RD14.K (C); also elsewhere on the board
SW15: IC20.1 (G), IC20.19 (G), RD15.K (C); also elsewhere on the board
VCC: IC5.20 (VCC), IC6.20 (VCC), IC7.20 (VCC), IC8.20 (VCC), IC9.20 (VCC), IC10.20 (VCC), IC11.20 (VCC), IC12.20 (VCC), IC13.20 (VCC), IC14.20 (VCC), IC15.20 (VCC), IC16.20 (VCC), IC17.20 (VCC), IC18.20 (VCC), IC19.20 (VCC), IC20.20 (VCC), R1.1, R2.1, R3.1, R4.1, R5.1, R6.1, R7.1, R8.1, R9.1, R10.1, R11.1, R12.1, R13.1, R14.1, R15.1, R16.1, RN2.1, RN3.1, RN4.1, RN5.1, RN6.1, RN7.1, RN8.1, RN9.1, RN10.1, RN11.1, RN12.1, RN13.1, RN14.1, RN15.1, RN16.1, RN17.1; also elsewhere on the board

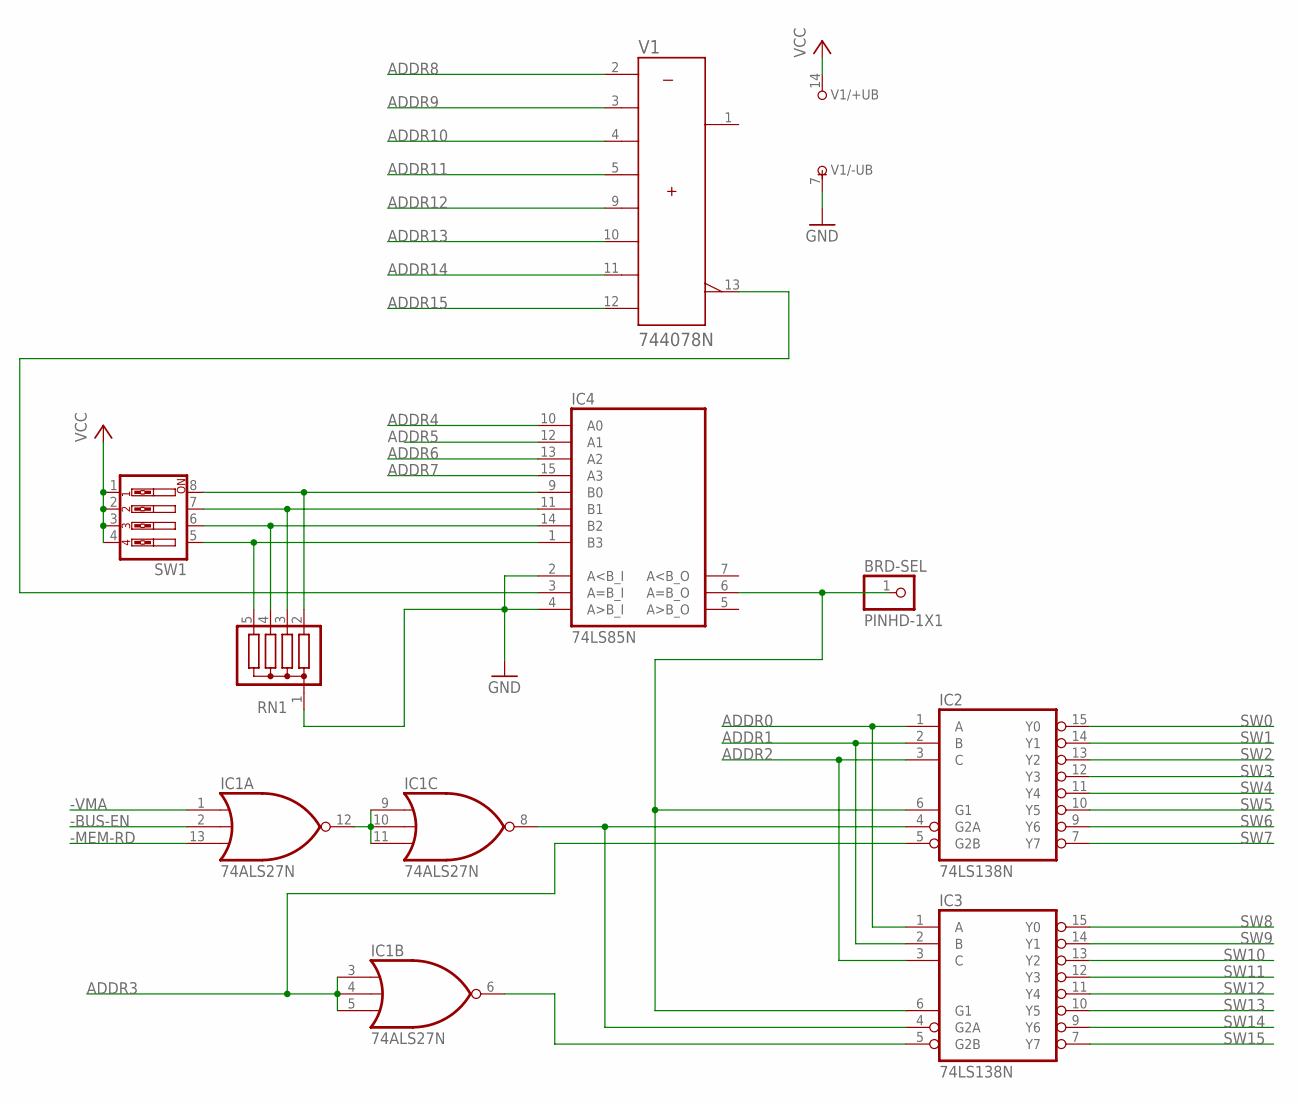
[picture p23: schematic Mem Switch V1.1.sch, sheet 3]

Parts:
BRD-SEL: PINHD-1X1; 1X01
IC1: 74ALS27N; DIL14
IC2, IC3: 74LS138N; DIL16
IC4: 74LS85N; DIL16
RN1: G04R; SIL5
SW1: SW_DIP-4; EDG-04
V1: 744078N; DIL14

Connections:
-BUS-EN: IC1.2 (I1); also elsewhere on the board
-MEM-RD: IC1.13 (I2); also elsewhere on the board
-VMA: IC1.1 (I0); also elsewhere on the board
ADDR0: IC2.1 (A), IC3.1 (A); also elsewhere on the board
ADDR1: IC2.2 (B), IC3.2 (B); also elsewhere on the board
ADDR2: IC2.3 (C), IC3.3 (C); also elsewhere on the board
ADDR3: IC1.3 (I0), IC1.4 (I1), IC1.5 (I2), IC2.5 (G2B); also elsewhere on the board
ADDR4: IC4.10 (A0); also elsewhere on the board
ADDR5: IC4.12 (A1); also elsewhere on the board
ADDR6: IC4.13 (A2); also elsewhere on the board
ADDR7: IC4.15 (A3); also elsewhere on the board
ADDR8: V1.2 (A); also elsewhere on the board
ADDR9: V1.3 (B); also elsewhere on the board
ADDR10: V1.4 (C); also elsewhere on the board
ADDR11: V1.5 (D); also elsewhere on the board
ADDR12: V1.9 (E); also elsewhere on the board
ADDR13: V1.10 (F); also elsewhere on the board
ADDR14: V1.11 (G); also elsewhere on the board
ADDR15: V1.12 (H); also elsewhere on the board
GND: IC1.7 (GND), IC2.8 (GND), IC3.8 (GND), IC4.2 (A<B_I), IC4.4 (A>B_I), IC4.8 (GND), RN1.1, V1.7 (-UB); also elsewhere on the board
unnamed: BRD-SEL.1, IC2.6 (G1), IC3.6 (G1), IC4.6 (A=B_O)
unnamed: IC1.9 (I0), IC1.10 (I1), IC1.11 (I2), IC1.12 (O)
unnamed: IC4.9 (B0), RN1.2, SW1.8
unnamed: IC1.6 (O), IC3.5 (G2B)
unnamed: IC4.11 (B1), RN1.3, SW1.7
unnamed: IC4.3 (A=B_I), V1.13 (W)
unnamed: IC4.14 (B2), RN1.4, SW1.6
unnamed: IC4.1 (B3), RN1.5, SW1.5
unnamed: IC1.8 (O), IC2.4 (G2A), IC3.4 (G2A)
SW0: IC2.15 (Y0); also elsewhere on the board
SW1: IC2.14 (Y1); also elsewhere on the board
SW2: IC2.13 (Y2); also elsewhere on the board
SW3: IC2.12 (Y3); also elsewhere on the board
SW4: IC2.11 (Y4); also elsewhere on the board
SW5: IC2.10 (Y5); also elsewhere on the board
SW6: IC2.9 (Y6); also elsewhere on the board
SW7: IC2.7 (Y7); also elsewhere on the board
SW8: IC3.15 (Y0); also elsewhere on the board
SW9: IC3.14 (Y1); also elsewhere on the board
SW10: IC3.13 (Y2); also elsewhere on the board
SW11: IC3.12 (Y3); also elsewhere on the board
SW12: IC3.11 (Y4); also elsewhere on the board
SW13: IC3.10 (Y5); also elsewhere on the board
SW14: IC3.9 (Y6); also elsewhere on the board
SW15: IC3.7 (Y7); also elsewhere on the board
VCC: IC1.14 (VCC), IC2.16 (VCC), IC3.16 (VCC), IC4.16 (VCC), SW1.1, SW1.2, SW1.3, SW1.4, V1.14 (+UB); also elsewhere on the board

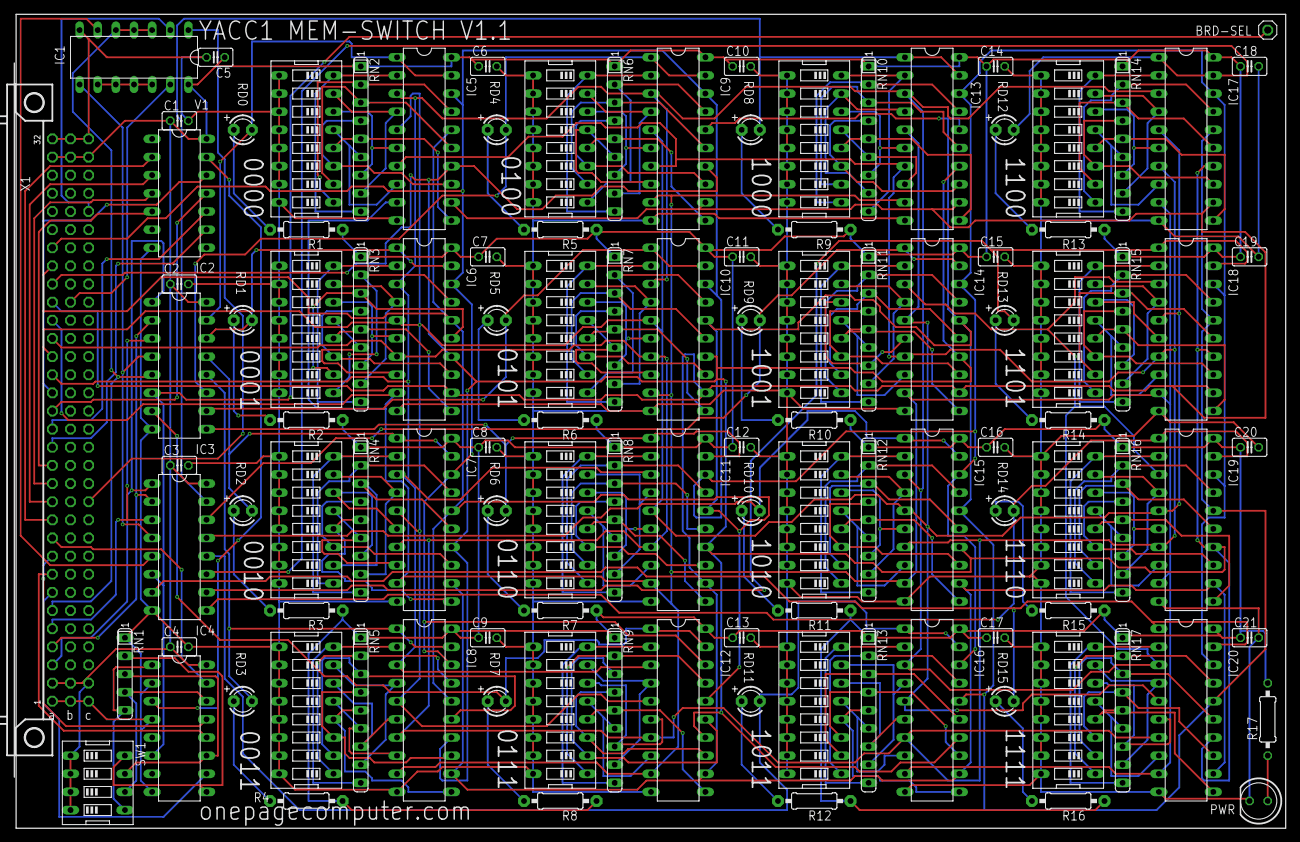
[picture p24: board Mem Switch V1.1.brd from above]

Board: 2 copper layers, 177.8 x 114.0 mm, 112 parts (0 on the bottom side), 199 nets.

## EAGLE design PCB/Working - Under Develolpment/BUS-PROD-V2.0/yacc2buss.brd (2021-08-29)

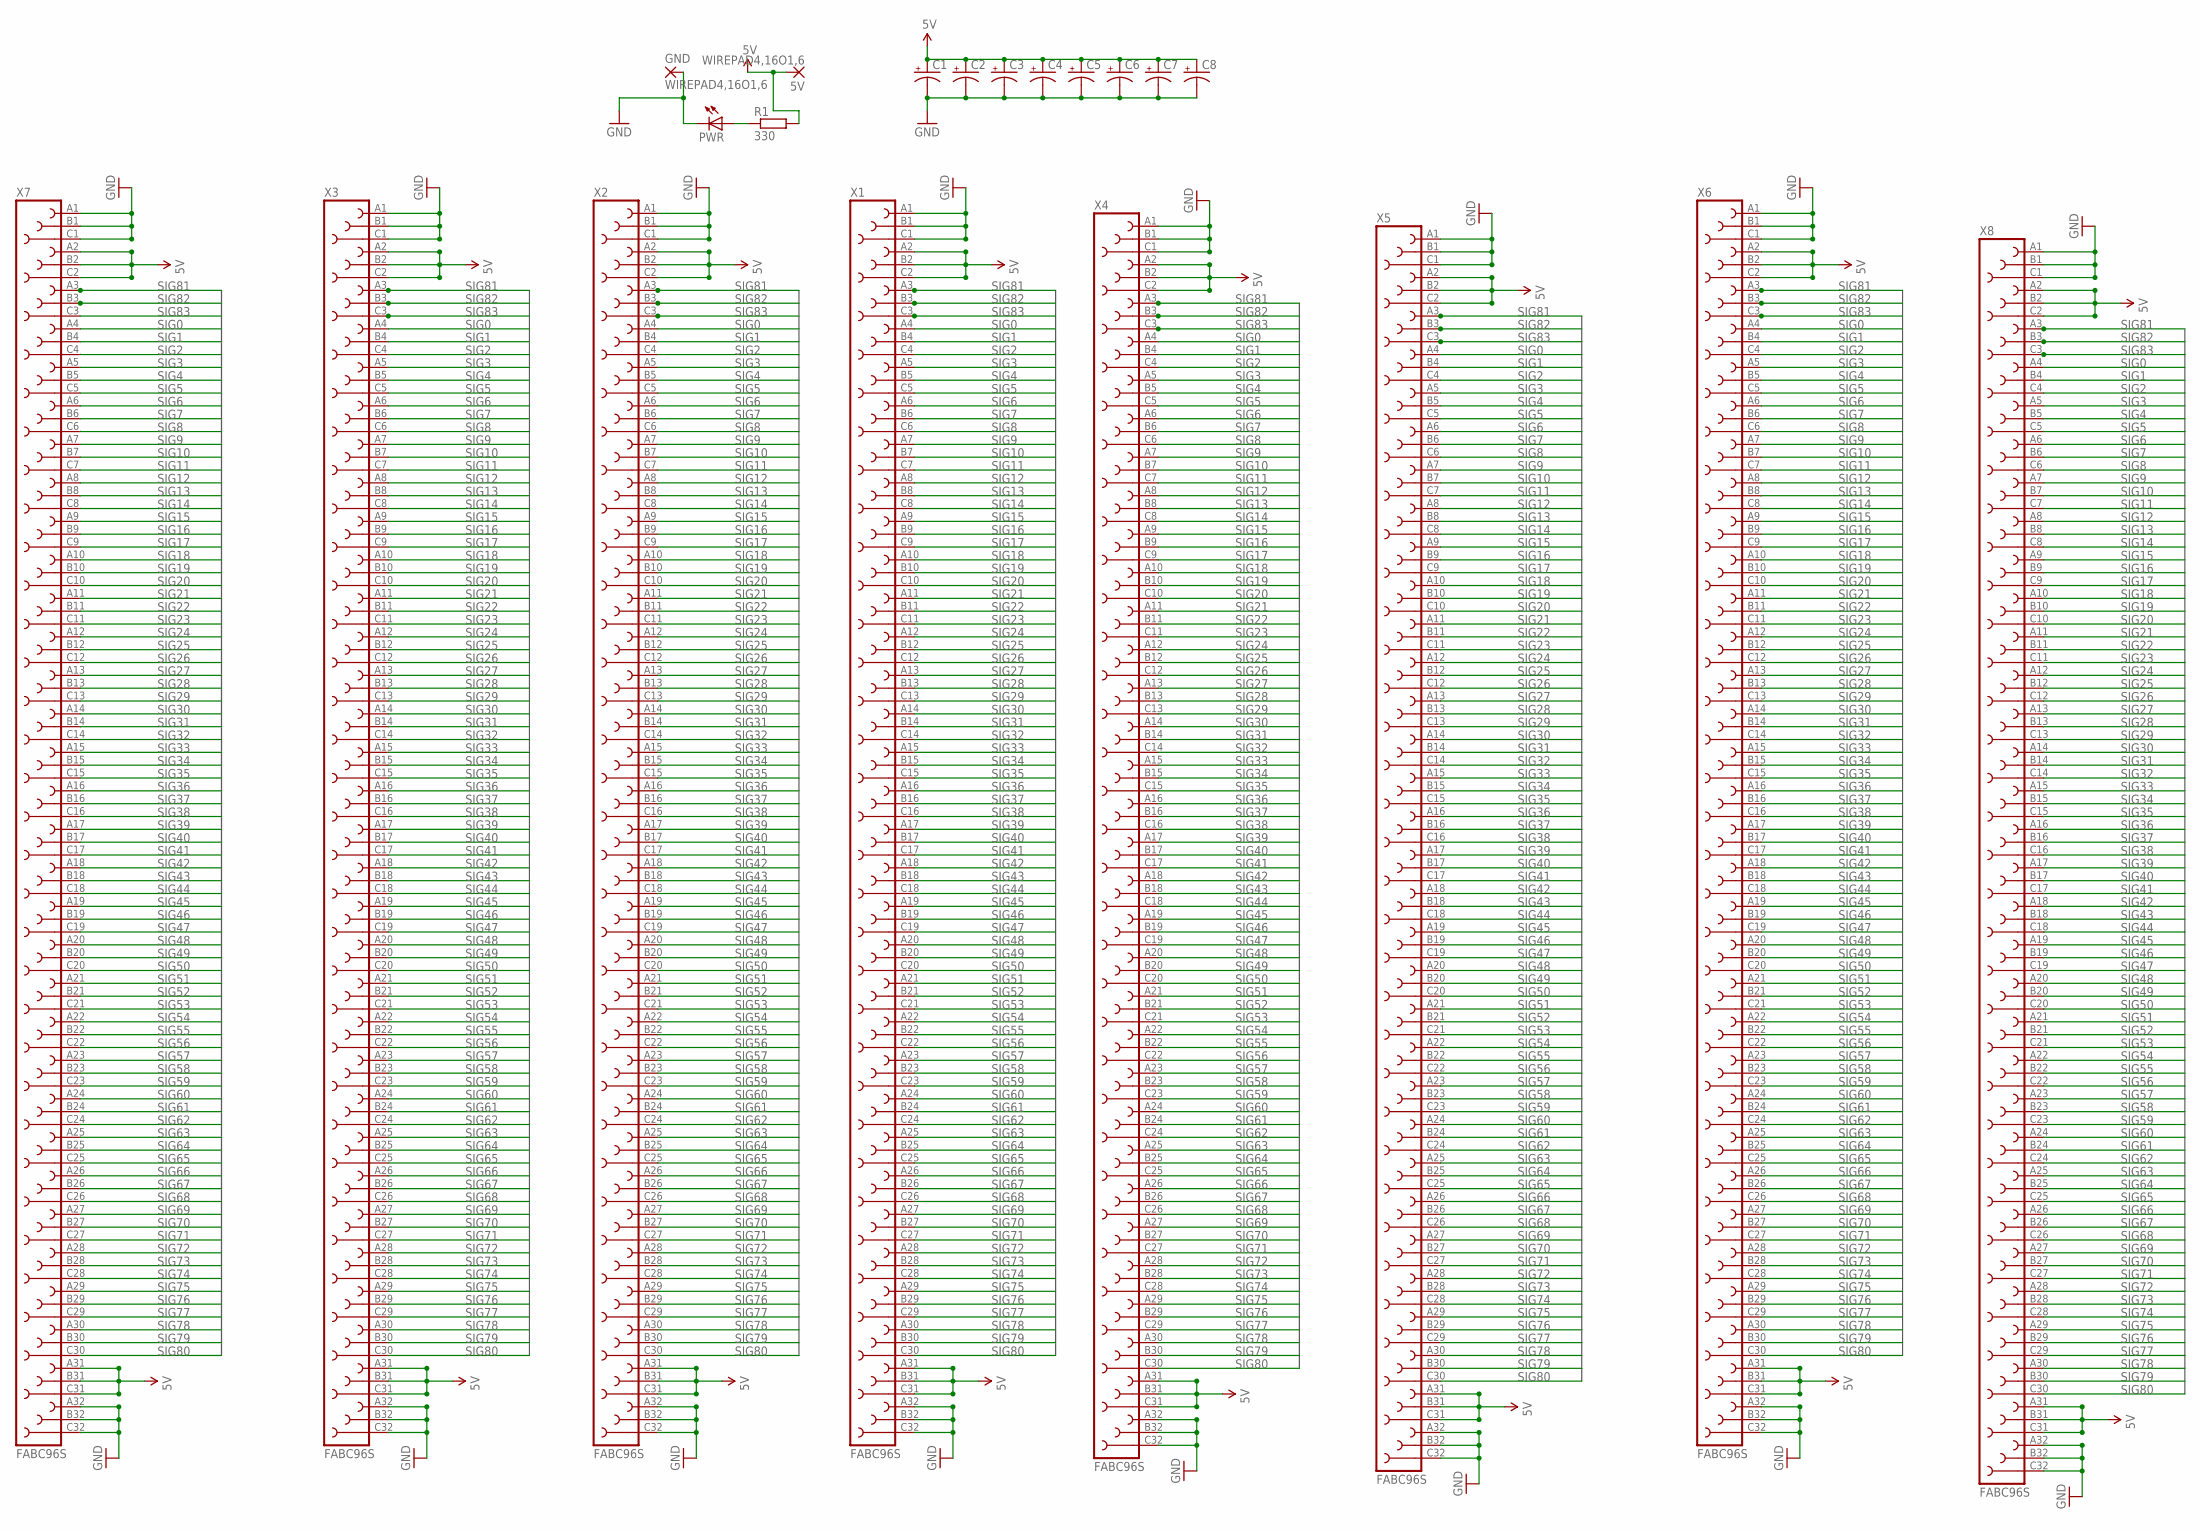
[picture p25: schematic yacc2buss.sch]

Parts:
5V: WIREPAD4,16O1,6; 4,16O1,6
C1, C2, C3, C4, C5, C6, C7, C8: CPOL-USE5-6; E5-6
GND: WIREPAD4,16O1,6; 4,16O1,6
PWR: LED5MM
R1: 330; 0207/10
X1, X2, X3, X4, X5, X6, X7, X8: FABC96S

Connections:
5V: 5V.1, C1.+, C2.+, C3.+, C4.+, C5.+, C6.+, C7.+, C8.+, R1.2, X1.A2, X1.A31, X1.B2, X1.B31, X1.C2, X1.C31, X2.A2, X2.A31, X2.B2, X2.B31, X2.C2, X2.C31, X3.A2, X3.A31, X3.B2, X3.B31, X3.C2, X3.C31, X4.A2, X4.A31, X4.B2, X4.B31, X4.C2, X4.C31, X5.A2, X5.A31, X5.B2, X5.B31, X5.C2, X5.C31, X6.A2, X6.A31, X6.B2, X6.B31, X6.C2, X6.C31, X7.A2, X7.A31, X7.B2, X7.B31, X7.C2, X7.C31, X8.A2, X8.A31, X8.B2, X8.B31, X8.C2, X8.C31
GND: C1.-, C2.-, C3.-, C4.-, C5.-, C6.-, C7.-, C8.-, GND.1, PWR.K (C), X1.A1, X1.A32, X1.B1, X1.B32, X1.C1, X1.C32, X2.A1, X2.A32, X2.B1, X2.B32, X2.C1, X2.C32, X3.A1, X3.A32, X3.B1, X3.B32, X3.C1, X3.C32, X4.A1, X4.A32, X4.B1, X4.B32, X4.C1, X4.C32, X5.A1, X5.A32, X5.B1, X5.B32, X5.C1, X5.C32, X6.A1, X6.A32, X6.B1, X6.B32, X6.C1, X6.C32, X7.A1, X7.A32, X7.B1, X7.B32, X7.C1, X7.C32, X8.A1, X8.A32, X8.B1, X8.B32, X8.C1, X8.C32
unnamed: PWR.A, R1.1
SIG0: X1.A4, X2.A4, X3.A4, X4.A4, X5.A4, X6.A4, X7.A4, X8.A4
SIG1: X1.B4, X2.B4, X3.B4, X4.B4, X5.B4, X6.B4, X7.B4, X8.B4
SIG2: X1.C4, X2.C4, X3.C4, X4.C4, X5.C4, X6.C4, X7.C4, X8.C4
SIG3: X1.A5, X2.A5, X3.A5, X4.A5, X5.A5, X6.A5, X7.A5, X8.A5
SIG4: X1.B5, X2.B5, X3.B5, X4.B5, X5.B5, X6.B5, X7.B5, X8.B5
SIG5: X1.C5, X2.C5, X3.C5, X4.C5, X5.C5, X6.C5, X7.C5, X8.C5
SIG6: X1.A6, X2.A6, X3.A6, X4.A6, X5.A6, X6.A6, X7.A6, X8.A6
SIG7: X1.B6, X2.B6, X3.B6, X4.B6, X5.B6, X6.B6, X7.B6, X8.B6
SIG8: X1.C6, X2.C6, X3.C6, X4.C6, X5.C6, X6.C6, X7.C6, X8.C6
SIG9: X1.A7, X2.A7, X3.A7, X4.A7, X5.A7, X6.A7, X7.A7, X8.A7
SIG10: X1.B7, X2.B7, X3.B7, X4.B7, X5.B7, X6.B7, X7.B7, X8.B7
SIG11: X1.C7, X2.C7, X3.C7, X4.C7, X5.C7, X6.C7, X7.C7, X8.C7
SIG12: X1.A8, X2.A8, X3.A8, X4.A8, X5.A8, X6.A8, X7.A8, X8.A8
SIG13: X1.B8, X2.B8, X3.B8, X4.B8, X5.B8, X6.B8, X7.B8, X8.B8
SIG14: X1.C8, X2.C8, X3.C8, X4.C8, X5.C8, X6.C8, X7.C8, X8.C8
SIG15: X1.A9, X2.A9, X3.A9, X4.A9, X5.A9, X6.A9, X7.A9, X8.A9
SIG16: X1.B9, X2.B9, X3.B9, X4.B9, X5.B9, X6.B9, X7.B9, X8.B9
SIG17: X1.C9, X2.C9, X3.C9, X4.C9, X5.C9, X6.C9, X7.C9, X8.C9
SIG18: X1.A10, X2.A10, X3.A10, X4.A10, X5.A10, X6.A10, X7.A10, X8.A10
SIG19: X1.B10, X2.B10, X3.B10, X4.B10, X5.B10, X6.B10, X7.B10, X8.B10
SIG20: X1.C10, X2.C10, X3.C10, X4.C10, X5.C10, X6.C10, X7.C10, X8.C10
SIG21: X1.A11, X2.A11, X3.A11, X4.A11, X5.A11, X6.A11, X7.A11, X8.A11
SIG22: X1.B11, X2.B11, X3.B11, X4.B11, X5.B11, X6.B11, X7.B11, X8.B11
SIG23: X1.C11, X2.C11, X3.C11, X4.C11, X5.C11, X6.C11, X7.C11, X8.C11
SIG24: X1.A12, X2.A12, X3.A12, X4.A12, X5.A12, X6.A12, X7.A12, X8.A12
SIG25: X1.B12, X2.B12, X3.B12, X4.B12, X5.B12, X6.B12, X7.B12, X8.B12
SIG26: X1.C12, X2.C12, X3.C12, X4.C12, X5.C12, X6.C12, X7.C12, X8.C12
SIG27: X1.A13, X2.A13, X3.A13, X4.A13, X5.A13, X6.A13, X7.A13, X8.A13
SIG28: X1.B13, X2.B13, X3.B13, X4.B13, X5.B13, X6.B13, X7.B13, X8.B13
SIG29: X1.C13, X2.C13, X3.C13, X4.C13, X5.C13, X6.C13, X7.C13, X8.C13
SIG30: X1.A14, X2.A14, X3.A14, X4.A14, X5.A14, X6.A14, X7.A14, X8.A14
SIG31: X1.B14, X2.B14, X3.B14, X4.B14, X5.B14, X6.B14, X7.B14, X8.B14
SIG32: X1.C14, X2.C14, X3.C14, X4.C14, X5.C14, X6.C14, X7.C14, X8.C14
SIG33: X1.A15, X2.A15, X3.A15, X4.A15, X5.A15, X6.A15, X7.A15, X8.A15
SIG34: X1.B15, X2.B15, X3.B15, X4.B15, X5.B15, X6.B15, X7.B15, X8.B15
SIG35: X1.C15, X2.C15, X3.C15, X4.C15, X5.C15, X6.C15, X7.C15, X8.C15
SIG36: X1.A16, X2.A16, X3.A16, X4.A16, X5.A16, X6.A16, X7.A16, X8.A16
SIG37: X1.B16, X2.B16, X3.B16, X4.B16, X5.B16, X6.B16, X7.B16, X8.B16
SIG38: X1.C16, X2.C16, X3.C16, X4.C16, X5.C16, X6.C16, X7.C16, X8.C16
SIG39: X1.A17, X2.A17, X3.A17, X4.A17, X5.A17, X6.A17, X7.A17, X8.A17
SIG40: X1.B17, X2.B17, X3.B17, X4.B17, X5.B17, X6.B17, X7.B17, X8.B17
SIG41: X1.C17, X2.C17, X3.C17, X4.C17, X5.C17, X6.C17, X7.C17, X8.C17
SIG42: X1.A18, X2.A18, X3.A18, X4.A18, X5.A18, X6.A18, X7.A18, X8.A18
SIG43: X1.B18, X2.B18, X3.B18, X4.B18, X5.B18, X6.B18, X7.B18, X8.B18
SIG44: X1.C18, X2.C18, X3.C18, X4.C18, X5.C18, X6.C18, X7.C18, X8.C18
SIG45: X1.A19, X2.A19, X3.A19, X4.A19, X5.A19, X6.A19, X7.A19, X8.A19
SIG46: X1.B19, X2.B19, X3.B19, X4.B19, X5.B19, X6.B19, X7.B19, X8.B19
SIG47: X1.C19, X2.C19, X3.C19, X4.C19, X5.C19, X6.C19, X7.C19, X8.C19
SIG48: X1.A20, X2.A20, X3.A20, X4.A20, X5.A20, X6.A20, X7.A20, X8.A20
SIG49: X1.B20, X2.B20, X3.B20, X4.B20, X5.B20, X6.B20, X7.B20, X8.B20
SIG50: X1.C20, X2.C20, X3.C20, X4.C20, X5.C20, X6.C20, X7.C20, X8.C20
SIG51: X1.A21, X2.A21, X3.A21, X4.A21, X5.A21, X6.A21, X7.A21, X8.A21
SIG52: X1.B21, X2.B21, X3.B21, X4.B21, X5.B21, X6.B21, X7.B21, X8.B21
SIG53: X1.C21, X2.C21, X3.C21, X4.C21, X5.C21, X6.C21, X7.C21, X8.C21
SIG54: X1.A22, X2.A22, X3.A22, X4.A22, X5.A22, X6.A22, X7.A22, X8.A22
SIG55: X1.B22, X2.B22, X3.B22, X4.B22, X5.B22, X6.B22, X7.B22, X8.B22
SIG56: X1.C22, X2.C22, X3.C22, X4.C22, X5.C22, X6.C22, X7.C22, X8.C22
SIG57: X1.A23, X2.A23, X3.A23, X4.A23, X5.A23, X6.A23, X7.A23, X8.A23
SIG58: X1.B23, X2.B23, X3.B23, X4.B23, X5.B23, X6.B23, X7.B23, X8.B23
SIG59: X1.C23, X2.C23, X3.C23, X4.C23, X5.C23, X6.C23, X7.C23, X8.C23
SIG60: X1.A24, X2.A24, X3.A24, X4.A24, X5.A24, X6.A24, X7.A24, X8.A24
SIG61: X1.B24, X2.B24, X3.B24, X4.B24, X5.B24, X6.B24, X7.B24, X8.B24
SIG62: X1.C24, X2.C24, X3.C24, X4.C24, X5.C24, X6.C24, X7.C24, X8.C24
SIG63: X1.A25, X2.A25, X3.A25, X4.A25, X5.A25, X6.A25, X7.A25, X8.A25
SIG64: X1.B25, X2.B25, X3.B25, X4.B25, X5.B25, X6.B25, X7.B25, X8.B25
SIG65: X1.C25, X2.C25, X3.C25, X4.C25, X5.C25, X6.C25, X7.C25, X8.C25
SIG66: X1.A26, X2.A26, X3.A26, X4.A26, X5.A26, X6.A26, X7.A26, X8.A26
SIG67: X1.B26, X2.B26, X3.B26, X4.B26, X5.B26, X6.B26, X7.B26, X8.B26
SIG68: X1.C26, X2.C26, X3.C26, X4.C26, X5.C26, X6.C26, X7.C26, X8.C26
SIG69: X1.A27, X2.A27, X3.A27, X4.A27, X5.A27, X6.A27, X7.A27, X8.A27
SIG70: X1.B27, X2.B27, X3.B27, X4.B27, X5.B27, X6.B27, X7.B27, X8.B27
SIG71: X1.C27, X2.C27, X3.C27, X4.C27, X5.C27, X6.C27, X7.C27, X8.C27
SIG72: X1.A28, X2.A28, X3.A28, X4.A28, X5.A28, X6.A28, X7.A28, X8.A28
SIG73: X1.B28, X2.B28, X3.B28, X4.B28, X5.B28, X6.B28, X7.B28, X8.B28
SIG74: X1.C28, X2.C28, X3.C28, X4.C28, X5.C28, X6.C28, X7.C28, X8.C28
SIG75: X1.A29, X2.A29, X3.A29, X4.A29, X5.A29, X6.A29, X7.A29, X8.A29
SIG76: X1.B29, X2.B29, X3.B29, X4.B29, X5.B29, X6.B29, X7.B29, X8.B29
SIG77: X1.C29, X2.C29, X3.C29, X4.C29, X5.C29, X6.C29, X7.C29, X8.C29
SIG78: X1.A30, X2.A30, X3.A30, X4.A30, X5.A30, X6.A30, X7.A30, X8.A30
SIG79: X1.B30, X2.B30, X3.B30, X4.B30, X5.B30, X6.B30, X7.B30, X8.B30
SIG80: X1.C30, X2.C30, X3.C30, X4.C30, X5.C30, X6.C30, X7.C30, X8.C30
SIG81: X1.A3, X2.A3, X3.A3, X4.A3, X5.A3, X6.A3, X7.A3, X8.A3
SIG82: X1.B3, X2.B3, X3.B3, X4.B3, X5.B3, X6.B3, X7.B3, X8.B3
SIG83: X1.C3, X2.C3, X3.C3, X4.C3, X5.C3, X6.C3, X7.C3, X8.C3

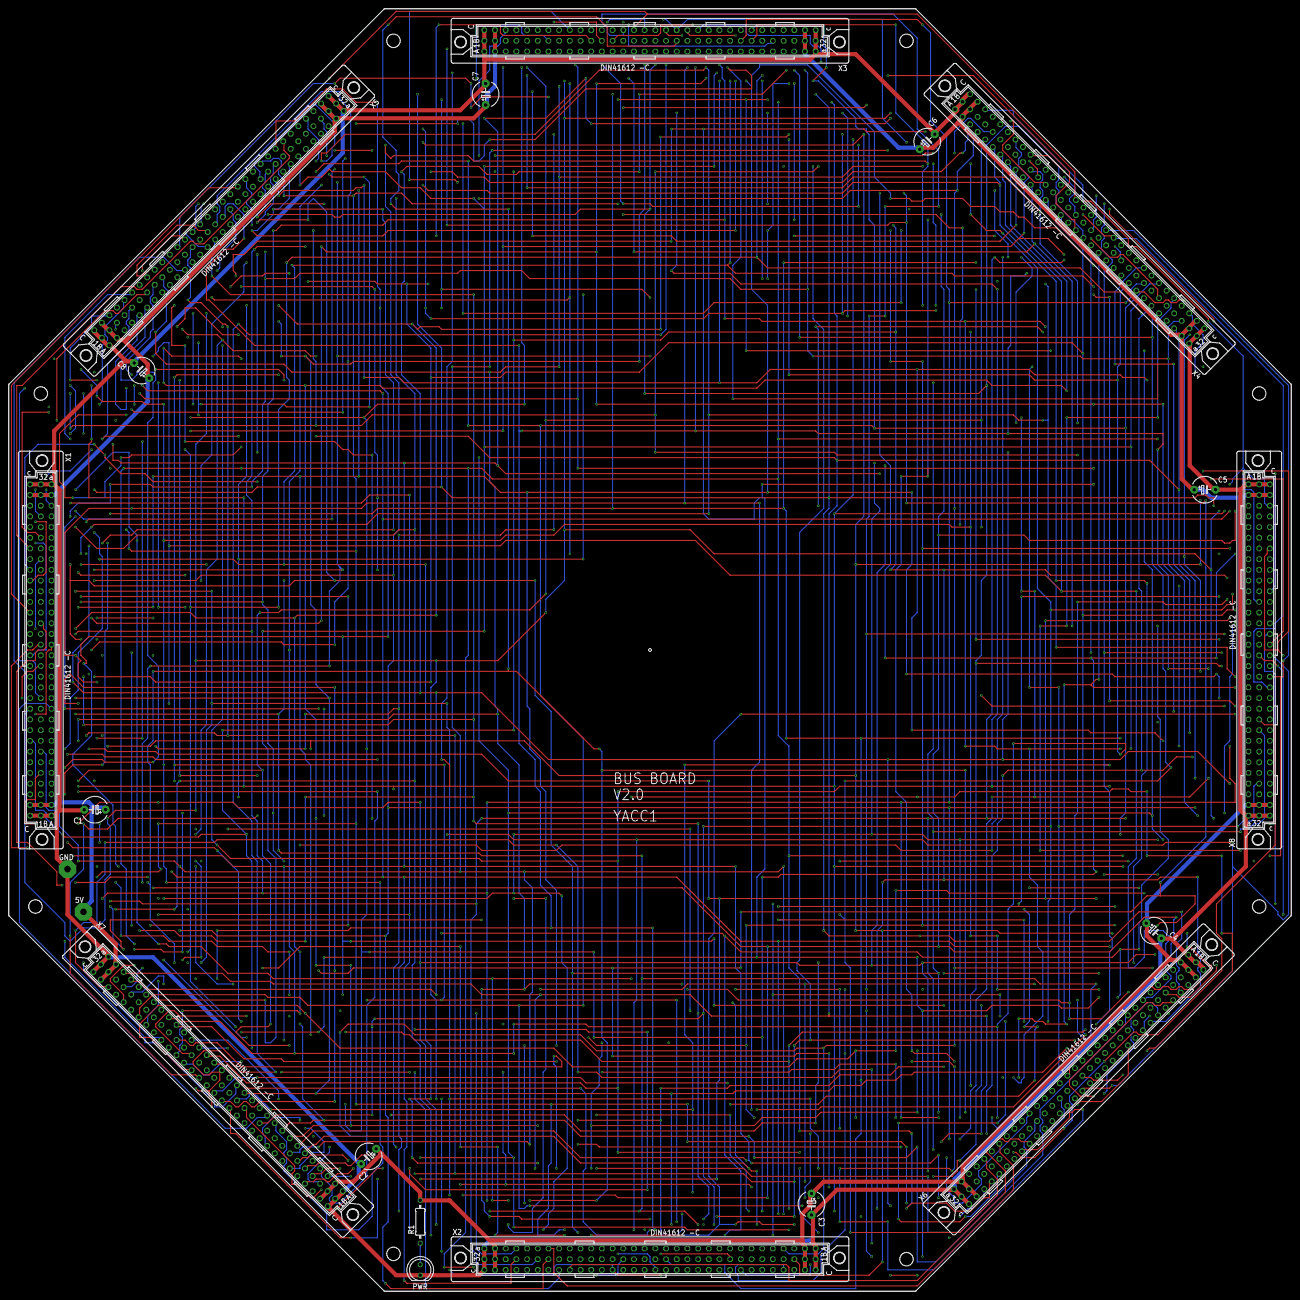
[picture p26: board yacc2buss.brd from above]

Board: 4 copper layers, 304.8 x 304.8 mm, 20 parts (0 on the bottom side), 87 nets.

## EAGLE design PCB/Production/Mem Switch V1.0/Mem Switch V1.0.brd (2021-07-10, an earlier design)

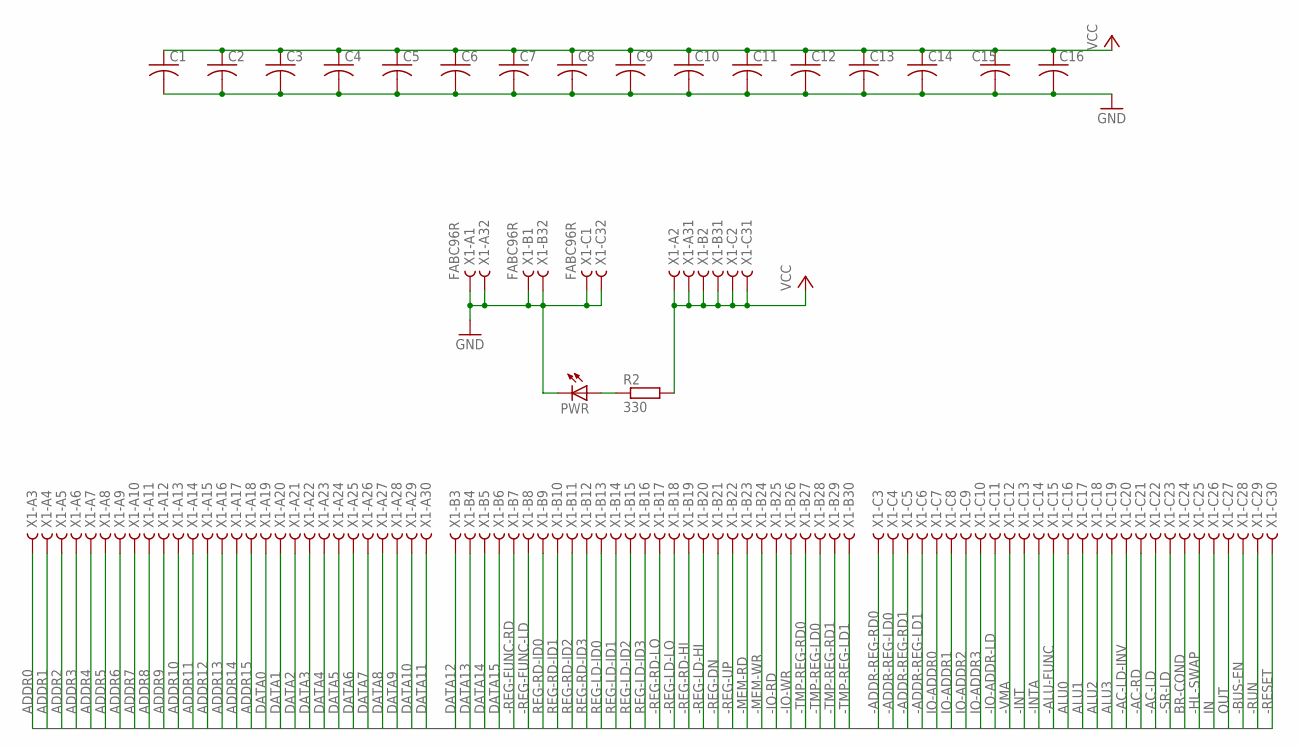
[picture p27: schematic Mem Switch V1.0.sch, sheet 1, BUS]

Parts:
C1, C2, C3, C4, C5, C6, C7, C8, C9, C10, C11, C12, C13, C14, C15, C16: C-US025-025X050; C025-025X050
PWR: LED5MM
R2: 330; 0207/10
X1: FABC96R

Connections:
-AC-LD: X1.C22
-AC-LD-INV: X1.C20
-AC-RD: X1.C21
-ADDR-REG-LD0: X1.C4
-ADDR-REG-LD1: X1.C6
-ADDR-REG-RD0: X1.C3
-ADDR-REG-RD1: X1.C5
-ALU-FUNC: X1.C15
-BUS-EN: X1.C28; also elsewhere on the board
-HL-SWAP: X1.C25
-INT: X1.C13
-INTA: X1.C14
-IO-ADDR-LD: X1.C11
-IO-RD: X1.B25
-IO-WR: X1.B26
-MEM-RD: X1.B23; also elsewhere on the board
-MEM-WR: X1.B24
-REG-DN: X1.B21
-REG-FUNC-LD: X1.B8
-REG-FUNC-RD: X1.B7
-REG-LD-HI: X1.B20
-REG-LD-LO: X1.B18
-REG-RD-HI: X1.B19
-REG-RD-LO: X1.B17
-REG-UP: X1.B22
-RESET: X1.C30
-RUN: X1.C29
-SR-LD: X1.C23
-TMP-REG-LD0: X1.B28
-TMP-REG-LD1: X1.B30
-TMP-REG-RD0: X1.B27
-TMP-REG-RD1: X1.B29
-VMA: X1.C12; also elsewhere on the board
ADDR0: X1.A3; also elsewhere on the board
ADDR1: X1.A4; also elsewhere on the board
ADDR2: X1.A5; also elsewhere on the board
ADDR3: X1.A6; also elsewhere on the board
ADDR4: X1.A7; also elsewhere on the board
ADDR5: X1.A8; also elsewhere on the board
ADDR6: X1.A9
ADDR7: X1.A10
ADDR8: X1.A11; also elsewhere on the board
ADDR9: X1.A12; also elsewhere on the board
ADDR10: X1.A13; also elsewhere on the board
ADDR11: X1.A14; also elsewhere on the board
ADDR12: X1.A15; also elsewhere on the board
ADDR13: X1.A16; also elsewhere on the board
ADDR14: X1.A17; also elsewhere on the board
ADDR15: X1.A18; also elsewhere on the board
ALU0: X1.C16
ALU1: X1.C17
ALU2: X1.C18
ALU3: X1.C19
BR-COND: X1.C24
DATA0: X1.A19; also elsewhere on the board
DATA1: X1.A20; also elsewhere on the board
DATA2: X1.A21; also elsewhere on the board
DATA3: X1.A22; also elsewhere on the board
DATA4: X1.A23; also elsewhere on the board
DATA5: X1.A24; also elsewhere on the board
DATA6: X1.A25; also elsewhere on the board
DATA7: X1.A26; also elsewhere on the board
DATA8: X1.A27
DATA9: X1.A28
DATA10: X1.A29
DATA11: X1.A30
DATA12: X1.B3
DATA13: X1.B4
DATA14: X1.B5
DATA15: X1.B6
GND: C1.2, C2.2, C3.2, C4.2, C5.2, C6.2, C7.2, C8.2, C9.2, C10.2, C11.2, C12.2, C13.2, C14.2, C15.2, C16.2, PWR.K (C), X1.A1, X1.A32, X1.B1, X1.B32, X1.C1, X1.C32; also elsewhere on the board
IN: X1.C26
IO-ADDR0: X1.C7
IO-ADDR1: X1.C8
IO-ADDR2: X1.C9
IO-ADDR3: X1.C10
unnamed: PWR.A, R2.1
OUT: X1.C27
REG-LD-ID0: X1.B13
REG-LD-ID1: X1.B14
REG-LD-ID2: X1.B15
REG-LD-ID3: X1.B16
REG-RD-ID0: X1.B9
REG-RD-ID1: X1.B10
REG-RD-ID2: X1.B11
REG-RD-ID3: X1.B12
VCC: C1.1, C2.1, C3.1, C4.1, C5.1, C6.1, C7.1, C8.1, C9.1, C10.1, C11.1, C12.1, C13.1, C14.1, C15.1, C16.1, R2.2, X1.A2, X1.A31, X1.B2, X1.B31, X1.C2, X1.C31; also elsewhere on the board

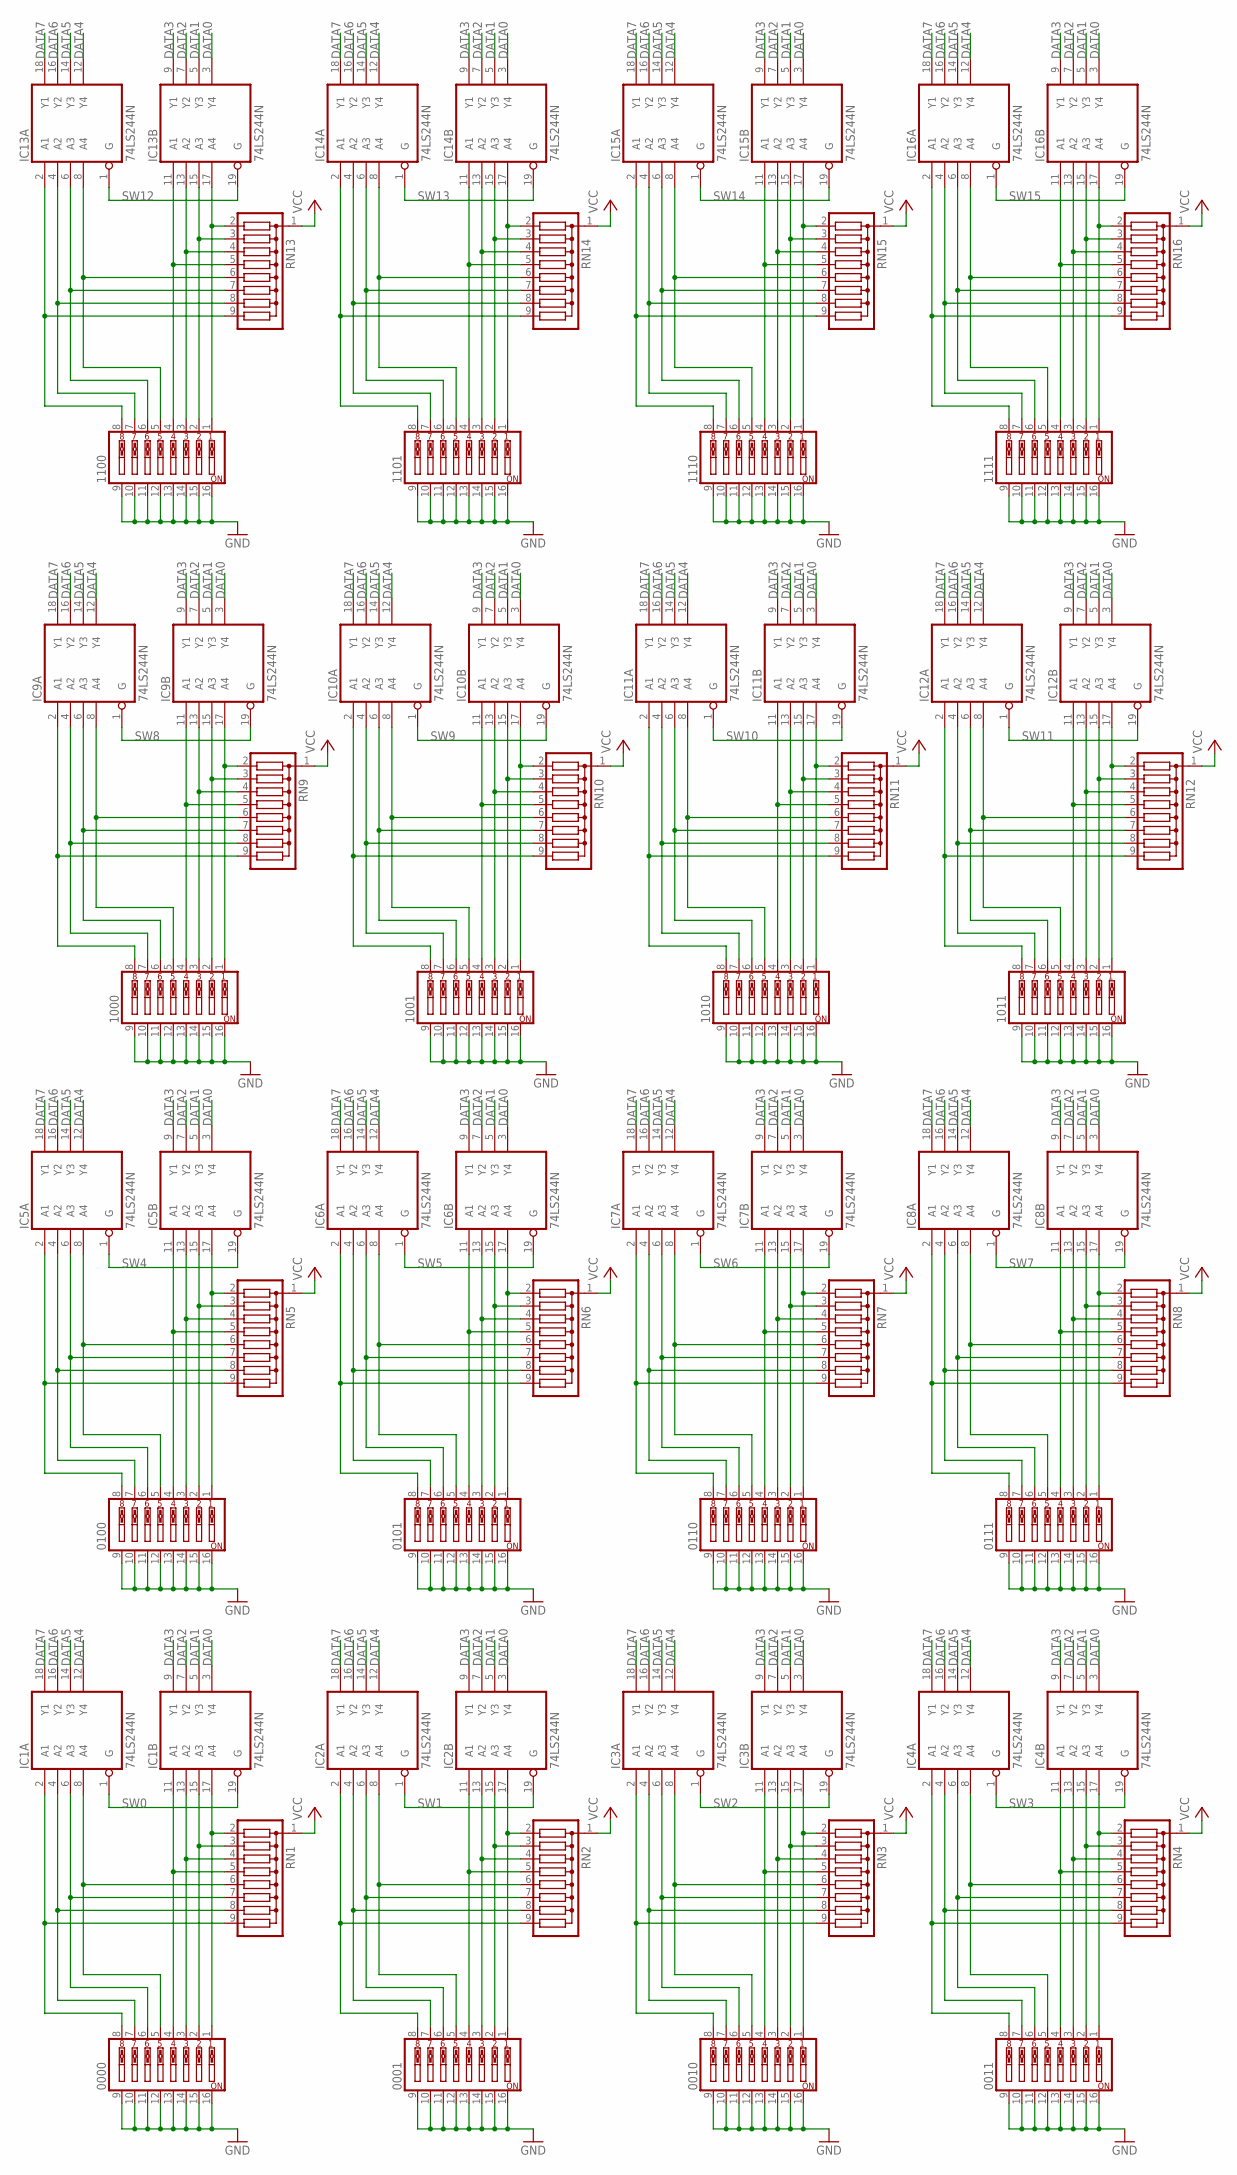
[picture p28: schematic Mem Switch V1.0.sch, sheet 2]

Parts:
0000, 0001, 0010, 0011, 0100, 0101, 0110, 0111, 1000, 1001, 1010, 1011, 1100, 1101, 1110, 1111: SW_DIP-8; EDG-08
IC1, IC2, IC3, IC4, IC5, IC6, IC7, IC8, IC9, IC10, IC11, IC12, IC13, IC14, IC15, IC16: 74LS244N; DIL20
RN1, RN2, RN3, RN4, RN5, RN6, RN7, RN8, RN9, RN10, RN11, RN12, RN13, RN14, RN15, RN16: G08R; SIL9

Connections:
DATA0: IC1.3 (Y4), IC2.3 (Y4), IC3.3 (Y4), IC4.3 (Y4), IC5.3 (Y4), IC6.3 (Y4), IC7.3 (Y4), IC8.3 (Y4), IC9.3 (Y4), IC10.3 (Y4), IC11.3 (Y4), IC12.3 (Y4), IC13.3 (Y4), IC14.3 (Y4), IC15.3 (Y4), IC16.3 (Y4); also elsewhere on the board
DATA1: IC1.5 (Y3), IC2.5 (Y3), IC3.5 (Y3), IC4.5 (Y3), IC5.5 (Y3), IC6.5 (Y3), IC7.5 (Y3), IC8.5 (Y3), IC9.5 (Y3), IC10.5 (Y3), IC11.5 (Y3), IC12.5 (Y3), IC13.5 (Y3), IC14.5 (Y3), IC15.5 (Y3), IC16.5 (Y3); also elsewhere on the board
DATA2: IC1.7 (Y2), IC2.7 (Y2), IC3.7 (Y2), IC4.7 (Y2), IC5.7 (Y2), IC6.7 (Y2), IC7.7 (Y2), IC8.7 (Y2), IC9.7 (Y2), IC10.7 (Y2), IC11.7 (Y2), IC12.7 (Y2), IC13.7 (Y2), IC14.7 (Y2), IC15.7 (Y2), IC16.7 (Y2); also elsewhere on the board
DATA3: IC1.9 (Y1), IC2.9 (Y1), IC3.9 (Y1), IC4.9 (Y1), IC5.9 (Y1), IC6.9 (Y1), IC7.9 (Y1), IC8.9 (Y1), IC9.9 (Y1), IC10.9 (Y1), IC11.9 (Y1), IC12.9 (Y1), IC13.9 (Y1), IC14.9 (Y1), IC15.9 (Y1), IC16.9 (Y1); also elsewhere on the board
DATA4: IC1.12 (Y4), IC2.12 (Y4), IC3.12 (Y4), IC4.12 (Y4), IC5.12 (Y4), IC6.12 (Y4), IC7.12 (Y4), IC8.12 (Y4), IC9.12 (Y4), IC10.12 (Y4), IC11.12 (Y4), IC12.12 (Y4), IC13.12 (Y4), IC14.12 (Y4), IC15.12 (Y4), IC16.12 (Y4); also elsewhere on the board
DATA5: IC1.14 (Y3), IC2.14 (Y3), IC3.14 (Y3), IC4.14 (Y3), IC5.14 (Y3), IC6.14 (Y3), IC7.14 (Y3), IC8.14 (Y3), IC9.14 (Y3), IC10.14 (Y3), IC11.14 (Y3), IC12.14 (Y3), IC13.14 (Y3), IC14.14 (Y3), IC15.14 (Y3), IC16.14 (Y3); also elsewhere on the board
DATA6: IC1.16 (Y2), IC2.16 (Y2), IC3.16 (Y2), IC4.16 (Y2), IC5.16 (Y2), IC6.16 (Y2), IC7.16 (Y2), IC8.16 (Y2), IC9.16 (Y2), IC10.16 (Y2), IC11.16 (Y2), IC12.16 (Y2), IC13.16 (Y2), IC14.16 (Y2), IC15.16 (Y2), IC16.16 (Y2); also elsewhere on the board
DATA7: IC1.18 (Y1), IC2.18 (Y1), IC3.18 (Y1), IC4.18 (Y1), IC5.18 (Y1), IC6.18 (Y1), IC7.18 (Y1), IC8.18 (Y1), IC9.18 (Y1), IC10.18 (Y1), IC11.18 (Y1), IC12.18 (Y1), IC13.18 (Y1), IC14.18 (Y1), IC15.18 (Y1), IC16.18 (Y1); also elsewhere on the board
GND: 0000.9, 0000.10, 0000.11, 0000.12, 0000.13, 0000.14, 0000.15, 0000.16, 0001.9, 0001.10, 0001.11, 0001.12, 0001.13, 0001.14, 0001.15, 0001.16, 0010.9, 0010.10, 0010.11, 0010.12, 0010.13, 0010.14, 0010.15, 0010.16, 0011.9, 0011.10, 0011.11, 0011.12, 0011.13, 0011.14, 0011.15, 0011.16, 0100.9, 0100.10, 0100.11, 0100.12, 0100.13, 0100.14, 0100.15, 0100.16, 0101.9, 0101.10, 0101.11, 0101.12, 0101.13, 0101.14, 0101.15, 0101.16, 0110.9, 0110.10, 0110.11, 0110.12, 0110.13, 0110.14, 0110.15, 0110.16, 0111.9, 0111.10, 0111.11, 0111.12, 0111.13, 0111.14, 0111.15, 0111.16, 1000.9, 1000.10, 1000.11, 1000.12, 1000.13, 1000.14, 1000.15, 1000.16, 1001.9, 1001.10, 1001.11, 1001.12, 1001.13, 1001.14, 1001.15, 1001.16, 1010.9, 1010.10, 1010.11, 1010.12, 1010.13, 1010.14, 1010.15, 1010.16, 1011.9, 1011.10, 1011.11, 1011.12, 1011.13, 1011.14, 1011.15, 1011.16, 1100.9, 1100.10, 1100.11, 1100.12, 1100.13, 1100.14, 1100.15, 1100.16, 1101.9, 1101.10, 1101.11, 1101.12, 1101.13, 1101.14, 1101.15, 1101.16, 1110.9, 1110.10, 1110.11, 1110.12, 1110.13, 1110.14, 1110.15, 1110.16, 1111.9, 1111.10, 1111.11, 1111.12, 1111.13, 1111.14, 1111.15, 1111.16, IC1.10 (GND), IC2.10 (GND), IC3.10 (GND), IC4.10 (GND), IC5.10 (GND), IC6.10 (GND), IC7.10 (GND), IC8.10 (GND), IC9.10 (GND), IC10.10 (GND), IC11.10 (GND), IC12.10 (GND), IC13.10 (GND), IC14.10 (GND), IC15.10 (GND), IC16.10 (GND); also elsewhere on the board
unnamed: 0000.1, IC1.17 (A4), RN1.2
unnamed: 0000.2, IC1.15 (A3), RN1.3
unnamed: 0000.3, IC1.13 (A2), RN1.4
unnamed: 0000.4, IC1.11 (A1), RN1.5
unnamed: 0000.5, IC1.8 (A4), RN1.6
unnamed: 0000.6, IC1.6 (A3), RN1.7
unnamed: 0000.7, IC1.4 (A2), RN1.8
unnamed: 0000.8, IC1.2 (A1), RN1.9
unnamed: 0001.1, IC2.17 (A4), RN2.2
unnamed: 0001.2, IC2.15 (A3), RN2.3
unnamed: 0001.3, IC2.13 (A2), RN2.4
unnamed: 0001.4, IC2.11 (A1), RN2.5
unnamed: 0001.5, IC2.8 (A4), RN2.6
unnamed: 0001.6, IC2.6 (A3), RN2.7
unnamed: 0001.7, IC2.4 (A2), RN2.8
unnamed: 0001.8, IC2.2 (A1), RN2.9
unnamed: 0010.1, IC3.17 (A4), RN3.2
unnamed: 0010.2, IC3.15 (A3), RN3.3
unnamed: 0010.3, IC3.13 (A2), RN3.4
unnamed: 0010.4, IC3.11 (A1), RN3.5
unnamed: 0010.5, IC3.8 (A4), RN3.6
unnamed: 0010.6, IC3.6 (A3), RN3.7
unnamed: 0010.7, IC3.4 (A2), RN3.8
unnamed: 0010.8, IC3.2 (A1), RN3.9
unnamed: 0011.1, IC4.17 (A4), RN4.2
unnamed: 0011.2, IC4.15 (A3), RN4.3
unnamed: 0011.3, IC4.13 (A2), RN4.4
unnamed: 0011.4, IC4.11 (A1), RN4.5
unnamed: 0011.5, IC4.8 (A4), RN4.6
unnamed: 0011.6, IC4.6 (A3), RN4.7
unnamed: 0011.7, IC4.4 (A2), RN4.8
unnamed: 0011.8, IC4.2 (A1), RN4.9
unnamed: 0100.1, IC5.17 (A4), RN5.2
unnamed: 0100.2, IC5.15 (A3), RN5.3
unnamed: 0100.3, IC5.13 (A2), RN5.4
unnamed: 0100.4, IC5.11 (A1), RN5.5
unnamed: 0100.5, IC5.8 (A4), RN5.6
unnamed: 0100.6, IC5.6 (A3), RN5.7
unnamed: 0100.7, IC5.4 (A2), RN5.8
unnamed: 0100.8, IC5.2 (A1), RN5.9
unnamed: 0101.1, IC6.17 (A4), RN6.2
unnamed: 0101.2, IC6.15 (A3), RN6.3
unnamed: 0101.3, IC6.13 (A2), RN6.4
unnamed: 0101.4, IC6.11 (A1), RN6.5
unnamed: 0101.5, IC6.8 (A4), RN6.6
unnamed: 0101.6, IC6.6 (A3), RN6.7
unnamed: 0101.7, IC6.4 (A2), RN6.8
unnamed: 0101.8, IC6.2 (A1), RN6.9
unnamed: 0110.1, IC7.17 (A4), RN7.2
unnamed: 0110.2, IC7.15 (A3), RN7.3
unnamed: 0110.3, IC7.13 (A2), RN7.4
unnamed: 0110.4, IC7.11 (A1), RN7.5
unnamed: 0110.5, IC7.8 (A4), RN7.6
unnamed: 0110.6, IC7.6 (A3), RN7.7
unnamed: 0110.7, IC7.4 (A2), RN7.8
unnamed: 0110.8, IC7.2 (A1), RN7.9
unnamed: 0111.1, IC8.17 (A4), RN8.2
unnamed: 0111.2, IC8.15 (A3), RN8.3
unnamed: 0111.3, IC8.13 (A2), RN8.4
unnamed: 0111.4, IC8.11 (A1), RN8.5
unnamed: 0111.5, IC8.8 (A4), RN8.6
unnamed: 0111.6, IC8.6 (A3), RN8.7
unnamed: 0111.7, IC8.4 (A2), RN8.8
unnamed: 0111.8, IC8.2 (A1), RN8.9
unnamed: 1000.1, IC9.17 (A4), RN9.2
unnamed: 1000.2, IC9.15 (A3), RN9.3
unnamed: 1000.3, IC9.13 (A2), RN9.4
unnamed: 1000.4, IC9.11 (A1), RN9.5
unnamed: 1000.5, IC9.8 (A4), RN9.6
unnamed: 1000.6, IC9.6 (A3), RN9.7
unnamed: 1000.7, IC9.4 (A2), RN9.8
unnamed: 1000.8, IC9.2 (A1), RN9.9
unnamed: 1001.1, IC10.17 (A4), RN10.2
unnamed: 1001.2, IC10.15 (A3), RN10.3
unnamed: 1001.3, IC10.13 (A2), RN10.4
unnamed: 1001.4, IC10.11 (A1), RN10.5
unnamed: 1001.5, IC10.8 (A4), RN10.6
unnamed: 1001.6, IC10.6 (A3), RN10.7
unnamed: 1001.7, IC10.4 (A2), RN10.8
unnamed: 1001.8, IC10.2 (A1), RN10.9
unnamed: 1010.1, IC11.17 (A4), RN11.2
unnamed: 1010.2, IC11.15 (A3), RN11.3
unnamed: 1010.3, IC11.13 (A2), RN11.4
unnamed: 1010.4, IC11.11 (A1), RN11.5
unnamed: 1010.5, IC11.8 (A4), RN11.6
unnamed: 1010.6, IC11.6 (A3), RN11.7
unnamed: 1010.7, IC11.4 (A2), RN11.8
unnamed: 1010.8, IC11.2 (A1), RN11.9
unnamed: 1011.1, IC12.17 (A4), RN12.2
unnamed: 1011.2, IC12.15 (A3), RN12.3
unnamed: 1011.3, IC12.13 (A2), RN12.4
unnamed: 1011.4, IC12.11 (A1), RN12.5
unnamed: 1011.5, IC12.8 (A4), RN12.6
unnamed: 1011.6, IC12.6 (A3), RN12.7
unnamed: 1011.7, IC12.4 (A2), RN12.8
unnamed: 1011.8, IC12.2 (A1), RN12.9
unnamed: 1100.1, IC13.17 (A4), RN13.2
unnamed: 1100.2, IC13.15 (A3), RN13.3
unnamed: 1100.3, IC13.13 (A2), RN13.4
unnamed: 1100.4, IC13.11 (A1), RN13.5
unnamed: 1100.5, IC13.8 (A4), RN13.6
unnamed: 1100.6, IC13.6 (A3), RN13.7
unnamed: 1100.7, IC13.4 (A2), RN13.8
unnamed: 1100.8, IC13.2 (A1), RN13.9
unnamed: 1101.1, IC14.17 (A4), RN14.2
unnamed: 1101.2, IC14.15 (A3), RN14.3
unnamed: 1101.3, IC14.13 (A2), RN14.4
unnamed: 1101.4, IC14.11 (A1), RN14.5
unnamed: 1101.5, IC14.8 (A4), RN14.6
unnamed: 1101.6, IC14.6 (A3), RN14.7
unnamed: 1101.7, IC14.4 (A2), RN14.8
unnamed: 1101.8, IC14.2 (A1), RN14.9
unnamed: 1110.1, IC15.17 (A4), RN15.2
unnamed: 1110.2, IC15.15 (A3), RN15.3
unnamed: 1110.3, IC15.13 (A2), RN15.4
unnamed: 1110.4, IC15.11 (A1), RN15.5
unnamed: 1110.5, IC15.8 (A4), RN15.6
unnamed: 1110.6, IC15.6 (A3), RN15.7
unnamed: 1110.7, IC15.4 (A2), RN15.8
unnamed: 1110.8, IC15.2 (A1), RN15.9
unnamed: 1111.1, IC16.17 (A4), RN16.2
unnamed: 1111.2, IC16.15 (A3), RN16.3
unnamed: 1111.3, IC16.13 (A2), RN16.4
unnamed: 1111.4, IC16.11 (A1), RN16.5
unnamed: 1111.5, IC16.8 (A4), RN16.6
unnamed: 1111.6, IC16.6 (A3), RN16.7
unnamed: 1111.7, IC16.4 (A2), RN16.8
unnamed: 1111.8, IC16.2 (A1), RN16.9
SW0: IC1.1 (G), IC1.19 (G); also elsewhere on the board
SW1: IC2.1 (G), IC2.19 (G); also elsewhere on the board
SW2: IC3.1 (G), IC3.19 (G); also elsewhere on the board
SW3: IC4.1 (G), IC4.19 (G); also elsewhere on the board
SW4: IC5.1 (G), IC5.19 (G); also elsewhere on the board
SW5: IC6.1 (G), IC6.19 (G); also elsewhere on the board
SW6: IC7.1 (G), IC7.19 (G); also elsewhere on the board
SW7: IC8.1 (G), IC8.19 (G); also elsewhere on the board
SW8: IC9.1 (G), IC9.19 (G); also elsewhere on the board
SW9: IC10.1 (G), IC10.19 (G); also elsewhere on the board
SW10: IC11.1 (G), IC11.19 (G); also elsewhere on the board
SW11: IC12.1 (G), IC12.19 (G); also elsewhere on the board
SW12: IC13.1 (G), IC13.19 (G); also elsewhere on the board
SW13: IC14.1 (G), IC14.19 (G); also elsewhere on the board
SW14: IC15.1 (G), IC15.19 (G); also elsewhere on the board
SW15: IC16.1 (G), IC16.19 (G); also elsewhere on the board
VCC: IC1.20 (VCC), IC2.20 (VCC), IC3.20 (VCC), IC4.20 (VCC), IC5.20 (VCC), IC6.20 (VCC), IC7.20 (VCC), IC8.20 (VCC), IC9.20 (VCC), IC10.20 (VCC), IC11.20 (VCC), IC12.20 (VCC), IC13.20 (VCC), IC14.20 (VCC), IC15.20 (VCC), IC16.20 (VCC), RN1.1, RN2.1, RN3.1, RN4.1, RN5.1, RN6.1, RN7.1, RN8.1, RN9.1, RN10.1, RN11.1, RN12.1, RN13.1, RN14.1, RN15.1, RN16.1; also elsewhere on the board


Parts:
IC17, IC18, IC21: 74LS138N; DIL16
V1: 744078N; DIL14

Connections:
-BUS-EN: IC21.5 (G2B); also elsewhere on the board
-MEM-RD: IC17.4 (G2A), IC18.4 (G2A); also elsewhere on the board
-VMA: IC21.4 (G2A); also elsewhere on the board
ADDR0: IC17.1 (A), IC18.1 (A); also elsewhere on the board
ADDR1: IC17.2 (B), IC18.2 (B); also elsewhere on the board
ADDR2: IC17.3 (C), IC18.3 (C); also elsewhere on the board
ADDR3: IC21.1 (A); also elsewhere on the board
ADDR4: IC21.2 (B); also elsewhere on the board
ADDR5: IC21.3 (C); also elsewhere on the board
ADDR8: V1.2 (A); also elsewhere on the board
ADDR9: V1.3 (B); also elsewhere on the board
ADDR10: V1.4 (C); also elsewhere on the board
ADDR11: V1.5 (D); also elsewhere on the board
ADDR12: V1.9 (E); also elsewhere on the board
ADDR13: V1.10 (F); also elsewhere on the board
ADDR14: V1.11 (G); also elsewhere on the board
ADDR15: V1.12 (H); also elsewhere on the board
GND: IC17.8 (GND), IC18.8 (GND), IC21.8 (GND), V1.7 (-UB); also elsewhere on the board
unnamed: IC17.5 (G2B), IC21.15 (Y0)
unnamed: IC18.5 (G2B), IC21.14 (Y1)
unnamed: IC17.6 (G1), IC18.6 (G1), IC21.6 (G1), V1.13 (W)
SW0: IC17.15 (Y0); also elsewhere on the board
SW1: IC17.14 (Y1); also elsewhere on the board
SW2: IC17.13 (Y2); also elsewhere on the board
SW3: IC17.12 (Y3); also elsewhere on the board
SW4: IC17.11 (Y4); also elsewhere on the board
SW5: IC17.10 (Y5); also elsewhere on the board
SW6: IC17.9 (Y6); also elsewhere on the board
SW7: IC17.7 (Y7); also elsewhere on the board
SW8: IC18.15 (Y0); also elsewhere on the board
SW9: IC18.14 (Y1); also elsewhere on the board
SW10: IC18.13 (Y2); also elsewhere on the board
SW11: IC18.12 (Y3); also elsewhere on the board
SW12: IC18.11 (Y4); also elsewhere on the board
SW13: IC18.10 (Y5); also elsewhere on the board
SW14: IC18.9 (Y6); also elsewhere on the board
SW15: IC18.7 (Y7); also elsewhere on the board
VCC: IC17.16 (VCC), IC18.16 (VCC), IC21.16 (VCC), V1.14 (+UB); also elsewhere on the board


Board: 2 copper layers, 177.8 x 114.0 mm, 71 parts (0 on the bottom side), 175 nets.

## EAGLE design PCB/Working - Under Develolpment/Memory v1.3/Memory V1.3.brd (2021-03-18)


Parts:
C1, C2, C3, C4, C5, C6, C7, C8, C9, C10, C11, C12, C13, C14, C15, C16, C17, C18, C19, C20, C21, C22, C23, C24: C-US025-025X050; C025-025X050
IC3: 74LS32N; DIL14
IC12: 74LS74N; DIL14
PWR: LED5MM
R2: 330; 0207/10
X1: FABC96R

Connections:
-AC-LD: X1.C22
-AC-LD-INV: X1.C20
-AC-RD: X1.C21
-ADDR-REG-ID0: X1.C3
-ADDR-REG-ID1: X1.C4
-ADDR-REG-ID2: X1.C5
-ADDR-REG-ID3: X1.C6
-ALU-FUNC: X1.C15
-BUS-EN: X1.C28; also elsewhere on the board
-HL-SWAP: X1.C25
-IN: X1.C26
-INT: X1.C13
-INTA: X1.C14
-IO-ADDR-LD: X1.C11
-IO-RD: X1.B25
-IO-WR: X1.B26
-MEM-RD: X1.B23; also elsewhere on the board
-MEM-WR: X1.B24; also elsewhere on the board
-OUT: X1.C27
-REG-DN: X1.B21
-REG-FUNC-LD: X1.B8
-REG-FUNC-RD: X1.B7
-REG-LD-HI: X1.B20
-REG-LD-LO: X1.B18
-REG-RD-HI: X1.B19
-REG-RD-LO: X1.B17
-REG-UP: X1.B22
-RESET: X1.C30; also elsewhere on the board
-RUN: X1.C29
-SR-LD: X1.C23
-TMP-REG-LD0: X1.B28; also elsewhere on the board
-TMP-REG-LD1: X1.B30; also elsewhere on the board
-TMP-REG-RD0: X1.B27; also elsewhere on the board
-TMP-REG-RD1: X1.B29; also elsewhere on the board
-VMA: X1.C12; also elsewhere on the board
ADDR0: X1.A3; also elsewhere on the board
ADDR1: X1.A4; also elsewhere on the board
ADDR2: X1.A5; also elsewhere on the board
ADDR3: X1.A6; also elsewhere on the board
ADDR4: X1.A7; also elsewhere on the board
ADDR5: X1.A8; also elsewhere on the board
ADDR6: X1.A9; also elsewhere on the board
ADDR7: X1.A10; also elsewhere on the board
ADDR8: X1.A11; also elsewhere on the board
ADDR9: X1.A12; also elsewhere on the board
ADDR10: X1.A13; also elsewhere on the board
ADDR11: X1.A14; also elsewhere on the board
ADDR12: X1.A15; also elsewhere on the board
ADDR13: X1.A16; also elsewhere on the board
ADDR14: X1.A17; also elsewhere on the board
ADDR15: X1.A18; also elsewhere on the board
ALU0: X1.C16
ALU1: X1.C17
ALU2: X1.C18
ALU3: X1.C19
BR-COND: X1.C24
DATA0: X1.A19; also elsewhere on the board
DATA1: X1.A20; also elsewhere on the board
DATA2: X1.A21; also elsewhere on the board
DATA3: X1.A22; also elsewhere on the board
DATA4: X1.A23; also elsewhere on the board
DATA5: X1.A24; also elsewhere on the board
DATA6: X1.A25; also elsewhere on the board
DATA7: X1.A26; also elsewhere on the board
DATA8: X1.A27; also elsewhere on the board
DATA9: X1.A28; also elsewhere on the board
DATA10: X1.A29; also elsewhere on the board
DATA11: X1.A30; also elsewhere on the board
DATA12: X1.B3; also elsewhere on the board
DATA13: X1.B4; also elsewhere on the board
DATA14: X1.B5; also elsewhere on the board
DATA15: X1.B6; also elsewhere on the board
GND: C1.2, C2.2, C3.2, C4.2, C5.2, C6.2, C7.2, C8.2, C9.2, C10.2, C11.2, C12.2, C13.2, C14.2, C15.2, C16.2, C17.2, C18.2, C19.1, C20.1, C21.1, C22.1, C23.1, C24.1, IC3.4 (I0), IC3.5 (I1), IC3.7 (GND), IC3.9 (I0), IC3.10 (I1), IC3.12 (I0), IC3.13 (I1), IC12.7 (GND), IC12.10 (PRE), IC12.11 (CLK), IC12.12 (D), IC12.13 (CLR), PWR.K (C), X1.A1, X1.A32, X1.B1, X1.B32, X1.C1, X1.C32; also elsewhere on the board
IO-ADDR0: X1.C7
IO-ADDR1: X1.C8
IO-ADDR2: X1.C9
IO-ADDR3: X1.C10
unnamed: PWR.A, R2.1
REG-LD-ID0: X1.B13
REG-LD-ID1: X1.B14
REG-LD-ID2: X1.B15
REG-LD-ID3: X1.B16
REG-RD-ID0: X1.B9
REG-RD-ID1: X1.B10
REG-RD-ID2: X1.B11
REG-RD-ID3: X1.B12
VCC: C1.1, C2.1, C3.1, C4.1, C5.1, C6.1, C7.1, C8.1, C9.1, C10.1, C11.1, C12.1, C13.1, C14.1, C15.1, C16.1, C17.1, C18.1, C19.2, C20.2, C21.2, C22.2, C23.2, C24.2, IC3.14 (VCC), IC12.14 (VCC), R2.2, X1.A2, X1.A31, X1.B2, X1.B31, X1.C2, X1.C31; also elsewhere on the board


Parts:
IC3: 74LS32N; DIL14
IC4, IC18: 74ALS30N; DIL14
IC6: 74LS04N; DIL14
IC7: 74LS138N; DIL16
IC10: 74ALS00N; DIL14
IC12: 74LS74N; DIL14
JP1: PINHD-1X3; 1X03
RN7, RN8: G08R; SIL9
U$1: PIN_3X8

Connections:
-BUS-EN: IC3.2 (I1), JP1.1; also elsewhere on the board
-HI-RAM: IC6.10 (O); also elsewhere on the board
-RESET: IC12.4 (PRE); also elsewhere on the board
-ROM-CS: IC6.12 (O); also elsewhere on the board
-VMA: IC3.1 (I0), IC7.4 (G2A); also elsewhere on the board
ADDR15: IC10.4 (I0); also elsewhere on the board
BADDR12: IC7.1 (A); also elsewhere on the board
BADDR13: IC7.2 (B); also elsewhere on the board
BADDR14: IC7.3 (C); also elsewhere on the board
BADDR15: IC7.6 (G1); also elsewhere on the board
FORCE-ROM: IC12.5 (Q); also elsewhere on the board
GND: IC3.7 (GND), IC4.7 (GND), IC6.7 (GND), IC7.8 (GND), IC10.7 (GND), IC12.2 (D), IC12.7 (GND), IC18.7 (GND), JP1.3; also elsewhere on the board
unnamed: IC6.13 (I), IC18.8 (O)
unnamed: IC4.1 (I0), RN8.2, U$1.17
unnamed: IC4.2 (I1), RN8.3, U$1.18
unnamed: IC4.3 (I2), RN8.4, U$1.19
unnamed: IC4.4 (I3), RN8.5, U$1.20
unnamed: IC4.5 (I4), RN8.6, U$1.21
unnamed: IC4.6 (I5), RN8.7, U$1.22
unnamed: IC4.8 (O), IC6.11 (I)
unnamed: IC10.8 (O), IC12.3 (CLK)
unnamed: IC10.6 (O), IC10.9 (I0), IC10.10 (I1)
unnamed: IC10.5 (I1), IC10.11 (O)
unnamed: IC7.5 (G2B), JP1.2
unnamed: IC3.3 (O), IC10.12 (I0), IC10.13 (I1)
unnamed: IC4.11 (I6), RN8.8, U$1.23
unnamed: IC4.12 (I7), RN8.9, U$1.24
unnamed: IC18.12 (I7), RN7.9, U$1.1
unnamed: IC18.11 (I6), RN7.8, U$1.2
unnamed: IC18.6 (I5), RN7.7, U$1.3
unnamed: IC18.5 (I4), RN7.6, U$1.4
unnamed: IC18.1 (I0), RN7.2, U$1.8
unnamed: IC18.2 (I1), RN7.3, U$1.7
unnamed: IC18.3 (I2), RN7.4, U$1.6
unnamed: IC7.7 (Y7), U$1.16
unnamed: IC7.9 (Y6), U$1.15
unnamed: IC7.10 (Y5), U$1.14
unnamed: IC7.11 (Y4), U$1.13
unnamed: IC7.12 (Y3), U$1.12
unnamed: IC7.13 (Y2), U$1.11
unnamed: IC7.14 (Y1), U$1.10
unnamed: IC7.15 (Y0), U$1.9
unnamed: IC18.4 (I3), RN7.5, U$1.5
VCC: IC3.14 (VCC), IC4.14 (VCC), IC6.14 (VCC), IC7.16 (VCC), IC10.14 (VCC), IC12.1 (CLR), IC12.14 (VCC), IC18.14 (VCC), RN7.1, RN8.1; also elsewhere on the board

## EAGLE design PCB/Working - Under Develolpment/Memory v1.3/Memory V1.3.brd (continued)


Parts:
IC1, IC2: 62256P; DIL28-6
IC6, IC14: 74LS04N; DIL14
IC10: 74ALS00N; DIL14
IC13: 28C64C; DIL28-6

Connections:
-HI-RAM: IC2.20 (!CS); also elsewhere on the board
-LO-RAM: IC1.20 (!CS), IC10.3 (O)
-MEM-RD: IC6.5 (I); also elsewhere on the board
-MEM-WR: IC6.9 (I); also elsewhere on the board
-ROM-CS: IC13.20 (!CE); also elsewhere on the board
-VMA: IC14.11 (I); also elsewhere on the board
BADDR0: IC1.10 (A0), IC2.10 (A0), IC13.10 (A0); also elsewhere on the board
BADDR1: IC1.9 (A1), IC2.9 (A1), IC13.9 (A1); also elsewhere on the board
BADDR2: IC1.8 (A2), IC2.8 (A2), IC13.8 (A2); also elsewhere on the board
BADDR3: IC1.7 (A3), IC2.7 (A3), IC13.7 (A3); also elsewhere on the board
BADDR4: IC1.6 (A4), IC2.6 (A4), IC13.6 (A4); also elsewhere on the board
BADDR5: IC1.5 (A5), IC2.5 (A5), IC13.5 (A5); also elsewhere on the board
BADDR6: IC1.4 (A6), IC2.4 (A6), IC13.4 (A6); also elsewhere on the board
BADDR7: IC1.3 (A7), IC2.3 (A7), IC13.3 (A7); also elsewhere on the board
BADDR8: IC1.25 (A8), IC2.25 (A8), IC13.25 (A8); also elsewhere on the board
BADDR9: IC1.24 (A9), IC2.24 (A9), IC13.24 (A9); also elsewhere on the board
BADDR10: IC1.21 (A10), IC2.21 (A10), IC13.21 (A10); also elsewhere on the board
BADDR11: IC1.23 (A11), IC2.23 (A11), IC13.23 (A11); also elsewhere on the board
BADDR12: IC1.2 (A12), IC2.2 (A12), IC13.2 (A12); also elsewhere on the board
BADDR13: IC1.26 (A13), IC2.26 (A13); also elsewhere on the board
BADDR14: IC1.1 (A14), IC2.1 (A14); also elsewhere on the board
BADDR15: IC14.3 (I); also elsewhere on the board
BDATA0: IC1.11 (I/O0), IC2.11 (I/O0), IC13.11 (I/O0); also elsewhere on the board
BDATA1: IC1.12 (I/O1), IC2.12 (I/O1), IC13.12 (I/O1); also elsewhere on the board
BDATA2: IC1.13 (I/O2), IC2.13 (I/O2), IC13.13 (I/O2); also elsewhere on the board
BDATA3: IC1.15 (I/O3), IC2.15 (I/O3), IC13.15 (I/O3); also elsewhere on the board
BDATA4: IC1.16 (I/O4), IC2.16 (I/O4), IC13.16 (I/O4); also elsewhere on the board
BDATA5: IC1.17 (I/O5), IC2.17 (I/O5), IC13.17 (I/O5); also elsewhere on the board
BDATA6: IC1.18 (I/O6), IC2.18 (I/O6), IC13.18 (I/O6); also elsewhere on the board
BDATA7: IC1.19 (I/O7), IC2.19 (I/O7), IC13.19 (I/O7); also elsewhere on the board
GND: IC1.14 (VSS), IC2.14 (VSS), IC6.7 (GND), IC10.7 (GND), IC13.14 (GND), IC14.7 (GND); also elsewhere on the board
MEM-RD: IC6.1 (I), IC6.6 (O)
unnamed: IC6.3 (I), IC6.8 (O)
unnamed: IC1.22 (!OE), IC2.22 (!OE), IC6.2 (O), IC13.22 (!OE)
unnamed: IC1.27 (!WE), IC2.27 (!WE), IC6.4 (O), IC13.27 (!WE)
unnamed: IC10.2 (I1), IC14.10 (O)
unnamed: IC10.1 (I0), IC14.4 (O)
VCC: IC1.28 (VCC), IC2.28 (VCC), IC6.14 (VCC), IC10.14 (VCC), IC13.28 (VCC), IC14.14 (VCC); also elsewhere on the board


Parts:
IC8, IC9: 74LS244N; DIL20
IC11: 74LS157N; DIL16
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

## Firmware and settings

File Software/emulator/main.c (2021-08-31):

/*
 * To change this license header, choose License Headers in Project Properties.
 * To change this template file, choose Tools | Templates
 * and open the template in the editor.
 */

/* 
 * File:   main.c
 * Author: kennethrother
 *
 * Created on October 23, 2020, 1:04 PM
 */

#include <stdio.h>
#include <stdlib.h>
#include <stdbool.h>
#include <string.h>
#include <termios.h>
#include <unistd.h>
#include "../opcodes.h"

#define DEBUG 0

#if DEBUG
#define DEBUG_PRINTF(...)  printf(__VA_ARGS__)
#else
#define DEBUG_PRINTF(...)
#endif

#define MEMORY_SIZE 0x10000
#define REGISTERS 9
#define PC 0
#define SP 1
#define PORTS 16

#define IR 8 //HACK

#define REG0 0
#define REG1 1
#define REG2 2
#define REG3 3
#define REG4 4
#define REG5 5
#define REG6 6
#define REG7 7

#define PORT0 0
#define PORT1 1
#define PORT2 2
#define PORT3 3
#define PORT4 4
#define PORT5 5
#define PORT6 6
#define PORT7 7
#define PORT8 8
#define PORT9 9
#define PORT10 10
#define PORT11 11
#define PORT12 12
#define PORT13 13
#define PORT14 14
#define PORT15 15

union Register {
    unsigned char byte[2];
    unsigned short word;
} registers[REGISTERS];

unsigned char port[PORTS];

unsigned char memory[MEMORY_SIZE];

unsigned char acc;
unsigned char treg;
int out;
int in;
int jsrdepth;
int pushpopdepth;
int pushpoprdepth;
bool carry;
int firstSwitchRead = 1; // What is this


/* Intel HEX read/write functions, Paul Stoffregen, paul@ece.orst.edu */
/* This code is in the public domain.  Please retain my name and */
/* email address in distributed copies, and let me know about any bugs */

/* I, Paul Stoffregen, give no warranty, expressed or implied for */
/* this software and/or documentation provided, including, without */
/* limitation, warranty of merchantability and fitness for a */
/* particular purpose. */

/* some ansi prototypes.. maybe ought to make a .h file */

/* this loads an intel hex file into the memory[] array */
void load_file(char *filename);

/* this is used by load_file to get each line of intex hex */
int parse_hex_line(char *theline, int bytes[], int *addr, int *num, int *code);

/* parses a line of intel hex code, stores the data in bytes[] */
/* and the beginning address in addr, and returns a 1 if the */
/* line was valid, or a 0 if an error occured.  The variable */

/* num gets the number of bytes that were stored into bytes[] */

int parse_hex_line(theline, bytes, addr, num, code)
char *theline;
int *addr, *num, *code, bytes[];
{
    int sum, len, cksum;
    char *ptr;

    *num = 0;
    if (theline[0] != ':') return 0;
    if (strlen(theline) < 11) return 0;
    ptr = theline + 1;
    if (!sscanf(ptr, "%02x", &len)) return 0;
    ptr += 2;
    if (strlen(theline) < (11 + (len * 2))) return 0;
    if (!sscanf(ptr, "%04x", addr)) return 0;
    ptr += 4;
    /* printf("Line: length=%d Addr=%d\n", len, *addr); */
    if (!sscanf(ptr, "%02x", code)) return 0;
    ptr += 2;
    sum = (len & 255) + ((*addr >> 8) & 255) + (*addr & 255) + (*code & 255);
    while (*num != len) {
        if (!sscanf(ptr, "%02x", &bytes[*num])) return 0;
        ptr += 2;
        sum += bytes[*num] & 255;
        (*num)++;
        if (*num >= 256) return 0;
    }
    if (!sscanf(ptr, "%02x", &cksum)) return 0;
    if (((sum & 255) + (cksum & 255)) & 255) return 0; /* checksum error */
    return 1;
}

/* loads an intel hex file into the global memory[] array */

/* filename is a string of the file to be opened */

void load_file(filename)
char *filename;
{
    unsigned char line[1000];
    FILE *fin;
    int addr, n, status, bytes[256];
    int i, total = 0, lineno = 1;
    int minaddr = 65536, maxaddr = 0;

    if (strlen(filename) == 0) {
        printf("   Can't load a file without the filename.");
        printf("  '?' for help\n");
        return;
    }
    fin = fopen(filename, "r");
    if (fin == NULL) {
        printf("   Can't open file '%s' for reading.\n", filename);
        return;
    }
    while (!feof(fin) && !ferror(fin)) {
        line[0] = '\0';
        fgets(line, 1000, fin);
        if (line[strlen(line) - 1] == '\n') line[strlen(line) - 1] = '\0';
        if (line[strlen(line) - 1] == '\r') line[strlen(line) - 1] = '\0';
        if (parse_hex_line(line, bytes, &addr, &n, &status)) {
            if (status == 0) { /* data */
                for (i = 0; i <= (n - 1); i++) {
                    memory[addr] = bytes[i] & 255;
                    total++;
                    if (addr < minaddr) minaddr = addr;
                    if (addr > maxaddr) maxaddr = addr;
                    addr++;
                }
            }
            if (status == 1) { /* end of file */
                fclose(fin);
                printf("   Loaded %d bytes between:", total);
                printf(" %04X to %04X\n", minaddr, maxaddr);
                return;
            }
            if (status == 2)
                ; /* begin of file */
        } else {
            printf("   Error: '%s', line: %d\n", filename, lineno);
        }
        lineno++;
    }
}

void regdump() {
    int i;

    printf("reg dump - ");
    for (i = 0; i < REGISTERS; i++)
        printf("%d=[%04x]", i, registers[i]);
    printf("\n");
}

void dump(int start, int end) {
    int i;

    printf("dump %04x %04x\n", start, end);
    for (i = start; i < end; i++) {
        if ((i & 0x0f) == 0)
            printf("\n %04x ", i);
        printf("%02x ", memory[i]);
    }
    printf("\n");
}

unsigned char memory_read(int address) {
    return (memory[address]);
}

void memory_write(int address, unsigned char value) {
    if (address > 0xdfff) {
        printf("Rom Write\n");
        regdump();
        exit(0);
    }
    /*   if ((address == 0x0204) && (value == 0)) {
           printf("argh\n");
           regdump();
       }
     */
    memory[address] = value;
}

unsigned char register_read_lo(int registernum) {
    if (registernum > REGISTERS) { //HACK FIX HARD CODE 8
        printf("reg error\n");
        exit(0);
    }
    return (registers[registernum].byte[0]);
}

unsigned char register_read_hi(int registernum) {
    if (registernum > REGISTERS) {
        printf("reg error\n");
        exit(0);
    }
    return (registers[registernum].byte[1]);
}

unsigned short register_read_word(int registernum) {
    if (registernum > REGISTERS) {
        printf("reg error\n");
        exit(0);
    }
    return (registers[registernum].word);
}

void register_write_lo(int registernum, unsigned char val) {
    if (registernum > REGISTERS) {
        printf("reg error\n");
        exit(0);
    }
    registers[registernum].byte[0] = val;
}

void register_write_hi(int registernum, unsigned char val) {
    if (registernum > REGISTERS) {
        printf("reg error\n");
        exit(0);
    }
    registers[registernum].byte[1] = val;
}

void register_write_word(int registernum, unsigned short val) {
    if (registernum > REGISTERS) {
        printf("reg error\n");
        exit(0);
    }
    registers[registernum].word = val;
}

void register_inc(int registernum) {
    registers[registernum].word++;
}

void register_dec(int registernum) {
    registers[registernum].word--;
}

unsigned char acc_read() {
    return acc;
}

void acc_write(unsigned char val) {
    acc = val;
}

unsigned char tmp_read() {
    return treg;
}

void tmp_write(unsigned char val) {
    treg = val;
}

void out_on() {
    out = 1;
    //printf("out on\n");
}

void out_off() {
    out = 0;
    //printf("out off\n");
}

void badOpcode(int ins) {
    printf("bad opcode [%02x] pc[%04x]\n", ins, register_read_word(PC));
    exit(0);
}
#define RUN 0
#define HALT 1
#define SINGLESTEP 2
#define JUMPOVER 3
int stepmode = 0;
int jsrdepth = 0;
int jsrover = 0;

char mygetchar();

void debug_mode(int mode) {
    char c;
    while (1) {
        c = toupper(mygetchar());
        if (c == 'C') {
            return;
        } else if (c == 'S') {
            stepmode = SINGLESTEP;
            jsrover = 0;
            return;
        } else if (c == 'R') {
            stepmode = RUN;
            return;
        } else if (c == 'J') {
            stepmode = JUMPOVER;
            jsrover = jsrdepth;
            return;
        } else if (c == 'D') {
            dump(0x0200, 0x021f);
            dump(0x0f80, 0x0f8f);
            dump(0x0400, 0x040F);
            dump(0x1000, 0x10FF);
            regdump();
        } else {
            return;
        }
    }
}


struct termios orig_termios;

void enableRawMode() {
    tcgetattr(STDIN_FILENO, &orig_termios);
    //atexit(disableRawMode);
    struct termios raw = orig_termios;
    raw.c_iflag &= ~(ICRNL | IXON);
    //raw.c_oflag &= ~(OPOST);
    //raw.c_lflag &= ~(ECHO | ICANON | IEXTEN | ISIG);
    raw.c_lflag &= ~(ICANON | IEXTEN | ISIG);
    tcsetattr(STDIN_FILENO, TCSAFLUSH, &raw);
}

char mygetchar() {
    enableRawMode();
    char c;

    while (read(STDIN_FILENO, &c, 1) == 1 && c != 'q') {
        /*    if (iscntrl(c)) {
              printf("%d\n", c);
            } else {
              printf("%d ('%c')\n", c, c);
            }
         * */
        //printf("%02x\n",c);
        if (c == 0x0d) {
            //printf("conv %02x\n", c);
            c = 0x0a;
            //printf("conv %02x\n", c);
        }
        return (c);
    }
    //return (0); //ksr hack
}

void myputchar(char c) {
    write(STDOUT_FILENO, &c, 1);
    //printf("me\n");
}

int main(int argc, char** argv) {
    int i, ins;
    int reg;
    int portaddr;
    unsigned char hi, lo;
    int src, dest;
    bool tmpCarry;
    char c;

    enableRawMode();
    int cc;

    /* ech testwhile (1) {
        myputchar(mygetchar());
        printf(" cc=%d",cc++);
     }
     */

    in = 0;
    registers[PC].word = 0xf000;
    int singleStep = 0;
    int breakAddress = 0;
    pushpopdepth = 0;
    pushpoprdepth = 0;
    int regtrigger = 0;

    load_file("../Assembler/basic.img");
    load_file("../Assembler/monitor.img");
    dump(0xf700, 0xf7ff);

    while (1) {

        ins = memory_read(register_read_word(PC));

        // trigger condition, for instance test PC value or a reg value
        if (registers[PC].word == 0x0000) {
            debug_mode(SINGLESTEP);
        }


        if (stepmode != 0) {
            if (stepmode == SINGLESTEP) {
                for (int t = 3; t < jsrdepth; t++)
                    printf("->");
                printf("singlestep [%02x] at [%04x] acc=[%02x] tmp=[%02x] R3=[%04x] R7=[%04x]\n", ins, registers[PC].word, acc, treg, register_read_word(3), register_read_word(7));
                debug_mode(SINGLESTEP);
            }

            if ((stepmode == JUMPOVER) && (jsrover <= jsrdepth)) {
                for (int t = 3; t < jsrdepth; t++)
                    printf("->");
                printf("singlestep [%02x] at [%04x] acc=[%02x] R3=[%04x] R7=[%04x]\n", ins, registers[PC].word, acc, register_read_word(3), register_read_word(7));
                debug_mode(SINGLESTEP);
            }
        }

        if ((register_read_word(PC) >= 0xe000) && (register_read_word(PC) <= 0xEFFF)) {
            for (int t = 3; t < jsrdepth; t++)
                DEBUG_PRINTF("->");
            DEBUG_PRINTF("Process opcode [%02x] at [%04x] acc=[%02x] R3=[%04x] R7=[%04x]\n", ins, registers[PC].word, acc, register_read_word(3), register_read_word(7));
        }

        register_inc(PC);
        switch (ins) {
            case START:
                badOpcode(ins);
                break;

            case ON:
                out_on();
                break;

            case OFF:
                out_off();
                break;

            case YHALT:
                printf("\nHalt[%02x] at [%04x] acc=[%02x] tmp=[%02x] R3=[%04x] R7=[%04x]\n", ins, registers[PC].word - 1, acc, treg, register_read_word(3), register_read_word(7));
                dump(0x0200, 0x021f);
                dump(0x0f80, 0x0f8f);
                dump(0x0400, 0x040F);
                dump(0x1000, 0x1020);
                debug_mode(HALT);
                break;

            case JSR:
                jsrdepth++;
                hi = memory_read(register_read_word(PC));
                register_inc(PC);
                lo = memory_read(register_read_word(PC));
                register_inc(PC);

                DEBUG_PRINTF("JSR pc=%04x sp=%04x jsrd=%d %02x%02x\n", (register_read_word(PC) - 3), register_read_word(SP), jsrdepth, hi, lo);
                //dump(0xdump0200, 0x020f);
                memory_write(register_read_word(SP), register_read_hi(PC));
                register_dec(SP);
                memory_write(register_read_word(SP), register_read_lo(PC));
                register_dec(SP);

                register_write_hi(PC, hi);
                register_write_lo(PC, lo);

                //printf("jsr opcode pc[%04x]\n", registers[PC].word);
                break;

            case RET:
                jsrdepth--;
                DEBUG_PRINTF("RET pc=%04x sp=%04x jsrd=%d ", (register_read_word(PC) - 1), register_read_word(SP), jsrdepth);
                //dump(0x0200, 0x020f);
                register_inc(SP);
                register_write_lo(PC, memory_read(register_read_word(SP)));
                register_inc(SP);
                register_write_hi(PC, memory_read(register_read_word(SP)));


                DEBUG_PRINTF(" return to %02x%02x\n", register_read_hi(PC), register_read_lo(PC));

                break;

            case JSRUR:
                jsrdepth++;
                reg = memory_read(register_read_word(PC)) & 0x07;
                register_inc(PC);

                DEBUG_PRINTF("JSR pc=%04x sp=%04x jsrd=%d %02x%02x\n", (register_read_word(PC) - 3), register_read_word(SP), jsrdepth, hi, lo);
                //dump(0xdump0200, 0x020f);
                memory_write(register_read_word(SP), register_read_hi(PC));
                register_dec(SP);
                memory_write(register_read_word(SP), register_read_lo(PC));
                register_dec(SP);

                register_write_hi(PC, register_read_lo(reg));
                register_write_lo(PC, register_read_hi(reg));

                //printf("jsr opcode pc[%04x]\n", registers[PC].word);
                //printf("bad opcode [%02x] pc[%04x]\n", ins, register_read_word(PC));
                break;

            case PUSHR:
                reg = memory_read(register_read_word(PC)) & 0x07;
                register_inc(PC);
                //DEBUG_PRINTF("PUSHR reg=%d pc=%04x pre-sp=%04x\n", reg, (register_read_word(PC) - 1), register_read_word(SP));
                memory_write(register_read_word(SP), register_read_hi(reg));
                register_dec(SP);
                memory_write(register_read_word(SP), register_read_lo(reg));
                register_dec(SP);
                break;

            case POPR:
                reg = (memory_read(register_read_word(PC)) >> 4) & 0x07;
                register_inc(PC);
                //DEBUG_PRINTF("POPR reg=%d pc=%04x pre-sp=%04x\n", reg, (register_read_word(PC) - 1), register_read_word(SP));
                register_inc(SP);
                register_write_lo(reg, memory_read(register_read_word(SP)));
                register_inc(SP);
                register_write_hi(reg, memory_read(register_read_word(SP)));
                break;

            case PUSH:
                pushpopdepth++;
                //DEBUG_PRINTF("PUSH pc=%04x pre-sp=%04x ppd=%d\n", (register_read_word(PC) - 1), register_read_word(SP), pushpopdepth);
                memory_write(register_read_word(SP), acc_read());
                register_dec(SP);
                break;

            case POP:
                pushpopdepth--;
                //DEBUG_PRINTF("POP pc=%04x pre-sp=%04x ppd=%d\n", (register_read_word(PC) - 1), register_read_word(SP), pushpopdepth);
                register_inc(SP);
                acc_write(memory_read(register_read_word(SP)));
                break;

            case MVAT:
                treg = acc;
                break;

            case MVTA:
                acc = treg;
                break;

            case LDTI:
                treg = memory_read(register_read_word(PC));
                register_inc(PC);
                break;

            case LDAI:
                acc = memory_read(register_read_word(PC));
                register_inc(PC);
                break;

            case MOVRR:
                reg = memory_read(register_read_word(PC));
                register_inc(PC);
                src = reg & 0x0f;
                dest = (reg >> 4) & 0x0f;
                register_write_word(dest, register_read_word(src));
                break;

            case MVIB + REG0:
            case MVIB + REG1:
            case MVIB + REG2:
            case MVIB + REG3:
            case MVIB + REG4:
            case MVIB + REG5:
            case MVIB + REG6:
            case MVIB + REG7:
                reg = ins & 0x07;
                register_write_lo(reg, memory_read(register_read_word(PC)));
                register_inc(PC);
                break;

            case MVIW + REG0:
            case MVIW + REG1:
            case MVIW + REG2:
            case MVIW + REG3:
            case MVIW + REG4:
            case MVIW + REG5:
            case MVIW + REG6:
            case MVIW + REG7:
                reg = ins & 0x07;
                register_write_hi(reg, memory_read(register_read_word(PC)));
                register_inc(PC);
                register_write_lo(reg, memory_read(register_read_word(PC)));
                register_inc(PC);
                break;

            case MVRLA + REG0:
            case MVRLA + REG1:
            case MVRLA + REG2:
            case MVRLA + REG3:
            case MVRLA + REG4:
            case MVRLA + REG5:
            case MVRLA + REG6:
            case MVRLA + REG7:
                reg = ins & 0x07;
                acc_write(register_read_lo(reg));
                break;

            case MVRHA + REG0:
            case MVRHA + REG1:
            case MVRHA + REG2:
            case MVRHA + REG3:
            case MVRHA + REG4:
            case MVRHA + REG5:
            case MVRHA + REG6:
            case MVRHA + REG7:
                reg = ins & 0x07;
                acc_write(register_read_hi(reg));
                break;

            case MVARL + REG0:
            case MVARL + REG1:
            case MVARL + REG2:
            case MVARL + REG3:
            case MVARL + REG4:
            case MVARL + REG5:
            case MVARL + REG6:
            case MVARL + REG7:
                reg = ins & 0x07;
                register_write_lo(reg, acc_read());
                break;

            case MVARH + REG0:
            case MVARH + REG1:
            case MVARH + REG2:
            case MVARH + REG3:
            case MVARH + REG4:
            case MVARH + REG5:
            case MVARH + REG6:
            case MVARH + REG7:
                reg = ins & 0x07;
                register_write_hi(reg, acc_read());
                break;

            case LDAVR + REG0:
            case LDAVR + REG1:
            case LDAVR + REG2:
            case LDAVR + REG3:
            case LDAVR + REG4:
            case LDAVR + REG5:
            case LDAVR + REG6:
            case LDAVR + REG7:
                reg = ins & 0x07;
                acc = memory[registers[reg].word];
                break;

            case STAVR + REG0:
            case STAVR + REG1:
            case STAVR + REG2:
            case STAVR + REG3:
            case STAVR + REG4:
            case STAVR + REG5:
            case STAVR + REG6:
            case STAVR + REG7:
                reg = ins & 0x07;
                memory[registers[reg].word] = acc;
                break;

            case INCR + REG0:
            case INCR + REG1:
            case INCR + REG2:
            case INCR + REG3:
            case INCR + REG4:
            case INCR + REG5:
            case INCR + REG6:
            case INCR + REG7:
                reg = ins & 0x07;
                registers[reg].word++;
                break;

            case DECR + REG0:
            case DECR + REG1:
            case DECR + REG2:
            case DECR + REG3:
            case DECR + REG4:
            case DECR + REG5:
            case DECR + REG6:
            case DECR + REG7:
                reg = ins & 0x07;
                registers[reg].word--;
                break;

            case OUTA + PORT0:
            case OUTA + PORT1:
            case OUTA + PORT2:
            case OUTA + PORT3:
            case OUTA + PORT4:
            case OUTA + PORT5:
            case OUTA + PORT6:
            case OUTA + PORT7:
            case OUTA + PORT8:
            case OUTA + PORT9:
            case OUTA + PORT10:
            case OUTA + PORT11:
            case OUTA + PORT12:
            case OUTA + PORT13:
            case OUTA + PORT14:
            case OUTA + PORT15:
                portaddr = ins & 0x0f;
                port[portaddr] = acc;
                if (portaddr == 2) {
                    myputchar(port[portaddr]);
                    DEBUG_PRINTF(" ");
                }
                break;

            case OUTI + PORT0:
            case OUTI + PORT1:
            case OUTI + PORT2:
            case OUTI + PORT3:
            case OUTI + PORT4:
            case OUTI + PORT5:
            case OUTI + PORT6:
            case OUTI + PORT7:
            case OUTI + PORT8:
            case OUTI + PORT9:
            case OUTI + PORT10:
            case OUTI + PORT11:
            case OUTI + PORT12:
            case OUTI + PORT13:
            case OUTI + PORT14:
            case OUTI + PORT15:
                portaddr = ins & 0x0f;
                port[portaddr] = memory_read(register_read_word(PC));
                register_inc(PC);


                if ((port[0] == 0x40) && (portaddr == 1))
                    myputchar(port[portaddr]);
                break;
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

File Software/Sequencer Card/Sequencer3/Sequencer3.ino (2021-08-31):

// Sequencer Memory card code
// Mode Determined by UCODESWITCH
//Mode 1 download uCode from serial line and store in EEPROM, press STARTSWITCH to begin (READY and LOADING LEDs ON)
//MODE 2 Write EEPROM into UCode RAM and set READY line high


#include <Wire.h> //I2C library
#include "Adafruit_MCP23017.h"
//#include "YACC_Common_headera.h"

/*
   Format ":AIXXXXXXXX....XXXXX"
   ":"  Start charachter
   "A" Checksum (not including instruction number) (Ignore for now)
   "I" Instruction Number (0-255)- 2 hex ascii chars
   "XXXXXXXX....XXXXX" Data Bytes -  2 hex ascii chars

  Pin 11 FAULT
  Pin 12 Bus-EN READY
  Pin 13 Loading
*/

//RAM Control Lines
#define MEMWR 8
#define MEMRD 9
#define MEMSEL 10

// LEDS
#define FAULT 11
#define READY 12
#define LOADING 13

//Swithces
#define UCODESWITCH A0
#define STARTSWITCH A2 // Default HIGH

//
#define READYLINE 7

//UCODESWITCH Modes
#define DOWNLOAD 0
#define WRITEMEM 1

int mode;
int verbose = 0;

#define LINES_PER_INSTRUCTION 64  // total number of rows of BYTES_PER_LINE
#define BYTES_PER_LINE 8         // total bytes/row (mem chips) should be 8
#define INSTRUCTION_SIZE  BYTES_PER_LINE*LINES_PER_INSTRUCTION

#define WORKING_INSTRUCTION_SET  256  // FIX shoud be 256
#define ALL_INSTRUCTIONS 256

#define NUMBER_OF_CONTROLERS 5
#define ADDRESS_CHIP 0
#define DATA_CHIP_START 1
#define DATA_CHIPS 4

Adafruit_MCP23017 mcp[NUMBER_OF_CONTROLERS];
unsigned char insData[BYTES_PER_LINE * LINES_PER_INSTRUCTION] = {0,};

void writeCodeToROM(int, unsigned char *);

//opcode myArraySRAM;



void doError(String errorMsg, int code) {
  ///Serial.print("Error: ");
  ///Serial.println(errorMsg);
  while (1) {
    for (int i = 0; i < code; i++)
      blinkLed(FAULT);
    delay(2000);
  }
}

void flashLed(int led) {
  digitalWrite(led, HIGH);
  delay(100);
  digitalWrite(led, LOW);
}

void blinkLed(int led) {
  digitalWrite(led, HIGH);
  delay(100);
  digitalWrite(led, LOW);
  delay(100);
}

/*
   Test Pattern, for each line of instruction - BYTE 0 instruction #, BYTE 1, LINE #, remaining 0s
*/
void fillTestPattern(int instruction) {
  int i, j;

  if (verbose > 0) {
    Serial.print("Filling Memory - ");
    Serial.println(instruction);
  }

  for (i = 0; i < LINES_PER_INSTRUCTION; i++) {
    insData[i * BYTES_PER_LINE] = instruction;
    insData[i * BYTES_PER_LINE + 1] = i;
    for (j = 2; j < BYTES_PER_LINE; j++) {
      insData[i * BYTES_PER_LINE + j] = 0;
    }
  }
  writeInstruction(instruction, insData);

}

/*
   Read instruction from RAM
*/
void dumpInstruction(int instruction) {
  int i, j;
  char tmp[20];

  Serial.print("Ins=");
  Serial.println(instruction);

  Serial.print("        ");
  for (i = 0; i < BYTES_PER_LINE; i++) {
    sprintf(tmp, "%02x ", i); Serial.print(tmp);
  }
  Serial.println();

  readInstruction(instruction, insData);
  for (j = 0; j < LINES_PER_INSTRUCTION; j++) {
    sprintf(tmp, "LINE:%02d ", j); Serial.print(tmp);
    for (i = 0; i < BYTES_PER_LINE; i++) {
      sprintf(tmp, "%02x ", insData[i + j * BYTES_PER_LINE]); Serial.print(tmp);
    }
    Serial.println();
  }
  Serial.println();

  readCodeFromROM(instruction, insData);
  for (j = 0; j < LINES_PER_INSTRUCTION; j++) {
    sprintf(tmp, "LINE:%02d ", j); Serial.print(tmp);
    for (i = 0; i < BYTES_PER_LINE; i++) {
      sprintf(tmp, "%02x ", insData[i + j * BYTES_PER_LINE]); Serial.print(tmp);
    }
    Serial.println();
  }
  Serial.println();
}

void setup() {
  int i;

  Serial.begin(115200);
  Wire.begin();

  pinMode(UCODESWITCH, INPUT);
  mode = digitalRead(UCODESWITCH);


  if (mode == WRITEMEM)
    Serial.println("\n\n\n\nStartup");

  for (i = 0; i < NUMBER_OF_CONTROLERS; i++) {
    mcp[i].begin(i);
  }


  pinMode(FAULT, OUTPUT);
  pinMode(READY, OUTPUT);
  pinMode(LOADING, OUTPUT);
  pinMode(READYLINE, OUTPUT);

  pinMode(MEMRD, OUTPUT);
  pinMode(MEMWR, OUTPUT);
  pinMode(MEMSEL, OUTPUT);

  digitalWrite(MEMRD, HIGH);
  digitalWrite(MEMWR, HIGH);
  digitalWrite(MEMSEL, HIGH);
  digitalWrite(READYLINE, LOW);

  pinMode(UCODESWITCH, INPUT);
  pinMode(STARTSWITCH, INPUT);

  flashLed(FAULT);
  flashLed(READY);
  flashLed(LOADING);

  if (mode == WRITEMEM)
    Serial.println("Startup done\n");
}

void loop() {

  int address;
  int rawaddress;
  int line;
  int instruction;
  unsigned char data[BYTES_PER_LINE];
  unsigned int counter;
  char tmp[60];
  boolean statusLed = false;
  int i, j;

  int previousLine;
  int previousInstruction;
  unsigned char previousData[8];
  unsigned char mask;
  int val;

  //bool printed=false;

  if (mode == WRITEMEM) { // LOADING on while copying, READY on when complete

    Serial.println("Write Memory");

#define FILLRAM
#ifdef FILLRAM
    Serial.println("test pattern");

    setAddressOutput();
    setDataOutput();

    for (instruction = 0; instruction < ALL_INSTRUCTIONS; instruction++) {
      digitalWrite(LOADING, statusLed);
      statusLed = !statusLed;
      fillTestPattern(instruction);
    }
    Serial.println("- done");
#endif

#define ROMTORAM
#ifdef ROMTORAM
    Serial.println("EEPROM to RAM");
    digitalWrite(LOADING, HIGH);
    setAddressOutput();
    setDataOutput();

    for (instruction = 0; instruction < WORKING_INSTRUCTION_SET; instruction++) {
      Serial.print("Copying Instruction ");
      Serial.println(instruction);

      digitalWrite(LOADING, statusLed);
      statusLed = !statusLed;

      readCodeFromROM(instruction, insData);
      writeInstruction(instruction, insData);
    }
    Serial.println("- done");
#endif


#define DISPLAY_MEM
#ifdef DISPLAY_MEM
    // Set all lines to input, therefore can be driven by logic card
    setDataInput();
    setAddressOutput();
    uCodeRamRead(true);
    uCodeRamSelect(true);

    dumpInstruction(0);
    dumpInstruction(1);
    dumpInstruction(7);
    //dumpInstruction(6);
    dumpInstruction(124);
    dumpInstruction(255);
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

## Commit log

2020-08-23 Adding folder contents
    [ALU V3.1.brd, ALU V3.1.csv, ALU V3.1.sch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]
2020-08-28 Create clocker.ino
    Arduino app to assist in single stepping through microcode one line or one instruction at a time
2020-08-28 Index Register Board V1.1
    Modify so any data register can drive address bus
    [Index Registers - 1.1.brd, Index Registers - 1.1.sch]
2020-09-01 New Index board with addition for each register to drive address bus
    [Index Registers - 1.1.brd, Index Registers - 1.1.csv, Index Registers - 1.1.sch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]
2020-09-01 New index register design, each register can drive address bug
    [silkscreen_top.gbr]
2020-09-01 New memory card, switch to 8k eeprom add in tmp registers
    [Memory V1.0.brd, Memory V1.0.sch, Memory V1.2.brd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]
2020-09-01 new memory card, switch to eeprom, add tmp register
2020-09-01 Ongoing development
    [Index Registers - 1.1.brd, Index Registers - 1.1.csv, Index Registers - 1.1.sch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]
2020-09-22 cleanup uart ready to xmit code
2020-09-22 testing gitignore
    [Address and TMP V1.0.sch]
2020-09-22 Add link to arduino header file
    Place in Arduino/linraries/YACC (usually of of ~/Documents)
2020-09-24 cleanup production PCB area , add photos
    [ALU V3.1.brd, ALU V3.1.csv, ALU V3.1.sch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]
2020-09-25 Added build notes for system and indivdual boards
2020-09-25 Moved test board into production area
    [switchtemplate.skp, tester.brd, tester.sch]
2020-09-26 rename original 1.0 index register
    [Index Registers - 1.0.brd, Index Registers - 1.0.sch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]
2020-09-27 adding bus driver CLI reference
2020-10-11 adding board layout PDFs to PCB production directories
2020-10-17 original code test bed
2020-10-31 Update assembler
2020-11-20 Fix FOR-NEXT, FIX keyword search
    [basic.asm, main.c]
2020-11-23 Next version of ALU to production
    [ALU V3.1.brd, ALU V3.2.brd, ALU V3.2.csv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]
2020-11-23 pre fix unary negative
    [basic.asm, main.c]
2020-11-29 Rename Connector C3-C6, ADDR-REG-ID0-3
    Rename Connector C3-C6, ADDR-REG-ID0-3
    [ALU V3.2.brd, ALU V3.2.sch]
2020-11-29 Deleted Not ready for production
    [Sequencer-Memory-V1.0-1.brd, Sequencer-Memory-V1.0-1.sch, Sequencer-Memory-V1.0-2.brd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]
2020-11-29 No longer used moved to old & obsolete
    [Index Registers - 1.0.brd, Index Registers - 1.0.sch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]
2020-11-29 Fix signals in bus
    [ALU V3.2.sch]
2020-11-29 cleanup bus names
    [Memory V1.2.brd, Memory V1.2.sch]
2020-11-29 cleanup bus
    [ALU V3.2.sch]
2020-11-29 Cleanup Bus signals
    [IO V1.1.brd, IO V1.1.sch]
2020-11-29 Never used
    [ALU V3.2.brd, ALU V3.2.csv, ALU V3.2.sch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]
2020-11-29 Interrupt mgmt code and tests
2020-12-02 v2.1 sequencer logic & memory
    [Sequencer-Logic-Prod-V2.1 copy.brd, Sequencer-Logic-Prod-V2.1 copy.sch, Sequencer-Logic-Prod-V2.1.brd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]
2020-12-02 development sequencer & alu
    [ALU V3.2.brd, ALU V3.2.csv, ALU V3.2.sch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]
2020-12-02 missing rebuilt from pre github backup
    [Sequencer-Memory-V1.0-1.brd, Sequencer-Memory-V1.0-1.sch, Sequencer-Memory-V1.0-2.brd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]
2020-12-25 add a second 512k bit eeprom to 328 chip
    [eeprom adaptor.brd, eeprom adaptor.sch]
2021-01-05 Cleanup memory card files
    [Memory V1.0.brd, Memory V1.0.sch, Memory V1.2.brd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]
2021-03-18 cleaning up paths
    [Memory V1.3.brd, Memory V1.3.sch]
2021-07-10 Version 1 of dip-switch memory board
    [Mem Switch V1.0.brd, Mem Switch V1.0.sch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]
2021-07-11 Move mem switch v1.0 into production
    [Mem Switch V1.0.brd, Mem Switch V1.0.sch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]
2021-08-29 12 inch 8 sided bus board
    [copper_inner_l2.gbr, copper_inner_l3.gbr, copper_top_l1.gbr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]
2021-08-29 Register based 16 byte memory card
    [Mem Register V1.0.brd, Mem Register V1.0.sch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]
2021-08-29 missed git sync of this card - 8 sided bus board file
    [copper_bottom_l4.gbr]
2021-08-29 missed git sync - register based 16 byte memory card
    [soldermask_bottom.gbr]
2021-08-29 v1.1 16 byte switch based programmable ROM card
    [Mem Switch V1.1.brd, Mem Switch V1.1.sch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]
2021-08-29 8 sided bus board
    [copper_bottom_l4.gbr, copper_inner_l2.gbr, copper_inner_l3.gbr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]
2021-08-29 sync up
    [Mem Register V1.0.brd, Mem Register V1.0.sch, Mem Switch V1.1.brd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]
2021-08-31 fix instruction decode logic for larger address space
    [Sequencer3.ino]
2021-09-01 Add 3d printed files - first board spacers for octagon bus board
    [clip.skp, clip12.skp, clip12.stl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]
2021-09-02 not working needs revert
    [basic.asm, monitor.asm]

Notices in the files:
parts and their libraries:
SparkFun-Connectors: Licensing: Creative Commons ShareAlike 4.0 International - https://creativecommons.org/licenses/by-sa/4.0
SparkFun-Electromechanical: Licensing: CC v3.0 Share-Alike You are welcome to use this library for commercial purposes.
